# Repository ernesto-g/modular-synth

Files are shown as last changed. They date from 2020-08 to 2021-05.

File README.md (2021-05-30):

# Modular synthesizer

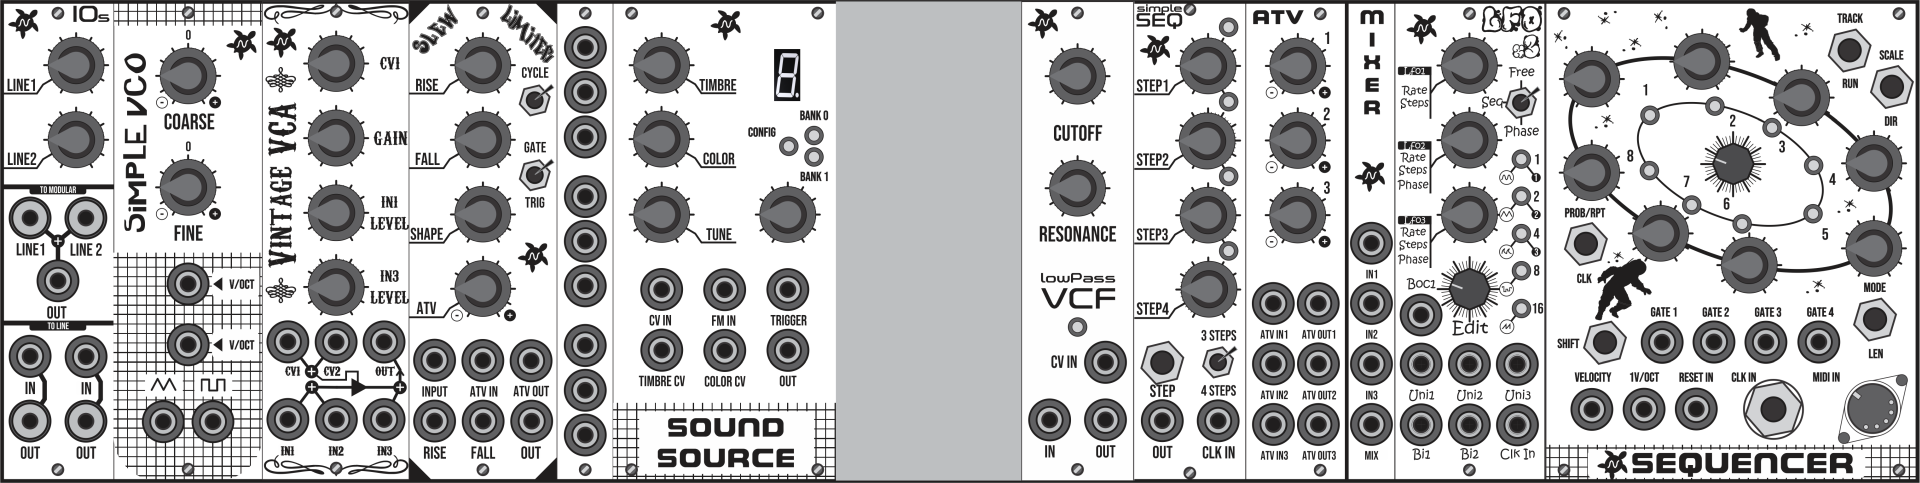
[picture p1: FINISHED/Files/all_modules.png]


Characteristics:

  - Eurorack form factor modules
  - Banana jack connectors
  - 10Vpp audio signals
  - 5V control signals
  - Non standard power connector

# Finished modules

  - [Sequencer](https://github.com/ernesto-g/modular-synth/tree/master/FINISHED/SEQUENCER): 8-step sequencer.
  - [Vintage VCA](https://github.com/ernesto-g/modular-synth/tree/master/FINISHED/VCA): 2-transistor discrete VCA.
  - [Simple VCO](https://github.com/ernesto-g/modular-synth/tree/master/FINISHED/VCO): Triangle and square VCO. 1V/Ocv control voltage.
  - [Slew limiter](https://github.com/ernesto-g/modular-synth/tree/master/FINISHED/SLEW_LIMITER): Slew limiter and LFO
  - [IOs](https://github.com/ernesto-g/modular-synth/tree/master/FINISHED/IOS): Audio line and Eurorack level adapter.
  - [Power Supply](https://github.com/ernesto-g/modular-synth/tree/master/FINISHED/POWER_SUPPLY): Power Supply Board for modules.
  - [Tree](https://github.com/ernesto-g/modular-synth/tree/master/FINISHED/TREE): Banana jack splitter.
  - [Sound Source](https://github.com/ernesto-g/modular-synth/tree/master/FINISHED/SOUND_SOURCE): Macro-oscillator based on Mutable Instruments Braids.
  - [LFOx3](https://github.com/ernesto-g/modular-synth/tree/master/FINISHED/LFOx3): Low frequency oscillator and sequencer.
  - [ATV & Mixer](https://github.com/ernesto-g/modular-synth/tree/master/FINISHED/ATVMixer): Atenuverter X3 and 3-channel mixer.
  - [Simple Sequencer](https://github.com/ernesto-g/modular-synth/tree/master/FINISHED/SIMPLE_SEQUENCER): 4-step sequencer.
  - [Low Pass VCF](https://github.com/ernesto-g/modular-synth/tree/master/FINISHED/VCF): Vactrol VCF.

# Unfinished work

  - Industrial kick
  - Case blueprints
  
# Project structure

Each module has the following structure:

  * Firmware: Microcontroller code (Arduino, Bluepill,etc.)
  * Manual: PDF and DOC file
  * XXXXXXX_modular_PCB: Folder
    * XXXXXXX_modular: Kicad project
    * DIY: PDF files for schematic, PCB and front panel
  * Front Panel Blueprint: Corel Draw files

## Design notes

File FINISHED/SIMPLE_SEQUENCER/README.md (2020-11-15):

# Simple Sequencer: 4-step sequencer

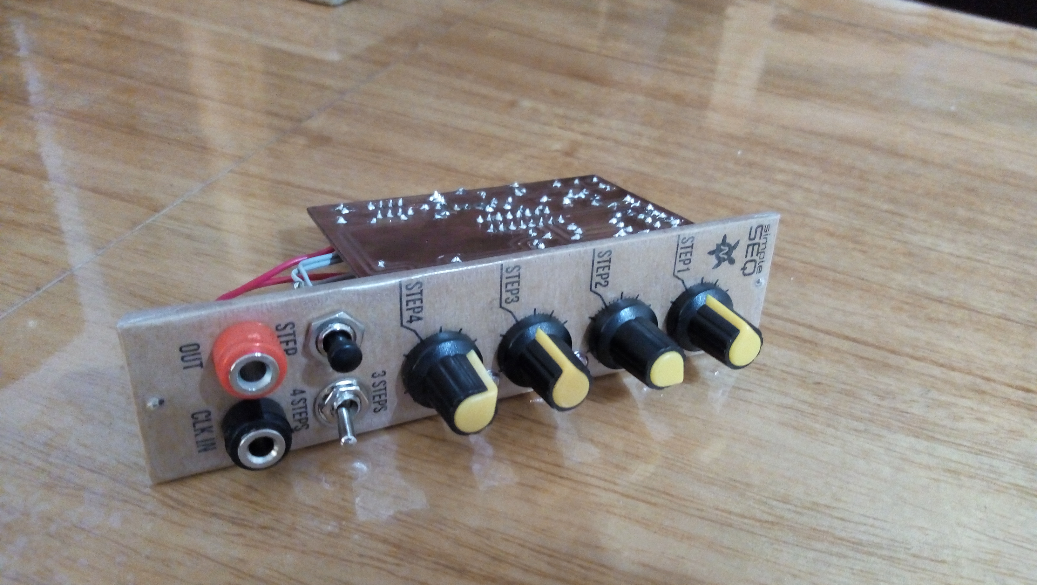
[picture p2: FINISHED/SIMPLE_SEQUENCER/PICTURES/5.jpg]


Characteristics:

  - Format: Eurorack
  - Dimensions: 6HP, 60mm deep
  - 4-step or 3-step selector
  - 0V to 6V output range
  - Manual step advance
  - Clock input 0-12V / 0-5V

# Project structure

  * SIMPLE_SEQUENCER_modular_PCB: Folder
    * SIMPLE_SEQUENCER_modular: Kicad project
    * DIY: PDF files for schematic, PCB and front panel
  * Front Panel Blueprint: Corel Draw files

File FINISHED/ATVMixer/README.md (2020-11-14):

# Atenuverters & 3-channel mixer

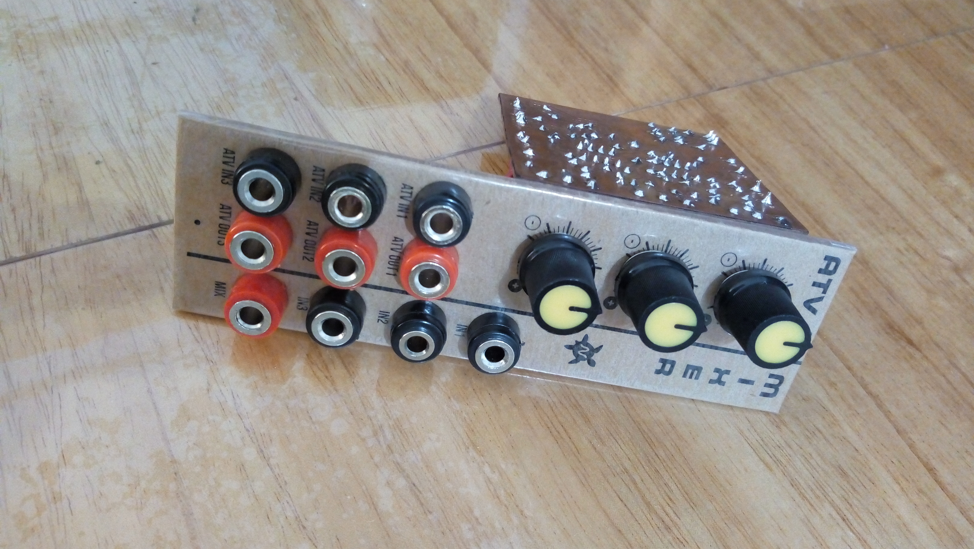
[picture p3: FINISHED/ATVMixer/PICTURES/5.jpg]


Characteristics:

  - Format: Eurorack
  - Dimensions: 8HP, 60mm deep
  - 10Vpp audio signals

# Project structure

  * ATV_AND_MIXER_modular_PCB: Folder
    * ATV_AND_MIXER_modular: Kicad project
    * DIY: PDF files for schematic, PCB and front panel
  * Front Panel Blueprint: Corel Draw files

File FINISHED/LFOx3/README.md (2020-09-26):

# LFOx3: Low frequency oscillator
LFOx3 is a 3 channel digital low frequency oscillator module.

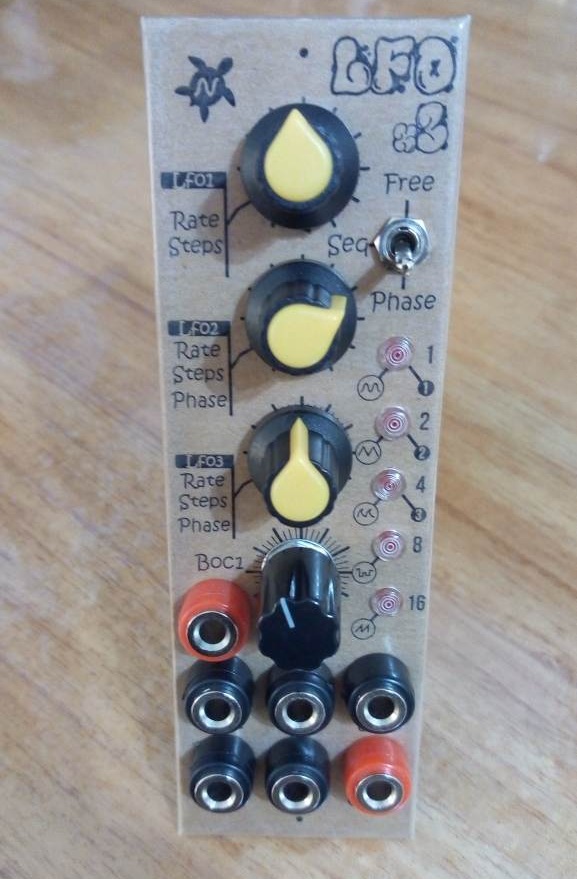
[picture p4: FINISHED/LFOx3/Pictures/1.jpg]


Characteristics:

  - Format: Eurorack
  - Dimensions: 8HP, 60mm deep
  - 10Vpp audio signals
  - 5V control signals
  - 5 Waveforms
  - 105sec to 150Hz range.
  - 10kHz, 8-bit audio processing
  - Beginning of cycle Output.

Download [manual](https://github.com/ernesto-g/modular-synth/raw/master/FINISHED/LFOx3/Manual/LFOx3%20Manual.pdf)   
 
# Project structure

  * Firmware: Code for Arduino nano
  * Manual: PDF and DOC file
  * LFO_modular_PCB: Folder
    * LFO_modular: Kicad project
    * DIY: PDF files for schematic, PCB and front panel
  * Front Panel Blueprint: Corel Draw files

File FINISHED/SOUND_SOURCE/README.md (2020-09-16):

# Sound Source: Macro-oscillator
Sound Source is a voltage-controlled monophonic digital oscillator. Each algorithm is controlled by two continuously variable parameters, TIMBRE and COLOR, both of them voltage controllable.

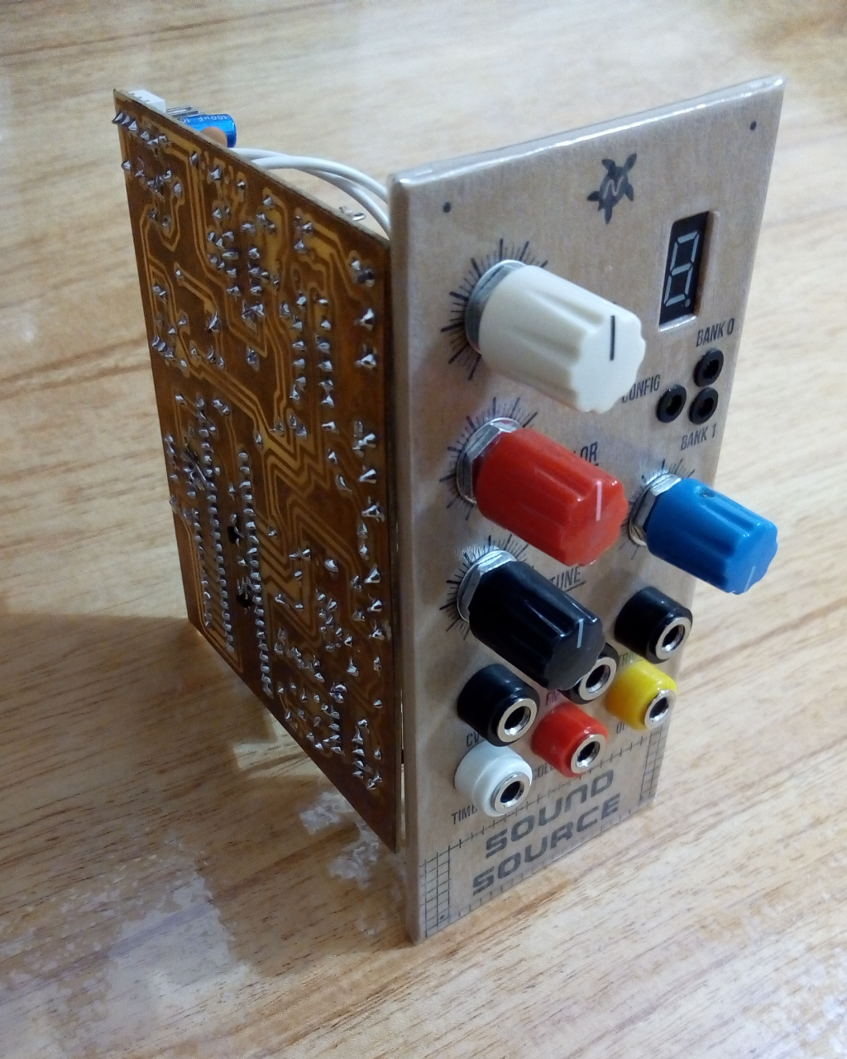
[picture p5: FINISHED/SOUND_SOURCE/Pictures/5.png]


This project is based on Mutable Intruments [Braids](https://mutable-instruments.net/modules/braids). 
The code was adapted for [Blue Pill](https://stm32-base.org/boards/STM32F103C8T6-Blue-Pill.html) microcontroller.

Characteristics:

  - Format: Eurorack
  - Dimensions: 12HP, 80mm deep
  - 10Vpp audio signals
  - 5V control signals
  - 43 Waveforms
  - 96kHz, 8-bit audio processing
  - 12-bit CV capture.

Download [manual](https://github.com/ernesto-g/modular-synth/raw/master/FINISHED/SOUND_SOURCE/Manual/Sound%20Source%20Manual.pdf)   
 
# Project structure

  * Firmware: Code for Blue Pill using ST Cube IDE
  * Manual: PDF and DOC file
  * SOUND_SOURCE_modular_PCB: Folder
    * SOUND_SOURCE_modular: Kicad project
    * DIY: PDF files for schematic, PCB and front panel
  * Front Panel Blueprint: Corel Draw files

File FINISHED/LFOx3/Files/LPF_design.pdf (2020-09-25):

Design Name: Lowpass, Sallen Key, ButterworthPart: Ideal Opamp Order: 2 Stages: 1
Gain: 1 V/V ( 0 dB) | Allowable PassBand Ripple: 1 dB | Passband Frequency: 1 kHz
Corner Frequency Attenuation: -3 dB

## FilterPro Design Report

## Schematic

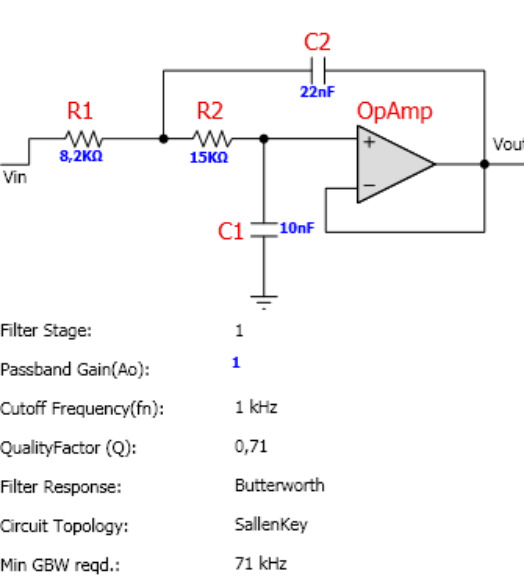
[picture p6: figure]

jueves, 17 de septiembre de 2020 12:45:56 a.m. | -1-

### FilterPro

## Frequency and Phase Responses

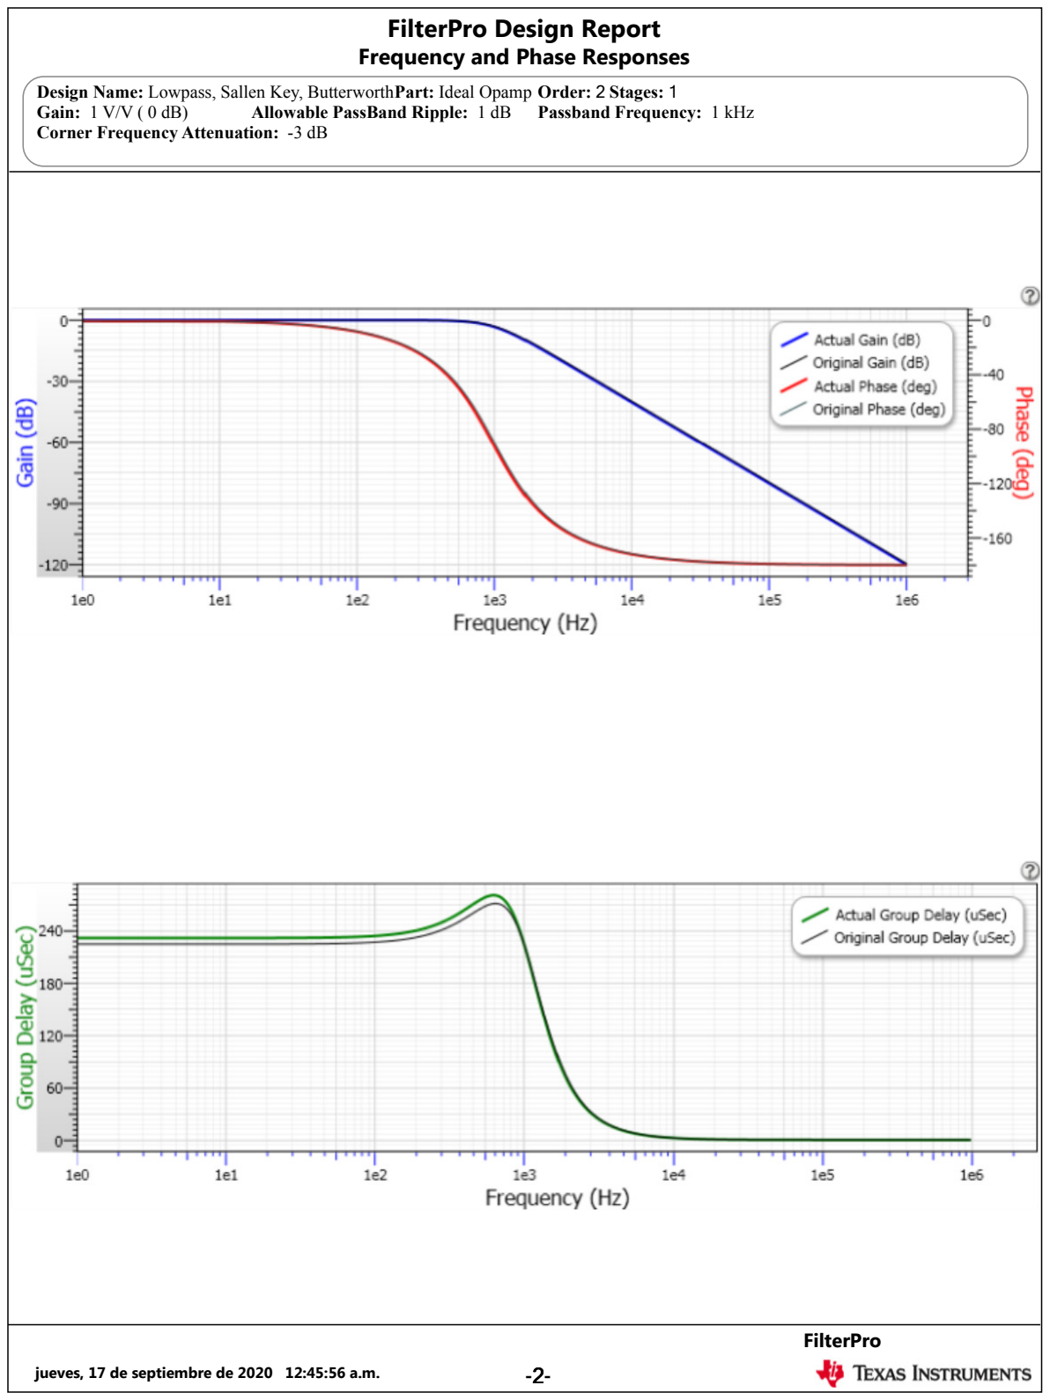
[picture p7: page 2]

Gain: 1 V/V ( 0 dB) | Allowable PassBand Ripple: 1 dB | Passband Frequency: 1 kHz
Corner Frequency Attenuation: -3 dB
jueves, 17 de septiembre de 2020 12:45:56 a.m. | -2-

Gain: 1 V/V ( 0 dB) | Allowable PassBand Ripple: 1 dB | Passband Frequency: 1 kHz
Corner Frequency Attenuation: -3 dB

## Bill of Materials

jueves, 17 de septiembre de 2020 12:45:56 a.m. | -3-
Element ID | Quantity | Part Number | Value | Tolerance | Description | Manufacturer
R1 (Stage 1) | 1 | Standard | 8,2KΩ | E12: 10% | Resistor
R2 (Stage 1) | 1 | Standard | 15KΩ | E12: 10% | Resistor
C1 (Stage 1) | 1 | Standard | 10nF | E6: 20% | Capacitor
C2 (Stage 1) | 1 | Standard | 22nF | E6: 20% | Capacitor
OpAmp (Stage 1) | 1 | Standard | | | Ideal OpAmp

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

## Design Notes

jueves, 17 de septiembre de 2020 12:45:56 a.m. | -4-

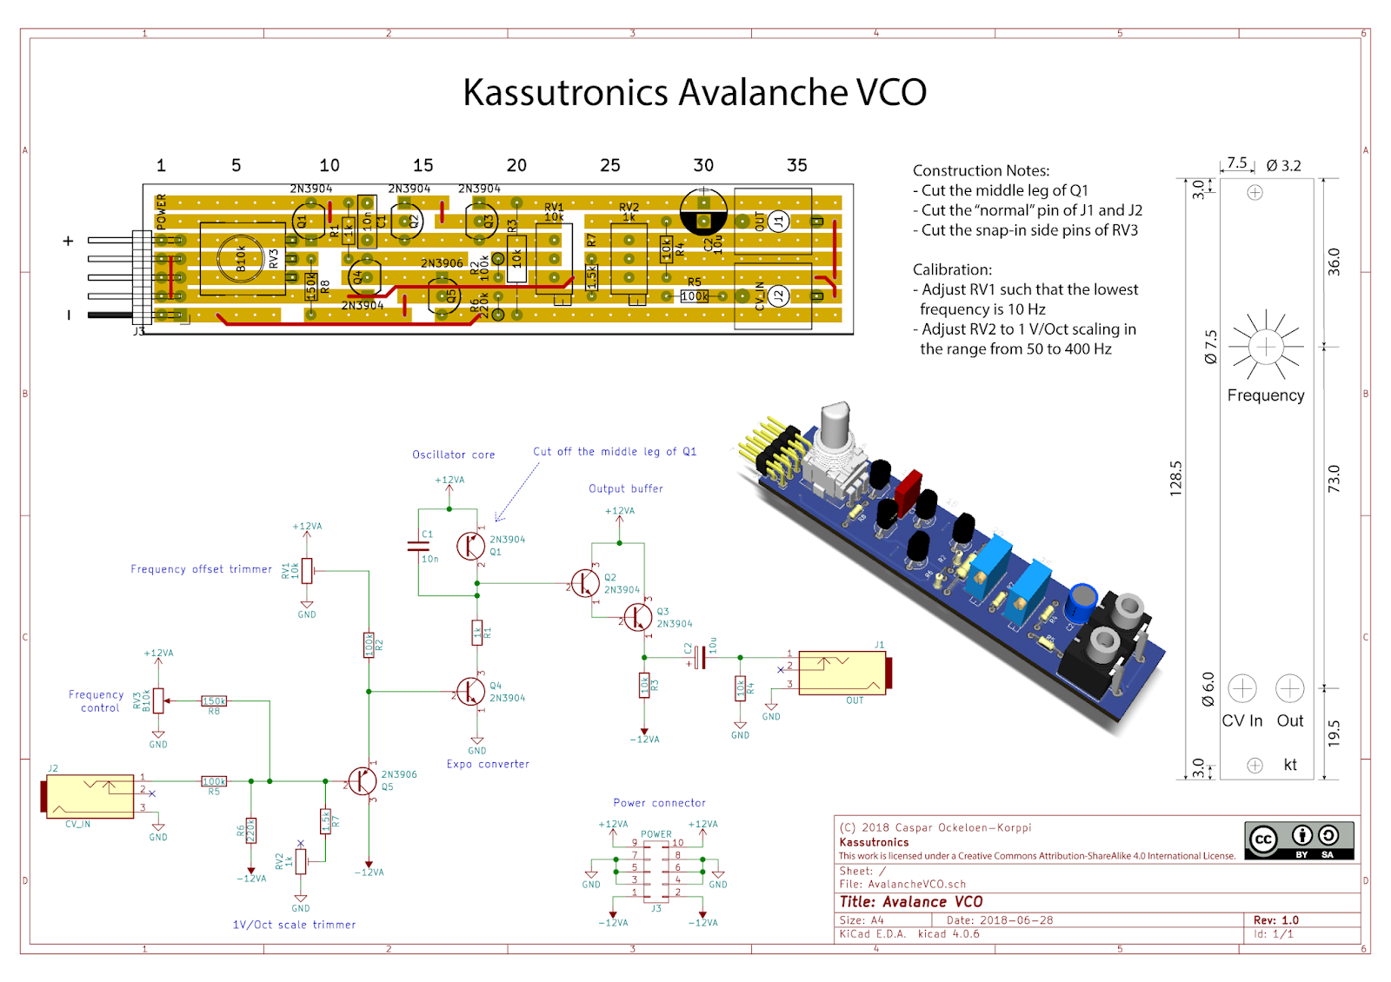
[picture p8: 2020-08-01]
UNFINISHED/INDUSTRIAL_KICK/AvalanceVCOSchematics.png

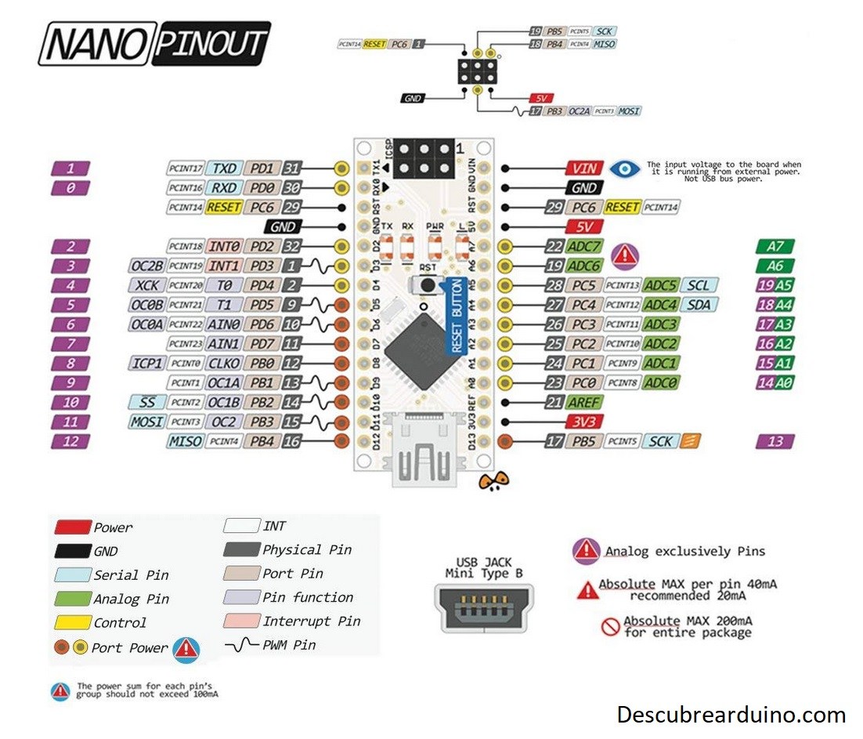
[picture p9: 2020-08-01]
FINISHED/SEQUENCER/SEQUENCER_modular_PCB/SEQUENCER_modular/Datasheets/arduino-nano-pinout.jpg

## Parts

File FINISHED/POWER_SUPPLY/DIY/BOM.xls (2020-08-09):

Reference | Value | Footprint | Qty
> C1, C2 | 2200uFx25V | Capacitors_ThroughHole:CP_Radial_D13.0mm_P5.00mm | 2
> C3, C4 | 220nF | Capacitors_ThroughHole:C_Disc_D11.0mm_W5.0mm_P7.50mm | 2
> C5, C6 | 100nF | Capacitors_ThroughHole:C_Disc_D5.0mm_W2.5mm_P5.00mm | 2
> C7, C8 | 1000uFx16V | Capacitors_ThroughHole:CP_Radial_D8.0mm_P3.50mm | 2
D1 | KBP210 2Amp | Diode_THT:Diode_Bridge_Vishay_KBU | 1
> D2, D3 | 1N4007 | Diode_THT:D_DO-41_SOD81_P10.16mm_Horizontal | 2
J1 | AC INPUT 12+12 1.5A | Terminal_Blocks:TerminalBlock_Altech_AK300-3_P5.00mm | 1
J2 | OUT1 | Connectors_Molex:Molex_KK-6410-03_03x2.54mm_Straight | 1
J3 | OUT2 | Connectors_Molex:Molex_KK-6410-03_03x2.54mm_Straight | 1
J4 | OUT3 | Connectors_Molex:Molex_KK-6410-03_03x2.54mm_Straight | 1
J5 | OUT4 | Connectors_Molex:Molex_KK-6410-03_03x2.54mm_Straight | 1
J6 | OUT5 | Connectors_Molex:Molex_KK-6410-03_03x2.54mm_Straight | 1
J7 | OUT6 | Connectors_Molex:Molex_KK-6410-03_03x2.54mm_Straight | 1
J8 | OUT7 | Connectors_Molex:Molex_KK-6410-03_03x2.54mm_Straight | 1
J9 | OUT8 | Connectors_Molex:Molex_KK-6410-03_03x2.54mm_Straight | 1
U1 | LM7812_TO220 | Package_TO_SOT_THT:TO-220-3_Vertical | 1
U2 | LM7912_TO220 | Package_TO_SOT_THT:TO-220-3_Vertical | 1
 | Heatsink |  | 2

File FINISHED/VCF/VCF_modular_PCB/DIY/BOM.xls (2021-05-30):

 |  |  | Qty
> C1, C3 | 100uFx16V | Capacitors_ThroughHole:CP_Radial_D6.3mm_P2.50mm | 2
> C2, C4 | 100nF | Capacitors_ThroughHole:C_Disc_D4.7mm_W2.5mm_P5.00mm | 2
> C5, C6 | 10nF | Capacitors_ThroughHole:C_Disc_D4.7mm_W2.5mm_P5.00mm | 2
D1 | 1N4148 | Diode_THT:D_DO-35_SOD27_P7.62mm_Horizontal | 1
> D2, D3 | LED | LEDs:LED_D5.0mm_Horizontal_O3.81mm_Z3.0mm | 2
> D4, D5 | Green LED 3mm | LEDs:LED_D3.0mm_FlatTop | 2
D6 | Yellow LED 5mm | LEDs:LED_D5.0mm | 1
J1 | CV IN | Connectors_Molex:Molex_KK-6410-02_02x2.54mm_Straight | 1
J2 | POWER IN | Connectors_Molex:Molex_KK-6410-03_03x2.54mm_Straight | 1
J3 | AUDIO IN | Connectors_Molex:Molex_KK-6410-02_02x2.54mm_Straight | 1
J4 | AUDIO OUT | Connectors_Molex:Molex_KK-6410-02_02x2.54mm_Straight | 1
Q1 | BC547 | Package_TO_SOT_THT:TO-92_Inline_Wide | 1
> R3, R4 | 10k | Resistors_ThroughHole:R_Axial_DIN0204_L3.6mm_D1.6mm_P7.62mm_Horizontal | 2
> R1, R2, R7, R13-R15 | 100k | Resistors_ThroughHole:R_Axial_DIN0204_L3.6mm_D1.6mm_P7.62mm_Horizontal | 6
R8 | 3.3k | Resistors_ThroughHole:R_Axial_DIN0204_L3.6mm_D1.6mm_P7.62mm_Horizontal | 1
> R9, R10 | LDR03 | Opto-Devices:Resistor_LDR_Vertical_5.2x5.2_RM3.5 | 2
> R5, R11 | 22k | Resistors_ThroughHole:R_Axial_DIN0204_L3.6mm_D1.6mm_P7.62mm_Horizontal | 2
> R6, R12 | 1k | Resistors_ThroughHole:R_Axial_DIN0204_L3.6mm_D1.6mm_P7.62mm_Horizontal | 2
R16 | 47k | Resistors_ThroughHole:R_Axial_DIN0204_L3.6mm_D1.6mm_P7.62mm_Horizontal | 1
RV1 | 10k A | Potentiometers:Potentiometer_Piher_PC-16_Single_Vertical | 1
RV2 | 10K | Potentiometers:Potentiometer_Trimmer_ACP_CA6v_Horizontal | 1
RV3 | 100k A | Potentiometers:Potentiometer_Piher_PC-16_Single_Vertical | 1
> U1, U2 | TL072 | Package_DIP:DIP-8_W7.62mm_LongPads | 2
 | Knobs |  | 2
 | Banana jack |  | 3

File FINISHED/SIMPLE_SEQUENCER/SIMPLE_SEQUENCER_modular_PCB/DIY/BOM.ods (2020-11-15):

 |  |  | Qty
> C1, C3 | 100uFx25V | Capacitors_ThroughHole:CP_Radial_D6.3mm_P2.50mm | 2
> C2, C4, C5 | 100nF | Capacitors_ThroughHole:C_Disc_D5.0mm_W2.5mm_P5.00mm | 3
> D1-D5 | 1N4148 | Diode_THT:D_DO-35_SOD27_P7.62mm_Horizontal | 5
J1 | CV_OUT | Connectors_Molex:Molex_KK-6410-02_02x2.54mm_Straight | 1
J2 | LEDS_OUT | Connectors_Molex:Molex_KK-6410-05_05x2.54mm_Straight | 1
J3 | POWER | Connectors_Molex:Molex_KK-6410-03_03x2.54mm_Straight | 1
J4 | CLK_IN | Connectors_Molex:Molex_KK-6410-02_02x2.54mm_Straight | 1
J5 | SW_STEPS | Connectors_Molex:Molex_KK-6410-03_03x2.54mm_Straight | 1
J6 | BTN_STEP | Connectors_Molex:Molex_KK-6410-02_02x2.54mm_Straight | 1
> Q1, Q2 | BC547 | Package_TO_SOT_THT:TO-92_Wide | 2
> R1-R4 | 10k | Resistors_ThroughHole:R_Axial_DIN0204_L3.6mm_D1.6mm_P7.62mm_Horizontal | 4
> R5, R7, R9, R10 | 2.2k | Resistors_ThroughHole:R_Axial_DIN0204_L3.6mm_D1.6mm_P7.62mm_Horizontal | 4
R6 | 100 | Resistors_ThroughHole:R_Axial_DIN0204_L3.6mm_D1.6mm_P7.62mm_Horizontal | 1
> R8, R11-R14 | 100k | Resistors_ThroughHole:R_Axial_DIN0204_L3.6mm_D1.6mm_P7.62mm_Horizontal | 5
> RV1-RV4 | 10K B | Potentiometers:Potentiometer_Piher_PC-16_Single_Vertical | 4
U1 | 4017 | Package_DIP:DIP-16_W7.62mm_LongPads | 1
U3 | LM741 | Package_DIP:DIP-8_W7.62mm_LongPads | 1

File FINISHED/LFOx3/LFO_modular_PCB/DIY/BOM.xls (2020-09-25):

Reference | Value | Footprint | Qty
A1 | Arduino_Nano_v3.x | Module:Arduino_Nano | 1
> C1, C8, C10 | 22nF | Capacitors_ThroughHole:C_Disc_D4.7mm_W2.5mm_P5.00mm | 3
> C3, C6 | 100uFx25V | Capacitors_ThroughHole:CP_Radial_D6.3mm_P2.50mm | 2
> C2, C4, C7 | 100nF | Capacitors_ThroughHole:C_Disc_D4.7mm_W2.5mm_P5.00mm | 3
> C5, C9, C11 | 10nF | Capacitors_ThroughHole:C_Disc_D4.7mm_W2.5mm_P5.00mm | 3
D1 | 1N4148 | Diode_THT:D_DO-35_SOD27_P7.62mm_Horizontal | 1
J1 | POWER | Connectors_Molex:Molex_KK-6410-03_03x2.54mm_Straight | 1
J2 | LFO_0_OUT | Connectors_Molex:Molex_KK-6410-03_03x2.54mm_Straight | 1
J3 | ENCODER | Connectors_Molex:Molex_KK-6410-03_03x2.54mm_Straight | 1
J4 | LFO_1_OUT | Connectors_Molex:Molex_KK-6410-03_03x2.54mm_Straight | 1
J5 | TRIGGER_IN | Connectors_Molex:Molex_KK-6410-02_02x2.54mm_Straight | 1
J6 | LFO_2_OUT | Connectors_Molex:Molex_KK-6410-02_02x2.54mm_Straight | 1
J7 | MODE_SWITCH | Connectors_Molex:Molex_KK-6410-03_03x2.54mm_Straight | 1
J8 | LEDS | Connectors_Molex:Molex_KK-6410-06_06x2.54mm_Straight | 1
J9 | BoC | Connectors_Molex:Molex_KK-6410-03_03x2.54mm_Straight | 1
Q1 | BC547 | Package_TO_SOT_THT:TO-92_HandSolder | 1
> R1, R4, R8, R11, R18 | 100 | Resistors_ThroughHole:R_Axial_DIN0204_L3.6mm_D1.6mm_P7.62mm_Horizontal | 5
> R2, R9, R16 | 8.2k | Resistors_ThroughHole:R_Axial_DIN0204_L3.6mm_D1.6mm_P7.62mm_Horizontal | 3
> R3, R10, R17 | 15k | Resistors_ThroughHole:R_Axial_DIN0204_L3.6mm_D1.6mm_P7.62mm_Horizontal | 3
> R5, R6, R12, R13, R15, R21, R23 | 100k | Resistors_ThroughHole:R_Axial_DIN0204_L3.6mm_D1.6mm_P7.62mm_Horizontal | 7
> R7, R14 | 1k | Resistors_ThroughHole:R_Axial_DIN0204_L3.6mm_D1.6mm_P7.62mm_Horizontal | 2
> R19, R20, R22, R24, R25 | 680 | Resistors_ThroughHole:R_Axial_DIN0204_L3.6mm_D1.6mm_P7.62mm_Horizontal | 5
> RV1, RV5 | 10k | Potentiometers:Potentiometer_Trimmer_ACP_CA6v_Horizontal | 2
> RV2-RV4 | 10K B | Potentiometers:Potentiometer_Piher_PC-16_Single_Vertical | 3
> U1-U3 | TL072 | Package_DIP:DIP-8_W7.62mm_LongPads | 3
 | LED 3mm RED |  | 5
 | Banana Jack |  | 7
 | Encoder w/sw |  | 1
 | Switch SPDT On-Off-On |  | 1

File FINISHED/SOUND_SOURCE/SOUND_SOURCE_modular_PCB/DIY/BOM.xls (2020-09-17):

Reference | Value | Footprint | Qty
BP?1 | BluePill_2 | Bluepill:YAAJ_BluePill | 1
C1 | 3.3nF | Capacitors_ThroughHole:C_Disc_D4.3mm_W1.9mm_P5.00mm | 1
C2 | 22nF | Capacitors_ThroughHole:C_Disc_D4.3mm_W1.9mm_P5.00mm | 1
> C3, C4 | 1nF | Capacitors_ThroughHole:C_Disc_D4.3mm_W1.9mm_P5.00mm | 2
> C6, C10 | 100uFx25V | Capacitors_ThroughHole:CP_Radial_D6.3mm_P2.50mm | 2
> C7, C9, C11, C16 | 100nF | Capacitors_ThroughHole:C_Disc_D4.3mm_W1.9mm_P5.00mm | 4
> C5, C8 | 10uFx25V | Capacitors_ThroughHole:CP_Radial_D5.0mm_P2.50mm | 2
> C12, C13 | 10nF | Capacitors_ThroughHole:C_Disc_D4.3mm_W1.9mm_P5.00mm | 2
> C14, C15 | 220pF | Capacitors_ThroughHole:C_Disc_D4.3mm_W1.9mm_P5.00mm | 2
> D1, D2, D8 | 1N4148 | Diode_THT:D_DO-35_SOD27_P7.62mm_Horizontal | 3
> D3-D5 | LED | LEDs:LED_D3.0mm | 3
> D6, D7 | BAT54A | Package_TO_SOT_SMD:SOT-23 | 2
J1 | AUDIO_OUT | Connectors_Molex:Molex_KK-6410-02_02x2.54mm_Straight | 1
J2 | POWER | Connectors_Molex:Molex_KK-6410-03_03x2.54mm_Straight | 1
J3 | Front Panel conn | Connectors_Molex:Molex_KK-6410-11_11x2.54mm_Straight | 1
J4 | Front panel conn | Connectors_Molex:Molex_KK-6410-11_11x2.54mm_Straight | 1
J5 | CV_INPUT | Connectors_Molex:Molex_KK-6410-02_02x2.54mm_Straight | 1
J6 | FM_INPUT | Connectors_Molex:Molex_KK-6410-02_02x2.54mm_Straight | 1
J7 | TIMBRE CV | Connectors_Molex:Molex_KK-6410-02_02x2.54mm_Straight | 1
J8 | COLOR CV | Connectors_Molex:Molex_KK-6410-02_02x2.54mm_Straight | 1
J10 | GATE_INPUT | Connectors_Molex:Molex_KK-6410-02_02x2.54mm_Straight | 1
Q1 | BC547 | Package_TO_SOT_THT:TO-92_Inline | 1
R1 | 6.8k | Resistors_ThroughHole:R_Axial_DIN0204_L3.6mm_D1.6mm_P7.62mm_Horizontal | 1
> R2, R34, R35 | 2.2k | Resistors_ThroughHole:R_Axial_DIN0204_L3.6mm_D1.6mm_P7.62mm_Horizontal | 3
> R3, R4 | 3.9k | Resistors_ThroughHole:R_Axial_DIN0204_L3.6mm_D1.6mm_P7.62mm_Horizontal | 2
R5 | 1.2k | Resistors_ThroughHole:R_Axial_DIN0204_L3.6mm_D1.6mm_P7.62mm_Horizontal | 1
R6 | 1.8k | Resistors_ThroughHole:R_Axial_DIN0204_L3.6mm_D1.6mm_P7.62mm_Horizontal | 1
R7 | 100 | Resistors_ThroughHole:R_Axial_DIN0204_L3.6mm_D1.6mm_P7.62mm_Horizontal | 1
> R8, R17, R18, R26, R27, R36 | 100k | Resistors_ThroughHole:R_Axial_DIN0204_L3.6mm_D1.6mm_P7.62mm_Horizontal | 6
> R9-R16, R19, R20, R23 | 680 | Resistors_ThroughHole:R_Axial_DIN0204_L3.6mm_D1.6mm_P7.62mm_Horizontal | 11
> R21, R22 | 33k | Resistors_ThroughHole:R_Axial_DIN0204_L3.6mm_D1.6mm_P7.62mm_Horizontal | 2
> R24, R25, R28-R31 | 47k | Resistors_ThroughHole:R_Axial_DIN0204_L3.6mm_D1.6mm_P7.62mm_Horizontal | 6
> R32, R33 | 220k | Resistors_ThroughHole:R_Axial_DIN0204_L3.6mm_D1.6mm_P7.62mm_Horizontal | 2
> RV1-RV3 | 10kB | Potentiometers:Potentiometer_Piher_PC-16_Single_Vertical | 3
SW1 | Rotary_Encoder_Switch | Rotary_Encoder:RotaryEncoder_Alps_EC11E-Switch_Vertical_H20mm | 1
> U1, U6 | TL072 | Package_DIP:DIP-8_W7.62mm_Socket_LongPads | 2
U2 | L7805 | Package_TO_SOT_THT:TO-220-3_Vertical | 1
U3 | HDSP-7401 | Display_7Segment:HDSP-7401 | 1
U4 | 74HC595 | Housings_SOIC:SOIC-16_3.9x9.9mm_Pitch1.27mm | 1
U5 | MCP6022* | Package_DIP:DIP-8_W7.62mm_Socket_LongPads | 1
U7 | AT24CS04-MAHM | Package_DIP:DIP-8_W7.62mm_Socket_LongPads | 1
 | *alternatives: MCP33202 or any rail to rail dual oamp

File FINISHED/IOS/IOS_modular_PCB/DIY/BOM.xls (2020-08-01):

Reference | Value | Footprint | Qty
> C1, C6 | 1uF | Capacitors_ThroughHole:CP_Radial_D4.0mm_P2.00mm | 2
> C2, C4 | 100uF x25V | Capacitors_ThroughHole:CP_Radial_D6.3mm_P2.50mm | 2
> C3, C5 | 100nF | Capacitors_ThroughHole:C_Disc_D4.3mm_W1.9mm_P5.00mm | 2
J1 | MODULAR OUT | Connectors_Molex:Molex_KK-6410-02_02x2.54mm_Straight | 1
J2 | LINE IN 1 | Connectors_Molex:Molex_KK-6410-02_02x2.54mm_Straight | 1
J3 | POWER IN | Connectors_Molex:Molex_KK-6410-03_03x2.54mm_Straight | 1
J4 | LINE IN 2 | Connectors_Molex:Molex_KK-6410-02_02x2.54mm_Straight | 1
J5 | MODULAR IN 1 | Connectors_Molex:Molex_KK-6410-02_02x2.54mm_Straight | 1
J6 | LINE OUT 1 | Connectors_Molex:Molex_KK-6410-02_02x2.54mm_Straight | 1
J7 | MODULAR IN 2 | Connectors_Molex:Molex_KK-6410-02_02x2.54mm_Straight | 1
J8 | LINE OUT 2 | Connectors_Molex:Molex_KK-6410-02_02x2.54mm_Straight | 1
> R1, R8, R11 | 100 | Resistors_ThroughHole:R_Axial_DIN0204_L3.6mm_D1.6mm_P7.62mm_Horizontal | 3
R2 | 10k | Resistors_ThroughHole:R_Axial_DIN0204_L3.6mm_D1.6mm_P7.62mm_Horizontal | 1
> R3, R6, R7, R10 | 100k | Resistors_ThroughHole:R_Axial_DIN0204_L3.6mm_D1.6mm_P7.62mm_Horizontal | 4
> R4, R9, R12 | 47k | Resistors_ThroughHole:R_Axial_DIN0204_L3.6mm_D1.6mm_P7.62mm_Horizontal | 3
R5 | 220k | Resistors_ThroughHole:R_Axial_DIN0204_L3.6mm_D1.6mm_P7.62mm_Horizontal | 1
> RV1, RV2 | 10K A | Potentiometers:Potentiometer_Piher_PC-16_Single_Vertical | 2
> U1, U2 | TL072 | Package_DIP:DIP-8_W7.62mm_Socket_LongPads | 2

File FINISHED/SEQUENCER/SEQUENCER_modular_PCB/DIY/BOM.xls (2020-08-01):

Reference | Value | Footprint | Qty
A1 | Arduino_Nano_v3.x | Module:Arduino_Nano | 1
> C1, C3, C4 | 100uFx25v | Capacitors_ThroughHole:CP_Radial_D5.0mm_P2.50mm | 3
> C2, C5-C8 | 100nF | Capacitors_ThroughHole:C_Disc_D5.1mm_W3.2mm_P5.00mm | 5
C9 | 10uFx16v | Capacitors_ThroughHole:CP_Radial_D5.0mm_P2.50mm | 1
> D1-D3 | 1N4148 | Diode_THT:D_DO-35_SOD27_P7.62mm_Horizontal | 3
IC1 | LM336 | Package_TO_SOT_THT:TO-92_HandSolder | 1
J1 | POWER | Connectors_Molex:Molex_KK-41791-03_03x3.96mm_Straight | 1
J2 | EXT_RST_IN | Connectors_Molex:Molex_KK-41791-02_02x3.96mm_Straight | 1
J3 | LEDS | Connectors_Molex:Molex_KK-6410-09_09x2.54mm_Straight | 1
J4 | EXT_CLK_IN | Connectors_Molex:Molex_KK-41791-02_02x3.96mm_Straight | 1
J5 | MIDI_IN | Connectors_Molex:Molex_KK-41791-02_02x3.96mm_Straight | 1
J6 | ENCODER | Connectors_Molex:Molex_KK-41791-03_03x3.96mm_Straight | 1
J7 | GATE_OUTS | Connectors_Molex:Molex_KK-6410-05_05x2.54mm_Straight | 1
J8 | SWITCHES | Connectors_Molex:Molex_KK-6410-05_05x2.54mm_Straight | 1
J9 | POTS | Connectors_Molex:Molex_KK-6410-06_06x2.54mm_Straight | 1
J10 | AFTER_TOUCH_OUT | Connectors_Molex:Molex_KK-41791-02_02x3.96mm_Straight | 1
J11 | POTS_POWER | Connectors_Molex:Molex_KK-41791-02_02x3.96mm_Straight | 1
J12 | CV_OUT | Connectors_Molex:Molex_KK-41791-02_02x3.96mm_Straight | 1
> Q1, Q2 | BC547 | Package_TO_SOT_THT:TO-92_HandSolder | 2
> R3-R10 | 470 | Resistors_ThroughHole:R_Axial_DIN0204_L3.6mm_D1.6mm_P7.62mm_Horizontal | 8
> R1, R11 | 100k | Resistors_ThroughHole:R_Axial_DIN0204_L3.6mm_D1.6mm_P7.62mm_Horizontal | 2
R12 | 220 | Resistors_ThroughHole:R_Axial_DIN0204_L3.6mm_D1.6mm_P7.62mm_Horizontal | 1
> R15-R18 | 1k | Resistors_ThroughHole:R_Axial_DIN0204_L3.6mm_D1.6mm_P7.62mm_Horizontal | 4
R20 | 5.6k | Resistors_ThroughHole:R_Axial_DIN0204_L3.6mm_D1.6mm_P7.62mm_Horizontal | 1
> R21, R22 | 2.2k | Resistors_ThroughHole:R_Axial_DIN0204_L3.6mm_D1.6mm_P7.62mm_Horizontal | 2
> R14, R19, R23 | 22k | Resistors_ThroughHole:R_Axial_DIN0204_L3.6mm_D1.6mm_P7.62mm_Horizontal | 3
> R24, R25 | 100 | Resistors_ThroughHole:R_Axial_DIN0204_L3.6mm_D1.6mm_P7.62mm_Horizontal | 2
> RV1, RV2 | 10k B | Potentiometers:Potentiometer_Piher_PC-16_Single_Vertical | 2
U1 | 74HC595 | Package_DIP:DIP-16_W7.62mm_LongPads | 1
U2 | 4N28 | Package_DIP:DIP-6_W7.62mm | 1
U3 | MCP4725xxx-xCH | Package_TO_SOT_SMD:SOT-23-6 | 1
U4 | CD4051B | Package_DIP:DIP-16_W7.62mm_LongPads | 1
U5 | LM358 | Package_DIP:DIP-8_W7.62mm_LongPads | 1
U6 | OP07 | Package_DIP:DIP-8_W7.62mm_LongPads | 1
RV3 | 10K | PRESET | 1

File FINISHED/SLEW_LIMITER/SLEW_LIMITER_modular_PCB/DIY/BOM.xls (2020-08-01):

Reference | Value | Footprint | Qty
> C3, C4 | 100uFx25V | Capacitors_ThroughHole:CP_Radial_D6.3mm_P2.50mm | 2
C5 | 470pF | Capacitors_ThroughHole:C_Disc_D5.0mm_W2.5mm_P5.00mm | 1
> C1, C2, C6 | 100nF | Capacitors_ThroughHole:C_Disc_D5.0mm_W2.5mm_P5.00mm | 3
> D1-D4 | 1N4148 | Diode_THT:D_DO-35_SOD27_P7.62mm_Horizontal | 4
J1 | POWER | Connectors_Molex:Molex_KK-6410-03_03x2.54mm_Straight | 1
J2 | CV_FALL | Connectors_Molex:Molex_KK-6410-02_02x2.54mm_Straight | 1
J3 | ATV_IN | Connectors_Molex:Molex_KK-6410-02_02x2.54mm_Straight | 1
J4 | GATE/TRIGGER IN | Connectors_Molex:Molex_KK-6410-02_02x2.54mm_Straight | 1
J5 | Gate/Trigger Switch | Connectors_Molex:Molex_KK-6410-03_03x2.54mm_Straight | 1
J6 | CV_RISE | Connectors_Molex:Molex_KK-6410-02_02x2.54mm_Straight | 1
J7 | ATV_OUT | Connectors_Molex:Molex_KK-6410-02_02x2.54mm_Straight | 1
J8 | Cycle Switch | Connectors_Molex:Molex_KK-6410-02_02x2.54mm_Straight | 1
J9 | OUT | Connectors_Molex:Molex_KK-6410-02_02x2.54mm_Straight | 1
> Q3, Q5 | BC557 | Package_TO_SOT_THT:TO-92L_HandSolder | 2
> Q1, Q2, Q4, Q6 | BC547 | Package_TO_SOT_THT:TO-92L_HandSolder | 4
> R3, R5-R7, R14, R17, R24-R26 | 100k | Resistors_ThroughHole:R_Axial_DIN0204_L3.6mm_D1.6mm_P7.62mm_Horizontal | 9
R8 | 100 | Resistors_ThroughHole:R_Axial_DIN0204_L3.6mm_D1.6mm_P7.62mm_Horizontal | 1
> R1, R2, R9, R10, R12, R13, R15, R16, R18, R20, R28-R30 | 47k | Resistors_ThroughHole:R_Axial_DIN0204_L3.6mm_D1.6mm_P7.62mm_Horizontal | 13
> R19, R22 | 3.3k | Resistors_ThroughHole:R_Axial_DIN0204_L3.6mm_D1.6mm_P7.62mm_Horizontal | 2
> R4, R11, R21 | 1k | Resistors_ThroughHole:R_Axial_DIN0204_L3.6mm_D1.6mm_P7.62mm_Horizontal | 3
R23 | 470k | Resistors_ThroughHole:R_Axial_DIN0204_L3.6mm_D1.6mm_P7.62mm_Horizontal | 1
R27 | 1M | Resistors_ThroughHole:R_Axial_DIN0204_L3.6mm_D1.6mm_P7.62mm_Horizontal | 1
> RV1, RV3 | 10k A | Potentiometers:Potentiometer_Piher_PC-16_Single_Vertical | 2
> RV2, RV4 | 100k B | Potentiometers:Potentiometer_Piher_PC-16_Single_Vertical | 2
> U1-U3 | TL072 | Package_DIP:DIP-8_W7.62mm_Socket_LongPads | 3
 |  | Banana Jack | 6
 |  | Switch | 2
 |  | Knob | 4

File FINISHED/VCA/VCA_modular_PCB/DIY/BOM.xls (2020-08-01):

Reference | Value | Footprint | Qty
C1-C3 | 100nF | Capacitors_ThroughHole:C_Disc_D4.3mm_W1.9mm_P5.00mm | 3
C1 | 100nF | Capacitors_ThroughHole:C_Disc_D4.3mm_W1.9mm_P5.00mm | 1
C2 | 100nF | Capacitors_ThroughHole:C_Disc_D4.3mm_W1.9mm_P5.00mm | 1
C3 | 100nF | Capacitors_ThroughHole:C_Disc_D4.3mm_W1.9mm_P5.00mm | 1
> C4, C5 | 100uFx25V | Capacitors_ThroughHole:CP_Radial_D6.3mm_P2.50mm | 2
C6 | 10pF | Capacitors_ThroughHole:C_Disc_D4.3mm_W1.9mm_P5.00mm | 1
> C7, C8 | 22nF | Capacitors_ThroughHole:C_Disc_D4.3mm_W1.9mm_P5.00mm | 2
C9 | 1uFx25V | Capacitors_ThroughHole:CP_Radial_D6.3mm_P2.50mm | 1
J1 | Audio_IN2_VCA | Connectors_Molex:Molex_KK-6410-02_02x2.54mm_Straight | 1
J2 | Audio_IN1_VCA | Connectors_Molex:Molex_KK-6410-02_02x2.54mm_Straight | 1
J3 | CV1_IN | Connectors_Molex:Molex_KK-6410-02_02x2.54mm_Straight | 1
J4 | CV2_IN | Connectors_Molex:Molex_KK-6410-02_02x2.54mm_Straight | 1
J5 | Audio_IN3 | Connectors_Molex:Molex_KK-6410-02_02x2.54mm_Straight | 1
J6 | POWER | Connectors_Molex:Molex_KK-6410-03_03x2.54mm_Straight | 1
J7 | Audio_OUT | Connectors_Molex:Molex_KK-6410-02_02x2.54mm_Straight | 1
> Q1-Q3 | BC547 | Package_TO_SOT_THT:TO-92_Inline | 3
R1 | 47k | Resistors_ThroughHole:R_Axial_DIN0204_L3.6mm_D1.6mm_P7.62mm_Horizontal | 1
R2 | 4.7k | Resistors_ThroughHole:R_Axial_DIN0204_L3.6mm_D1.6mm_P7.62mm_Horizontal | 1
> R4, R5 | 68k | Resistors_ThroughHole:R_Axial_DIN0204_L3.6mm_D1.6mm_P7.62mm_Horizontal | 2
> R6-R8, R20, R21, R23, R24 | 220k | Resistors_ThroughHole:R_Axial_DIN0204_L3.6mm_D1.6mm_P7.62mm_Horizontal | 7
> R3, R9, R10, R28 | 100k | Resistors_ThroughHole:R_Axial_DIN0204_L3.6mm_D1.6mm_P7.62mm_Horizontal | 4
R12 | 470 | Resistors_ThroughHole:R_Axial_DIN0204_L3.6mm_D1.6mm_P7.62mm_Horizontal | 1
> R11, R13, R25 | 10k | Resistors_ThroughHole:R_Axial_DIN0204_L3.6mm_D1.6mm_P7.62mm_Horizontal | 3
R15 | 33k | Resistors_ThroughHole:R_Axial_DIN0204_L3.6mm_D1.6mm_P7.62mm_Horizontal | 1
R16 | 15k | Resistors_ThroughHole:R_Axial_DIN0204_L3.6mm_D1.6mm_P7.62mm_Horizontal | 1
> R14, R17 | 15k 1% | Resistors_ThroughHole:R_Axial_DIN0204_L3.6mm_D1.6mm_P7.62mm_Horizontal | 2
> R18, R19 | 10k 1% | Resistors_ThroughHole:R_Axial_DIN0204_L3.6mm_D1.6mm_P7.62mm_Horizontal | 2
R22 | 330k | Resistors_ThroughHole:R_Axial_DIN0204_L3.6mm_D1.6mm_P7.62mm_Horizontal | 1
R26 | 22k | Resistors_ThroughHole:R_Axial_DIN0204_L3.6mm_D1.6mm_P7.62mm_Horizontal | 1
R27 | 100 | Resistors_ThroughHole:R_Axial_DIN0204_L3.6mm_D1.6mm_P7.62mm_Horizontal | 1
> RV1, RV4 | 50K B | Potentiometers:Potentiometer_Piher_PC-16_Single_Vertical | 2
RV2 | 100K B | Potentiometers:Potentiometer_Piher_PC-16_Single_Vertical | 1
RV3 | 10K B | Potentiometers:Potentiometer_Piher_PC-16_Single_Vertical | 1
RV5 | 50k | Potentiometers:Potentiometer_Trimmer_ACP_CA6v_Horizontal | 1
RV6 | 10k | Potentiometers:Potentiometer_Trimmer_ACP_CA6v_Horizontal | 1
RV7 | 100k | Potentiometers:Potentiometer_Trimmer_ACP_CA6v_Horizontal | 1
> U1, U2 | TL072 | Package_DIP:DIP-8_W7.62mm_LongPads | 2

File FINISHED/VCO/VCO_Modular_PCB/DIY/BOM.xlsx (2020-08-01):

C1 | 100pF | Capacitors_ThroughHole:C_Disc_D5.0mm_W2.5mm_P5.00mm | 1
C2 | 6.8nF Polyester | Capacitors_ThroughHole:C_Disc_D5.0mm_W2.5mm_P5.00mm | 1
C3 | 1nF | Capacitors_ThroughHole:C_Disc_D5.0mm_W2.5mm_P5.00mm | 1
> C4, C5 | 100uFx25V | Capacitors_ThroughHole:CP_Radial_D8.0mm_P3.50mm | 2
> C6-C9 | 100nF | Capacitors_ThroughHole:C_Disc_D7.5mm_W2.5mm_P5.00mm | 4
> D1, D2 | 1N4148 | Diodes_ThroughHole:D_DO-41_SOD81_P7.62mm_Horizontal | 2
J1 | CV1 | Connectors_Molex:Molex_KK-6410-02_02x2.54mm_Straight | 1
J2 | CV2 | Connectors_Molex:Molex_KK-6410-02_02x2.54mm_Straight | 1
J3 | Triangle Output | Connectors_Molex:Molex_KK-6410-02_02x2.54mm_Straight | 1
J4 | Square Output | Connectors_Molex:Molex_KK-6410-02_02x2.54mm_Straight | 1
J5 | POWER | Connectors_Molex:Molex_KK-6410-03_03x2.54mm_Straight | 1
> Q1, Q3 | 2N3904 | Package_TO_SOT_THT:TO-92L_HandSolder | 2
Q2 | BC547 | Package_TO_SOT_THT:TO-92L_HandSolder | 1
> R1, R2 | 220k | Resistors_ThroughHole:R_Axial_DIN0207_L6.3mm_D2.5mm_P7.62mm_Horizontal | 2
> R6, R11 | 1M | Resistors_ThroughHole:R_Axial_DIN0207_L6.3mm_D2.5mm_P7.62mm_Horizontal | 2
> R7, R8 | 100k 1% | Resistors_ThroughHole:R_Axial_DIN0207_L6.3mm_D2.5mm_P7.62mm_Horizontal | 2
R9 | 2k2 | Resistors_ThroughHole:R_Axial_DIN0207_L6.3mm_D2.5mm_P7.62mm_Horizontal | 1
R10 | 470 | Resistors_ThroughHole:R_Axial_DIN0207_L6.3mm_D2.5mm_P7.62mm_Horizontal | 1
> R13, R17, R19, R24, R25, R28, R30 | 10k | Resistors_ThroughHole:R_Axial_DIN0207_L6.3mm_D2.5mm_P7.62mm_Horizontal | 7
> R12, R14, R15 | 10k 1% | Resistors_ThroughHole:R_Axial_DIN0207_L6.3mm_D2.5mm_P7.62mm_Horizontal | 3
R20 | 82k | Resistors_ThroughHole:R_Axial_DIN0207_L6.3mm_D2.5mm_P7.62mm_Horizontal | 1
> R5, R21 | 100k | Resistors_ThroughHole:R_Axial_DIN0207_L6.3mm_D2.5mm_P7.62mm_Horizontal | 2
> R23, R27 | 22k | Resistors_ThroughHole:R_Axial_DIN0207_L6.3mm_D2.5mm_P7.62mm_Horizontal | 2
> R3, R4, R22, R26 | 47k | Resistors_ThroughHole:R_Axial_DIN0207_L6.3mm_D2.5mm_P7.62mm_Horizontal | 4
> R16, R29 | 4.7k | Resistors_ThroughHole:R_Axial_DIN0207_L6.3mm_D2.5mm_P7.62mm_Horizontal | 2
> R18, R31, R32 | 1k | Resistors_ThroughHole:R_Axial_DIN0207_L6.3mm_D2.5mm_P7.62mm_Horizontal | 3
> RV1, RV2 | 100kB | Potentiometers:Potentiometer_Alps_RK163_Single_Vertical | 2
RV3 | TRIM 500 | Potentiometers:Potentiometer_Trimmer_Bourns_3266Y | 1
RV4 | TRIM 100k 25T | Potentiometers:Potentiometer_Trimmer_Bourns_3296W | 1
RV5 | TRIM 10k | Potentiometers:Potentiometer_Trimmer_ACP_CA6v_Horizontal | 1
RV6 | TRIM 10k | Potentiometers:Potentiometer_Trimmer_Bourns_3296Y | 1
RV7 | TRIM 20k 25T | Potentiometers:Potentiometer_Trimmer_Bourns_3296W | 1
> U1-U4 | TL072 | Housings_DIP:DIP-8_W7.62mm_LongPads | 4
 | Banana jack |  | 4

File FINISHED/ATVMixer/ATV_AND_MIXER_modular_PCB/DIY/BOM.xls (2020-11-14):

Reference | Value | Qty
> C1, C3 | 100uFx25V | 2
> C2, C4 | 100nF | 2
J1 | ATV1_IN | 1
J2 | POWER | 1
J3 | ATV1_OUT | 1
J4 | ATV2_IN | 1
J5 | ATV2_OUT | 1
J6 | MIXER_IN | 1
J7 | MIXER_OUT | 1
J8 | ATV3_IN | 1
J9 | ATV3_OUT | 1
> R1, R5, R6, R8, R12-R14, R16-R18, R22 | 100k | 11
> R3, R9, R10, R20 | 100 | 4
> R2, R4, R7, R11, R15, R19, R21 | 47k | 7
> RV1-RV3 | 100K B | 3
> U1, U2 | TL072 | 2
Banana jack |  | 10
Knobs |  | 3

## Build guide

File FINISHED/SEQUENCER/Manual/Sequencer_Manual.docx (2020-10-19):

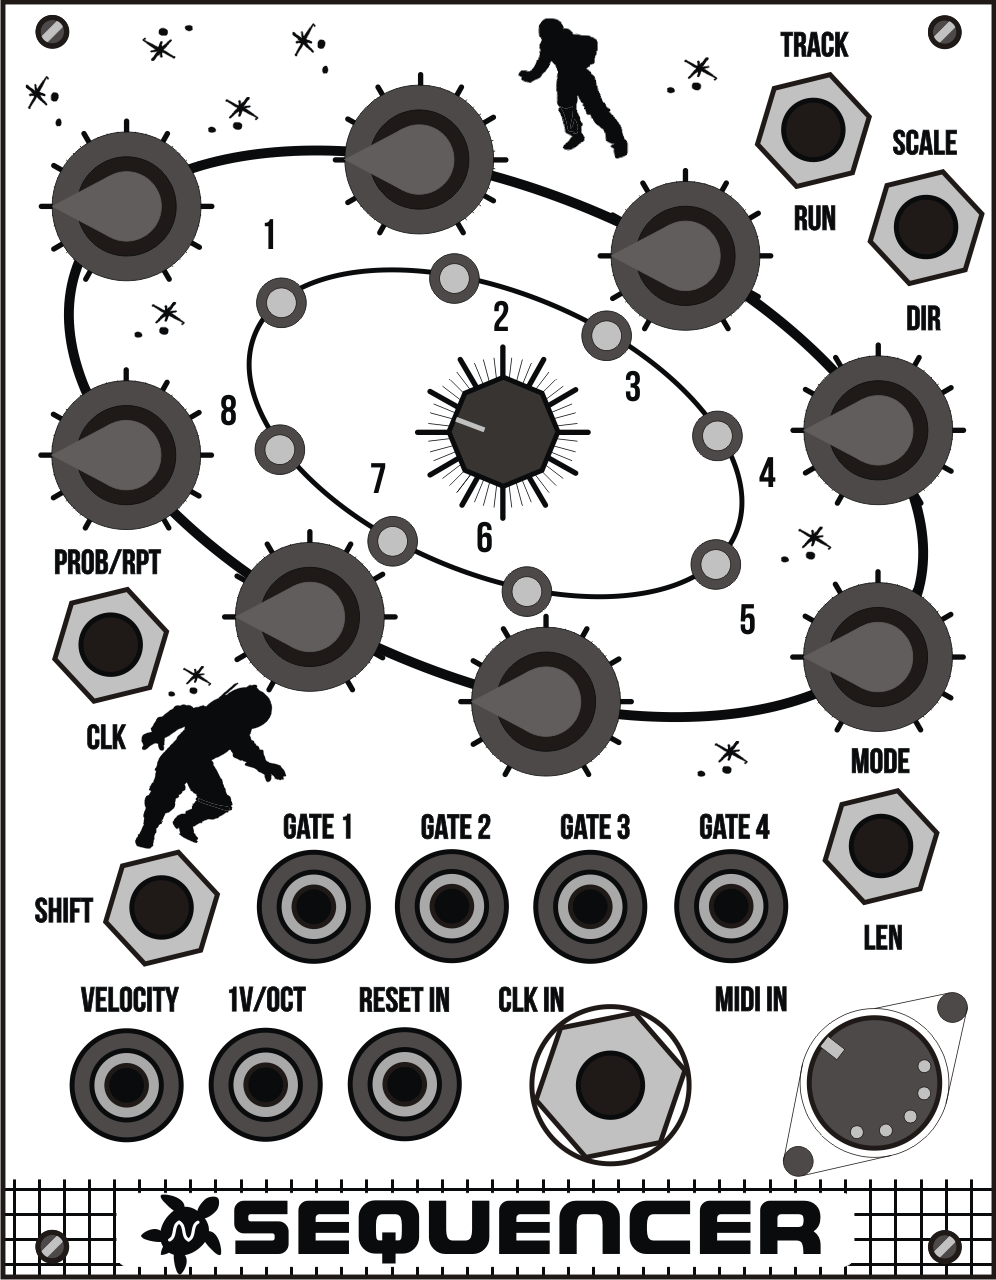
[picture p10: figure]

User’s

MANUAL

SEQUENCER

July 2020

Revision Sheet

Release No. | Date | Revision Description
Rev. 0 | 04/07/2020 | User’s Manual First revision
Rev. 1 | 19/10/2020 | New Feature: Root note for scale. Voltage table information.

USER'S MANUAL

TABLE OF CONTENTS

Page #

1.0 GENERAL INFORMATION

# A. GENERAL INFORMATION

## 1.1 Specifications

- Format: Eurorack
- Dimensions: 20HP, 70mm deep
- Internal and external signals: 0-5V Logic I/O
- Max Current:
  1. +12V: 100mA
  2. -12V: 1mA
  3. +5V: n/a

## 1.2 Description

The Sequencer is a 4-track 8-step sequencer. Each track correlates with it's own sequencer (4 independent sequencers that share the same base clock). Each track has a gate output and track 1 has an extra 1V/OCT output and Velocity output.

Each step of a sequencer can be programmed with Probability and Repeats. An extra feature of Notes exists for track 1 (using 1V/OCT output).

There is also a randomization feature for Probability and Notes. Track parameters for Scales, Sequence Direction (Forward, Reverse, Pendulum and Random), Sequence Length and Clock Division are all accessible and independent for each track.

Features

- 4 Modes:
  - Mode 1: Sequencer with 3 tracks using gate output + 1 track using gate and 1V/OCT output
  - Mode 2: Sequencer with 3 tracks using gate output + 1 track controlled by MIDI input using gate, 1V/OCT and Velocity outputs
  - Mode 3: Sequencer with 3 tracks using gate output + 1 track Arpeggiator controlled by MIDI.
  - Mode 4: Sequencer with 3 tracks using gate output + 1 track in Euclidean mode using gate and 1V/OCT output.
- 8 steps per track.
- Play/Stop Function
- Divide clock per track.
- Adjust sequence length per track.
- Program Notes for Track 1.
- 8 Quantized Scale Options (Micro Tuning, Chromatic, Major, Minor, Blues, Phrygian, Lydian, Dorian Scales)
- Program clock tempo between 30 and 600 bpm.
- 7 Sequencer Direction Modes (Forward, Reverse, Pendulum, Stagger, Skip, Random, Random With Rest)
- CLK IN: Clock input.
- RESET IN: Configure this input to reset sequence to step 1 or hold the current step.
- Probability: Control the probability of a step outputting a gate.
- Repeat: Control the amount of repeats per step.
- 8 leds to indicate current step and options selected.
- 0 to 5 volt Analog CV Output
- 5 volt Gate Output

2.0 GETTING STARTED

# B. GETTING STARTED

## 2.1 Overview

Buttons:Use

these combined with

Shift button

to select an option

Note/Prob knobs:Use

this knobs to set the

step note in track 1

or prob/rpt for

tracks 2 to 4

Leds:Indicate current

Step and options.

Encoder:Use

this encoder to set the

base time

Reset and CLK IN:

0V – 12V tolerant

Gate outputs:Connect

your patch cables

from these outputs

to other module gate,

trigger or CV inputs.

MIDI INPUT:

Connect a keyboard

using MIDI and use

the sequencer as a

MIDI to CV converter

Analog outputs:

Connect

your patch cables

from these outputs

to other module

CV inputs.

Leds: Leds show the active step in the sequence in modes 1 to 3. In Euclidean mode leds mark the steps where a gate event will occur.

Gate outputs: These outputs go HI 50% of the step’s time. Each output is managed by a “Track”. There are 4 tracks. Track 1 has 3 outputs: 1V/oct, Velocity and GATE1, Track 2 to 4 have one output each, GATE2, GATE3 and GATE4.

Clock In: A clock signal can be connected to this input to control the sequencer BPM. External clock mode must be configured.

Reset In: A pulse signal can be connected to this input and allows to reset the sequencer step. There are several modes with different behaviours (back to step 1, hold current step, etc.)

MIDI IN: In mode 2 and 3, MIDI input can be used to connect a MIDI keyboard. MIDI channel is configurable from 0 to 8. In mode 2, the analog outputs 1v/oct and Velocity will respond to MIDI key events. In mode 3 (arpeggiator) pressed keys will be arpeggiated using the current BPM (one key per step).

Velocity output: In mode 1, 3 and 4 velocity is always 5V. In mode 2, velocity value is controlled by MIDI key pressed event.

1V/OCT output: In mode 1 and 4, this output (0V to 5V) is controlled by the step’s knobs and can be different for each step. In mode 2 and 3, the output value will correspond to the MIDI key pressed.

Encoder: Encoder allows to change BMP from 30 to 600. In mode 4 can be combined with “Shift” button to change the amount of enabled steps in euclidean mode, and combined with “Dir” to rotate the enabled steps also in euclidean mode.

Buttons: These buttons can be used while the sequence is playing to change parameters and select the current track. They can be used also to configure settings in the device.

Knobs: Knobs are used to set a parameter for each step. There is one knob for each step.

## 2.2 Usage

Button Shift: Pressing this button in combination with another, allows the user to select the option notated over to button.

Button Run: Press run to start the sequence in all four tracks. Press again to stop it. Sequence will always start at step 1.

Button Track (Shift+Run): Press track to see and change the current active track. The parameters affected by the knobs will affect just the current track parameters.

Usage: Press Track once. The current track will be displayed on the leds. If led 1 is blinking, then the current track is one. If led 2 is blinking then the current track is two. Press Track again to change the value (1 to 4). For finishing the setting, wait 3 seconds and the leds will display the current step again.

Button Dir: Press Dir to see and change the current track direction for the steps.

Usage: Press Dir once. The current direction will be displayed on the leds. Press Dir again to change the value (1 to 7). For finishing the setting, wait 3 seconds and the leds will display the current step again.

- #1 Forward - The sequence steps between steps 1 to 8 in order.
- #2 Reverse - The sequence steps between steps 8 to 1 in reverse order.
- #3 Pendulum - The sequence steps between steps 1 to 8 then reverses direction. Steps 1 and 8 are triggered twice to create a 16 step sequence length.
- #4 Stagger - The sequence steps between steps 1 to 8 in order with a 25% chance that the sequence will stagger back 1 step or ahead 2 steps. This creates a sequence that staggers back and forth as it steps between steps. Step 1 may be staggered past on any given cycle.
- #5 Skip - The sequence steps between steps 1 to 8 in order, skipping a subsequent step each cycle. This creates a complex sequence of 56 steps. The first time through step 1 is skipped, the second time through step 2 is skipped, and so on.
- #6 Random 1 - The active step is selected randomly.
- #7 Random 2 - The active step is selected randomly. Includes silence step.

Button Scale (Shift+Dir): Press Scale to see and change the scale used to select notes with the knobs (only available for track 1).

Usage: Press Scale once. The current scale will be displayed on the leds. Press Scale again to change the value (1 to 8). For finishing the setting, wait 3 seconds and the leds will display the current step again.

- #1 Micro - Fine grained access to note intervals.
- #2 Chromatic - 12 step scale with note intervals at 0, 1, 2, 3, 4, 5, 6, 7, 8, 9, 10, 11.
- #3 Major - 7 step scale with note intervals at 0, 2, 4, 5, 7, 9, 11.
- #4 Minor - 7 steps per octave scale with note intervals at 0, 2, 3, 5, 7, 8, 10.
- #5 Blues - 6 steps per octave scale with note intervals at 0, 3, 5, 6, 7, 10.
- #6 Phrygian - 7 steps per octave scale with note intervals at 0, 1, 3, 5, 7, 8, 10.
- #7 Lydian - 7 steps per octave scale with note intervals at 0, 2, 4, 6, 7, 9, 11.
- #8 Dorian - 7 steps per octave scale with note intervals at 0, 2, 3, 5, 7, 9, 10.

Button Len: Press Len to see and change the sequence’s length for the current track.

Usage: Press Len once. The current length will be displayed on the leds. Press Len again to change the value (1 to 8). For finishing the setting, wait 3 seconds and the leds will display the current step again.

Button Clk: Press Clk to see and change the base clock division for the current track.

Usage: Press Clk once. The current clock division will be displayed on the leds. Press Clk again to change the value (one means %1, two means %2, eight means %8). For finishing the setting, wait 3 seconds and the leds will display the current step again.

Button Mode (Shift+Len): Press Mode to see and change the current mode for the device.

Usage: Press Mode once. The current mode will be displayed on the leds. Press Mode again to change the value (1 to 4). For finishing the setting, wait 3 seconds and the leds will display the current step again.

- #1 Mode 1:
  - Knobs will set Notes for track 1
  - Knobs will set Probability and Repetition for tracks 2 to 4
- #2 Mode 2:
  - Track 1 is disabled. MIDI key events will control Gate1, Velocity and 1V/OCT outputs
  - Knobs will set Probability and Repetition for tracks 2 to 4.
- #3 Mode 3:
  - Arpeggiator mode. Track 1 is disabled. MIDI key events will control Gate1, Velocity and 1V/OCT outputs generating arpeggios.
  - Knobs will set Probability and Repetition for tracks 2 to 4.
- #4 Mode 4:
  - Track 1 is in Euclidean mode. Knobs will set Notes. Use the encoder to change euclidean parameters.
  - Knobs will set Probability and Repetition for tracks 2 to 4.

Button Prob/Rpt (Shift+Clk): Press Prob/Rpt to see and select between Probability and Repetitions mode. In probability mode, knobs will set probability for the gate to get HI. In repetitions mode, knobs will set the amount of times a gate goes HI for each step slot time.

Usage: Press Prob/rpt once. The current mode will be displayed on the leds. Press the button again to change the value (#1 means Probability mode, #2 means Repetitions mode). For finishing the setting, wait 3 seconds and the leds will display the current step again.

    Knobs: Each knob selects a different parameter for each step in a track.
  - For track 1, knobs select the note played through 1V/OCT output in each step.
  - For tracks 2 to 4, knobs select the probability (0% to 100%) for the gate to go HI or the amount of times (repetitions) the gate will go HI (1 to 8)

## 2.3 Configuration

### Clock source selection

Press Clk button for 5 seconds. Leds will display the current clock source:

- # 1 Internal
- # 2 External (The sequence will advance when a pulse appears in the CLK input)

Press the button again to change the value (1 or 2). For finishing the setting, wait 3 seconds and the leds will display the current step again.

### MIDI channel selection

Press Run button for 5 seconds. Leds will display the current MIDI channel. (channel 0 is represented by all leds off). Press the button again to change the value (0 to 8). For finishing the setting, wait 3 seconds and the leds will display the current step again.

### Reset input behavior selection

Press Len button for 5 seconds. Leds will display the current Reset input mode:

- # 1: Step go back to step 1 when a reset signal goes high.
- # 2: Sequence will hold the current step while the reset input is high
- # 3: The sequence direction reverses when the incoming reset signal goes high. The sequence returns to normal when the gate goes high a second time. If the direction mode is set to random 1 or random 2, reverse mode enables the sequence to play forward.

Press the button again to change the value (1 to 3). For finishing the setting, wait 3 seconds and the leds will display the current step again.

### Root note selection

Press Dir button for 5 seconds. Leds will display the current root note:

LED Number | Note
1 | C
2 | D
3 | E
4 | F
5 | G
6 | A
7 | B
8 | Means sharp (#). This led will be ON for C, D, F, G and A

Press the button again to change the value (FROM C to B). For example, if led 4 and 8 are ON, that means F#. For finishing the setting, wait 4 seconds and the leds will display the current step again.

## 2.4 Voltage table for 1v/Oct output

Key | MIDI | 1v Octave [V]
C2 | 36 | 0,0833
C#2 | 37 | 0,1667
D2 | 38 | 0,25
D#2 | 39 | 0,3333
E2 | 40 | 0,4167
F2 | 41 | 0,5
F#2 | 42 | 0,5833
G2 | 43 | 0,6667
G#2 | 44 | 0,75
A2 | 45 | 0,8333
A#2 | 46 | 0,9167
B2 | 47 | 1
C3 | 48 | 1,0833
C#3 | 49 | 1,1667
D3 | 50 | 1,25
D#3 | 51 | 1,3333
E3 | 52 | 1,4167
F3 | 53 | 1,5
F#3 | 54 | 1,5833
G3 | 55 | 1,6667
G#3 | 56 | 1,75
A3 | 57 | 1,8333
A#3 | 58 | 1,9167
B3 | 59 | 2
C4 | 60 | 2,0833
C#4 | 61 | 2,1667
D4 | 62 | 2,25
D#4 | 63 | 2,3333
E4 | 64 | 2,4167
F4 | 65 | 2,5
F#4 | 66 | 2,5833
G4 | 67 | 2,6667
G#4 | 68 | 2,75
A4 | 69 | 2,8333
A#4 | 70 | 2,9167
B4 | 71 | 3
C5 | 72 | 3,0833
C#5 | 73 | 3,1667
D5 | 74 | 3,25
D#5 | 75 | 3,3333
E5 | 76 | 3,4167
F5 | 77 | 3,5
F#5 | 78 | 3,5833
G5 | 79 | 3,6667
G#5 | 80 | 3,75
A5 | 81 | 3,8333
A#5 | 82 | 3,9167
B5 | 83 | 4
C6 | 84 | 4,0833
C#6 | 85 | 4,1667
D6 | 86 | 4,25
D#6 | 87 | 4,3333
E6 | 88 | 4,4167
F6 | 89 | 4,5
F#6 | 90 | 4,5833
G6 | 91 | 4,6667
G#6 | 92 | 4,75
A6 | 93 | 4,8333
A#6 | 94 | 4,9167
B6 | 95 | 5

User’s Manual Page i

User’s Manual Page iii

User’s Manual Page 2

User’s Manual

User’s Manual Page 7

Revision Sheet

1.0 General Information

2.0 Getting started

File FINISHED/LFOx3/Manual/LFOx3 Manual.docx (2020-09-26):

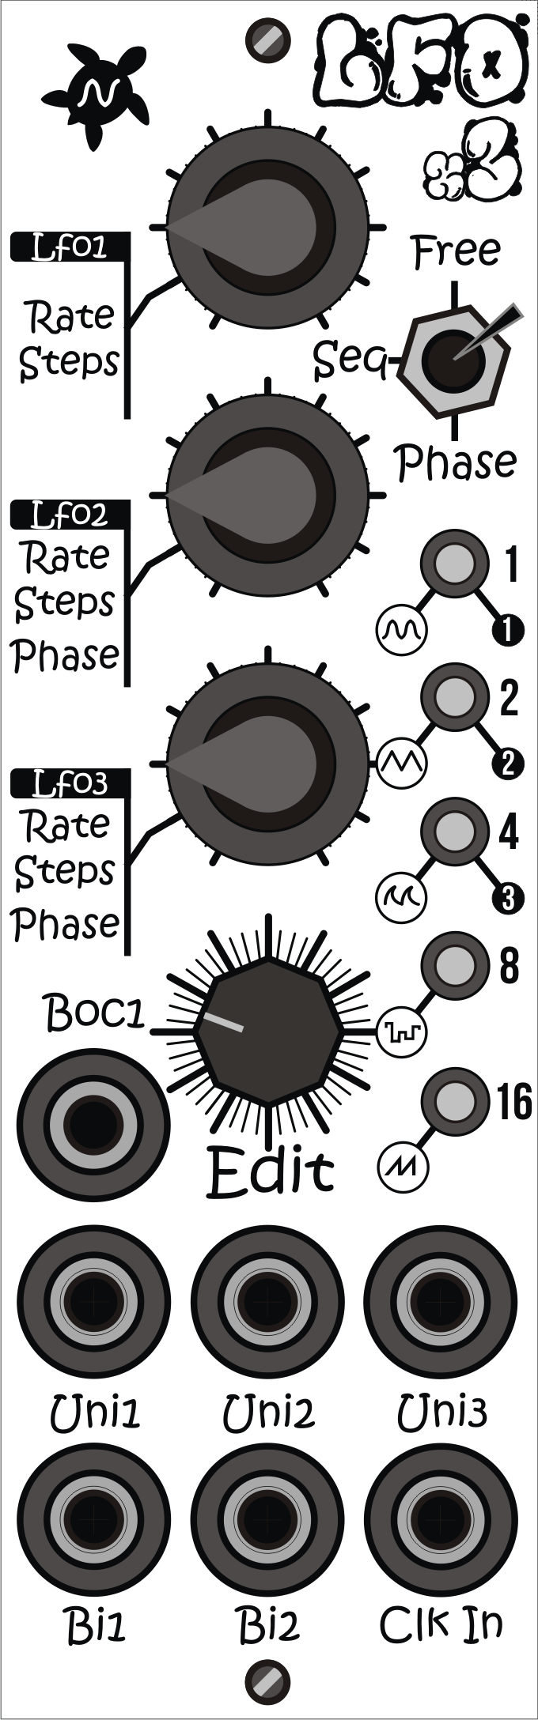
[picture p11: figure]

User’s

MANUAL

LFO x 3

September 2020

Revision Sheet

Release No. | Date | Revision Description
Rev. 0 | 26/09/2020 | User’s Manual First revision

USER'S MANUAL

TABLE OF CONTENTS

Page #

1.0 GENERAL INFORMATION

# A. GENERAL INFORMATION

## 1.1 Specifications

- Format: Eurorack
- Dimensions: 8HP, 60mm deep
- Internal and external signals: 0-5V Logic I/O
- Max Current:
  1. +12V: 50mA
  2. -12V: 1mA
  3. +5V: n/a

## 1.2 Description

LFOx3 is a 3 channel digital low frequency oscillator module. Each LFO channel can be used independently or in one of three synchronized modes. The total frequency range spans from 105 seconds up to 150Hz.

In Sequencer mode, each channel outputs a sequence of a controllable number of steps sampled from the selected waveform. If saw waveform is selected, the output will increase with each Clock Input signal. If noise waveform is selected, the output can be used as a sample&hold for generating random values.

Features

- 5 Waveforms
  - Sine
  - Triangular
  - Exponential
  - Noise
  - Saw
- 8 bit output signal @ 10Khz sampling rate.
- Digital Clock Input.
- Beginning of cycle Output.
- Unipolar and Bipolar Outputs.
- Three modes:
  - Free mode: Select a waveform and rate for each channel.
  - Phase mode: Select a rate for 3 channels and the phase shift for channel 2 and 3.
  - Sequencer mode: Select an amount of steps (1 to 31) for each channel. Rate is given by Clock input.

2.0 GETTING STARTED

# B. GETTING STARTED

## 2.1 Overview

Mode switch: Selects the current mode.

Knob LFO1:In free mode, sets the Channel 1 frequency. In Phase mode, sets the main frequency. In Sequencer mode, sets the number of steps for channel 1.

Leds:Indicate selected channel, waveform type and steps.

Knob LFO2:In free mode, sets the Channel 2 frequency. In Phase mode, sets phase shift. In Sequencer mode, sets the number of steps for channel 2.

Unipolar outputs:

Unipolar outputs (0V..5V) for channel 1,2 and 3.

Knob LFO3:In free mode, sets the Channel 3 frequency. In Phase mode, sets phase shift. In Sequencer mode, sets the number of steps for channel 3.

BoC1:Outputs a pulse each time the channel 1 signal starts its cycle.

Clk In:

In free and phase mode, syncs the output signals. In Sequencer mode advances the current step for all channels.

Bipolar outputs:

Bipolar outputs (-5V..5V) for channel 1 and 2.

Edit:

Encoder for selecting channel and waveform.

## 2.2 Usage

Encoder: Move the encoder to select a channel. Leds will indicate 1, 2 or 3. Then click the encoder to activate the selected channel. The current waveform will be shown. Move the encoder to change the waveform. Click the encoder to go back to channel selection.

### FREE mode

Move the switch to “Free” position. The frequency for each channel can be set by Knob1, 2 and 3. The waveform for each channel can be set by the encoder.

All channels can by synced using the Clk input.

BoC output will trigger at the beginning of channel 1 cycle.

### Phase mode

Move the switch to “Phase” position. The main frequency for all channels can be set by Knob1. The waveform for each channel can be set by the encoder.

Use knob2 to set the phase shift between channel 1 and 2 from 0 to 180º.

Use knob3 to set the phase shift between channel 1 and 3 from 0 to 180º.

Channel 1 can by synced using the Clk input.

BoC output will trigger at the beginning of channel 1 cycle.

### Sequencer mode

Move the switch to “Seq” position. The main frequency for all channels will depends on Clk input signal and the amount of steps selected for each channel.

Use knob1 to set the amount of steps for channel 1, knob2 for channel 2 and knob3 for channel 3.

The selected waveform will be sampled with that amount of steps each time a Clk in signal arrives.

BoC output will trigger at the beginning of channel 1 cycle.

User’s Manual Page i

User’s Manual Page iii

User’s Manual Page 2

User’s Manual

Revision Sheet

1.0 General Information

2.0 Getting started

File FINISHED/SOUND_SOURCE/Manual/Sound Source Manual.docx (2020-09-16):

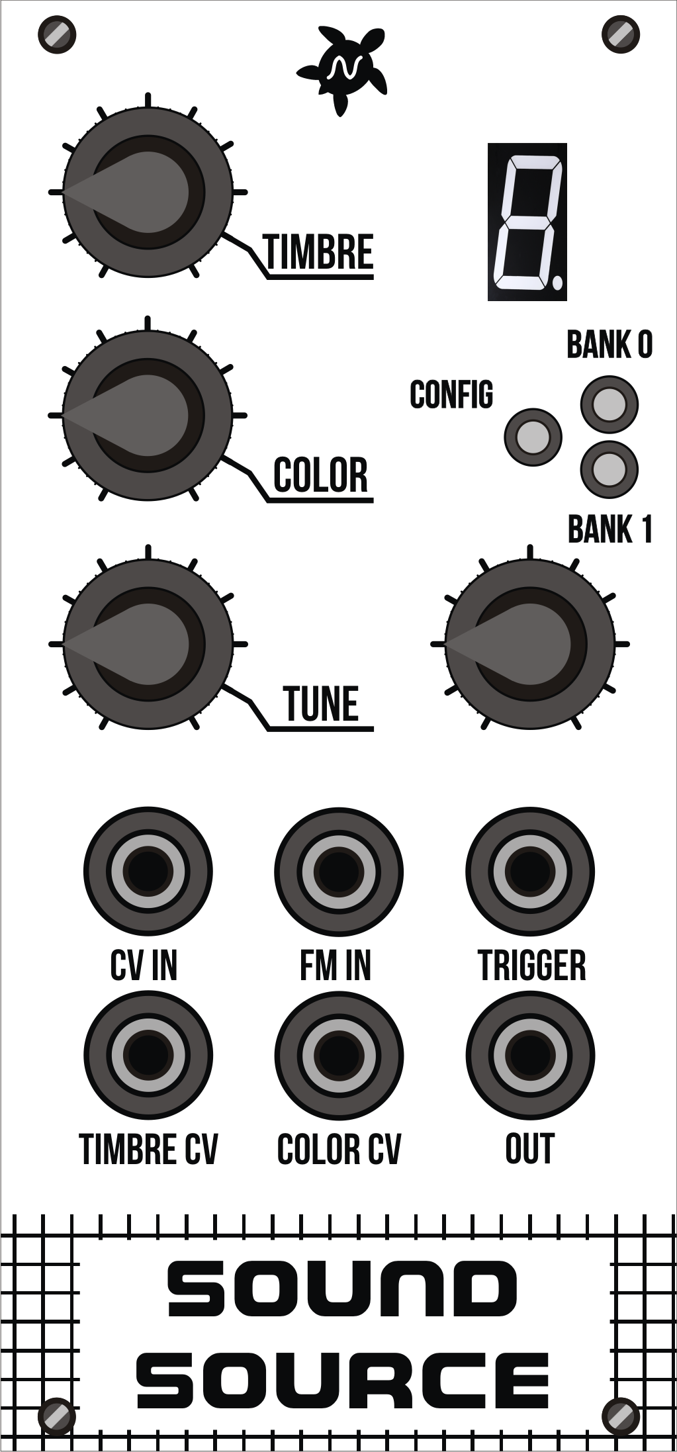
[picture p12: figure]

User’s

MANUAL

SOUND SOURCE

September 2020

Revision Sheet

Release No. | Date | Revision Description
Rev. 0 | 13/09/2020 | User’s Manual First revision

USER'S MANUAL

TABLE OF CONTENTS

Page #

1.0 GENERAL INFORMATION

# A. GENERAL INFORMATION

## 1.1 Specifications

- Format: Eurorack
- Dimensions: 12HP, 80mm deep
- Internal and external signals: 0-5V Logic I/O
- Max Current:
  1. +12V: 100mA
  2. -12V: 1mA
  3. +5V: n/a

## 1.2 Description

Sound Source is a voltage-controlled monophonic digital oscillator. Each algorithm is controlled by two continuously variable parameters, TIMBRE and COLOR, both of them voltage controllable. Instead of being directly assigned to the intricate details of the synthesis algorithm, they work as meta-parameters going through all the sweet spots. Very often, these parameters simultaneously affect several dimensions of timbre, creating very complex movements which would be hard to generate with a traditional setup.

This project is based on Mutable Intruments “Braids” https://mutable-instruments.net/modules/braids

Features

- 43 Waveforms
- Quantizer on the CV-input with a large selection of scales.
- Analog VCO-style linear detuning of higher frequencies.
- Built-in AD envelope, assignable to the oscillator frequency, the COLOR and TIMBRE parameters, and to the amplitude.
- META mode enabling CV-controlled model selection with the FM input.
- 12-bit CV capture.
- 96kHz, 8-bit audio processing (some algorithms are 2x or 4x oversampled).
- Waveforms
  - CS-80 style sawtooth with a notch.
  - Continuously variable morphing between triangle, sawtooth, square and pulse, with character control.
  - Square/sawtooth with pulse width control.
  - Triangle to sine morphing, with wavefolder.
  - Band-limited dual pulse train, with detuning.
  - Dual square or sawtooth oscillator with hard sync.
  - Triple saw, square, triangle or sine.
  - Stack of three ring-modulated sine waves.
  - Swarm of seven sawtooth waves.
  - Comb-filtered sawtooth wave
  - Circuit-bent sawtooth generator with sample rate reduction and bit toggling.
  - Direct synthesis of filtered waveforms, casio CZ style.
  - Low-fi or hi-fi vowel/formant synthesis.
  - Harmonic oscillator.
  - FM with various feedback paths.
  - Plucked string (Karplus Strong).
  - Bowed string.
  - Reed and flute.
  - Bell and metallic drum.
  - 808 bass drum, cymbal noise and snare drum.
  - Noise processed by a tuned multimode filter.
  - Noise processed by a dual BP filter.
  - Clocked digital noise.
  - Cloud of sinusoidal grains.
  - Particle synthesis.

2.0 GETTING STARTED

# B. GETTING STARTED

## 2.1 Overview

Display:Show the current waveform.

TIMBRE:This parameter controls the main evolution and motion of the timbre.

Leds:Indicate current

bank of waveforms. Config led is on in configuration mode.

COLOR:This knob controls a second dimension of sound.

Encoder:

Use this encoder to set the current waveform and enter into config mode.

CV IN:1V/Oct frequency CV input.

TUNE:Fine frequency control.

TRIGGER INPUT:

Triggers the internal AD module and oscillator.

FM IN:

Frequency modulation CV input. Positive only.

TIMBRE & COLOR CV INPUTS:

Control voltages for the Timbre and Color parameters.

Timbre & Color inputs: Control voltages for the Timbre and Color parameters. A value of 0V corresponds to the maximum position of the knob. A value of +5V corresponds to the minimum position of the knob. This CV is offset by the current position of the knob.

Trigger Input: This trigger input serves three purposes. 1) Physical models need to be “excited” by an impulse on this input to give birth to a sound. 2) The other models will treat the trigger as a reset signal, bringing the phase of the oscillator(s) to 0. 3) This input can also be used to trigger an internal AD envelope applied to the parameters of your choice, to create sound animation and attacks without an external envelope module.

OUT: Signal output. Loudness is model-dependent - for example a pure sine wave is always at maximum amplitude; while a ring-modulated sine-wave will have peaks and valleys due to amplitude modulation, and will thus sound quieter.

## 2.2 Usage

Encoder: Move the encoder to select a waveform. The config led will turn on. Then click the encoder to activate the selected waveform. The config led will turn off.

Waveforms for Bank 0

Code | Waveform
0 | CSAW
1 | MORPH
2 | SAW_SQUARE
3 | SINE_TRIANGLE
4 | BUZZ
5 | SQUARE_SUB
6 | SAW_SUB
7 | SQUARE_SYNC
8 | SAW_SYNC
9 | TRIPLE_SAW
A | TRIPLE_SQUARE
B | TRIPLE_TRIANGLE
C | TRIPLE_SINE
D | RING_MOD
E | SAW_SWARM
F | SAW_COMB
G | TOY
H | DIGITAL_FILTER_LP
I | DIGITAL_FILTER_PK
J | DIGITAL_FILTER_BP

Waveforms for Bank 1

Code | Waveform
0 | DIGITAL_FILTER_HP
1 | VOSIM
2 | VOWEL
3 | VOWEL_FOF
4 | HARMONICS
5 | FM
6 | FEEDBACK_FM
7 | CHAOTIC_FEEDBACK_FM
8 | PLUCKED
9 | BOWED
A | BLOWN
B | FLUTED
C | STRUCK_BELL
D | STRUCK_DRUM
E | KICK
F | CYMBAL
G | SNARE
H | FILTERED_NOISE
I | TWIN_PEAKS_NOISE
J | CLOCKED_NOISE
L | GRANULAR_CLOUD
O | PARTICLE_NOISE
P | DIGITAL_MODULATION

TUNE: Move Tune knob to right or left to detune the oscillator. The dot in the display will show the current state is “detuned”. Move it to the center to set to calibrated frequency again.

Dot On: Uncalibrated

Dot Off: Calibrated.

## 2.3 Configuration

### Enter configuration mode

Click the encoder for 5 seconds. Config led will turn on and both bank leds will turn off. The display will show a “A”. Move the encoder to select a setting.

Settings table

Code | Setting
A | ATTACK. Attack time of the internal AD envelope generator.
D | DECAY. Decay time of the internal AD envelope generator.
F | FM. Control the amount of modulation from the internal AD envelope generator to the FM.
T | TIMBRE. Control the amount of modulation from the internal AD envelope generator to the Timbre.
C | COLOR. Control the amount of modulation from the internal AD envelope generator to the Color.
H | VCA. Control the amount of modulation from the internal AD envelope generator to Output Amplitude Parameters
E | META MODULATION. Allows the synthesis model to be selected by the FM CV. When this mode is active, frequency modulation through the FM CV input is no longer possible. 0: Off 1: On
G | TRIGGER. Selects a trigger source. 0: INTERNAL. Trigger Input jack will be used. 1: AUTO additionally tracks changes in the V/OCT frequency input larger than a semitone and generates a trigger on each of these.
U | QUANTIFICATION. Applies a quantification to the incoming V/OCT control voltage. The frequency can be quantized to semitones, or to one of the many available scales, or disabled. 0: Off 1: SEMI 2: IONI 3: DORI 4: PHRY 5: LYDI 6: MIXO 7:AEOL 8:LOCR 9:BLUES+ A:BLUES- B: PEN+ C:PEN- D: FOLK E:JAPA F:GAME G:GYPS H:ARAB I: FLAM J:WHOL
R | ROOT. Selects the root note upon which is built the quantizer’s scale. 0: C 1: Db 2: D 3: Eb 4: E 5: F 6: Gb 7: G 8: Ab 9: A 10: Bb 11: B
L | FLAT. Applies a detuning in the lower and higher frequencies, to recreate some of the tuning imperfections of VCOs.

After select a setting, click the encoder once. The current setting’s value will be shown. Use the encoder to change the value. Click the encoder once to return to the settings menu.

To go back to waveform selection, click the encoder for 5 seconds.

### CALIBRATION

To calibrate the unit, in settings mode, click the encoder 8 times. All leds will turn on and the display will show “2”.

Disconnect any signal from the FM input, and connect the note CV output of a well-calibrated keyboard interface or MIDI-CV converter to the V/OCT input. Turn TUNE knob to 12 o’clock position and TIMBRE and COLOR knobs to the right.

Send a voltage tha corresponds to C2 to the CV input. Click on the encoder.

The screen displays “4”. Send a voltage that corresponds to C4 to the CV input. Turn TIMBRE and COLOR knobs to the left.

Click on the encoder to finish calibration.

User’s Manual Page i

User’s Manual Page iii

User’s Manual Page 2

User’s Manual

User’s Manual Page 5

Revision Sheet

1.0 General Information

2.0 Getting started

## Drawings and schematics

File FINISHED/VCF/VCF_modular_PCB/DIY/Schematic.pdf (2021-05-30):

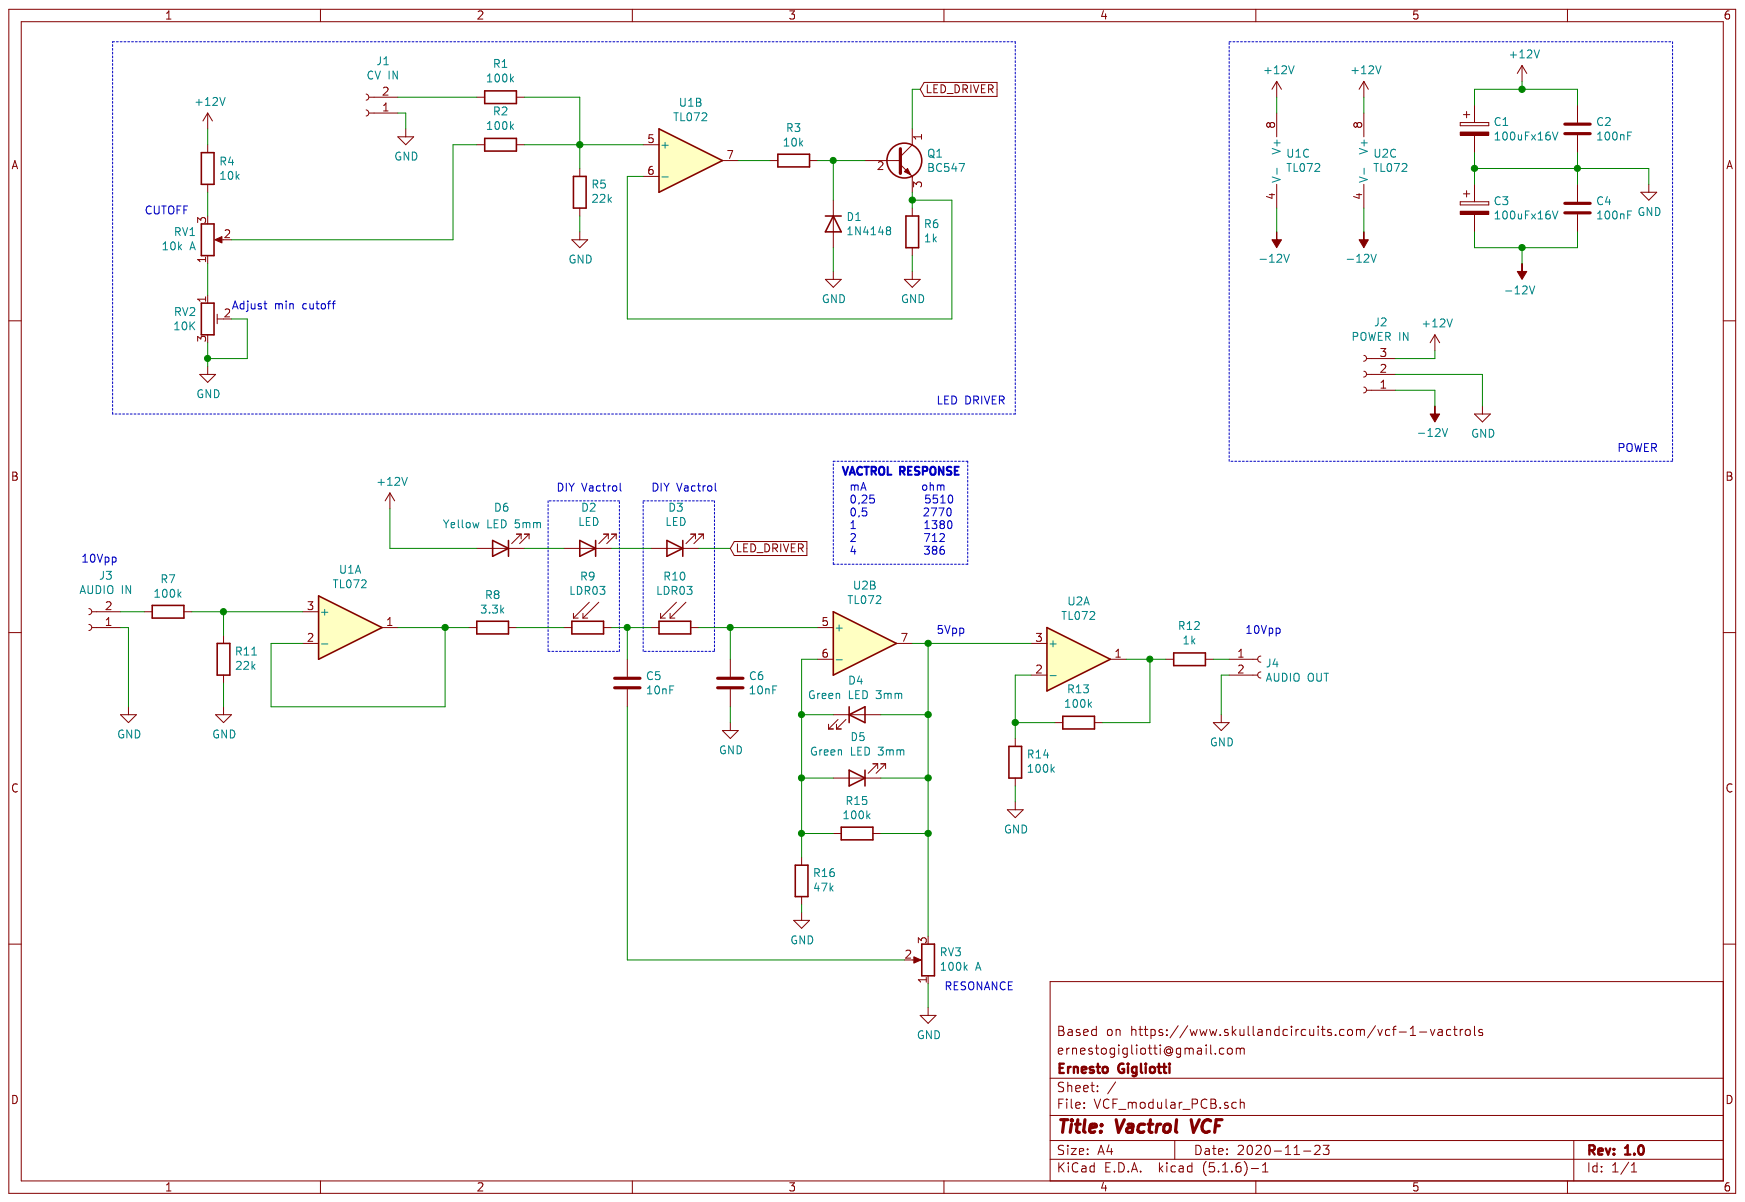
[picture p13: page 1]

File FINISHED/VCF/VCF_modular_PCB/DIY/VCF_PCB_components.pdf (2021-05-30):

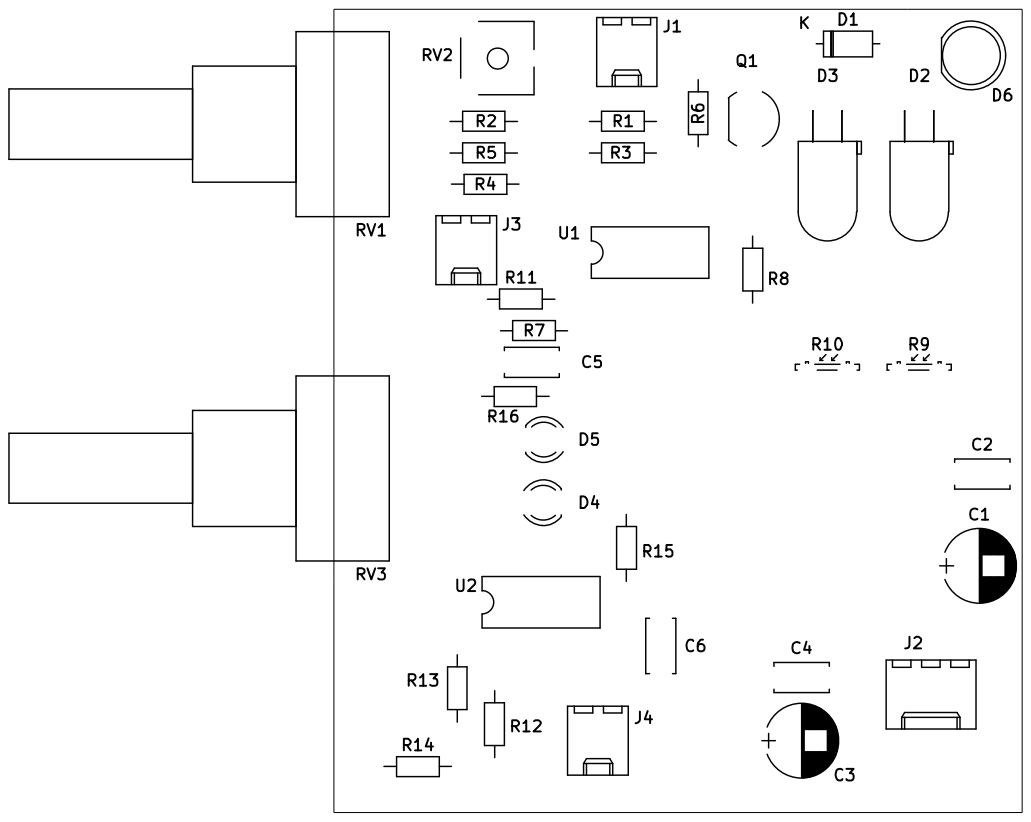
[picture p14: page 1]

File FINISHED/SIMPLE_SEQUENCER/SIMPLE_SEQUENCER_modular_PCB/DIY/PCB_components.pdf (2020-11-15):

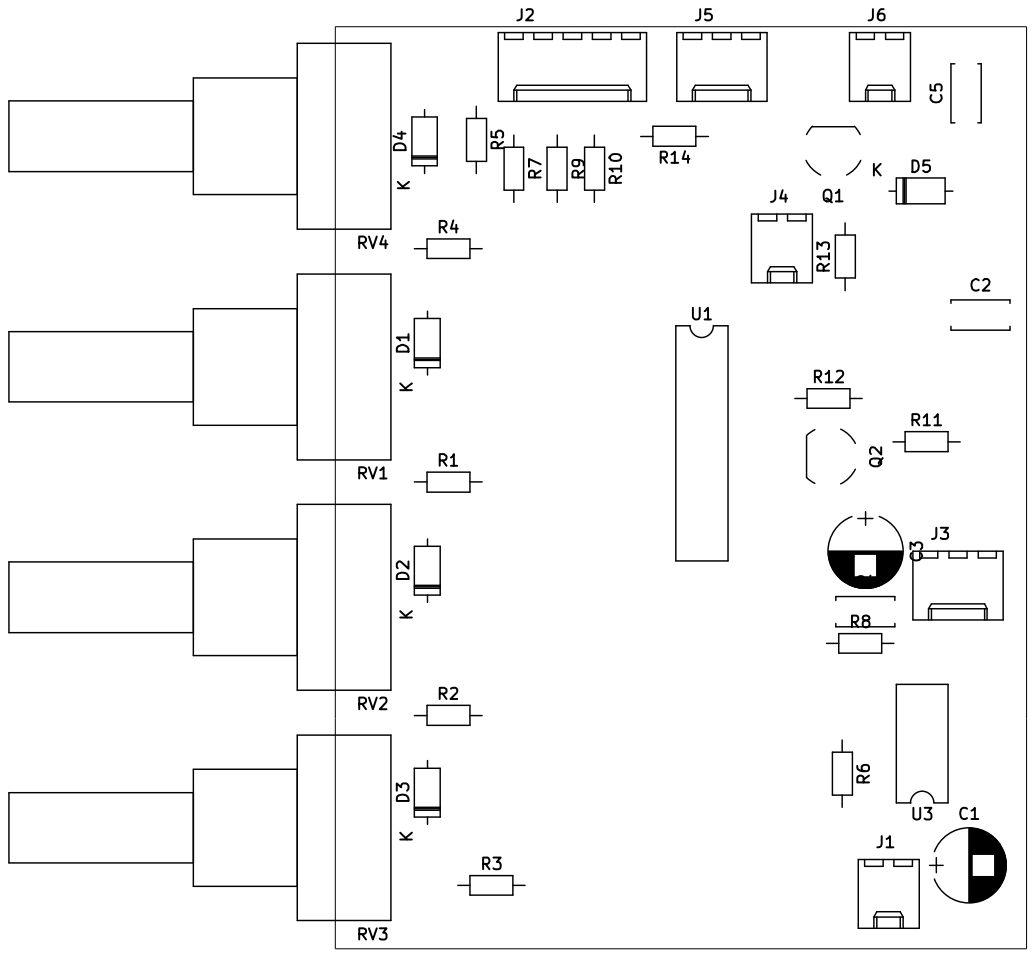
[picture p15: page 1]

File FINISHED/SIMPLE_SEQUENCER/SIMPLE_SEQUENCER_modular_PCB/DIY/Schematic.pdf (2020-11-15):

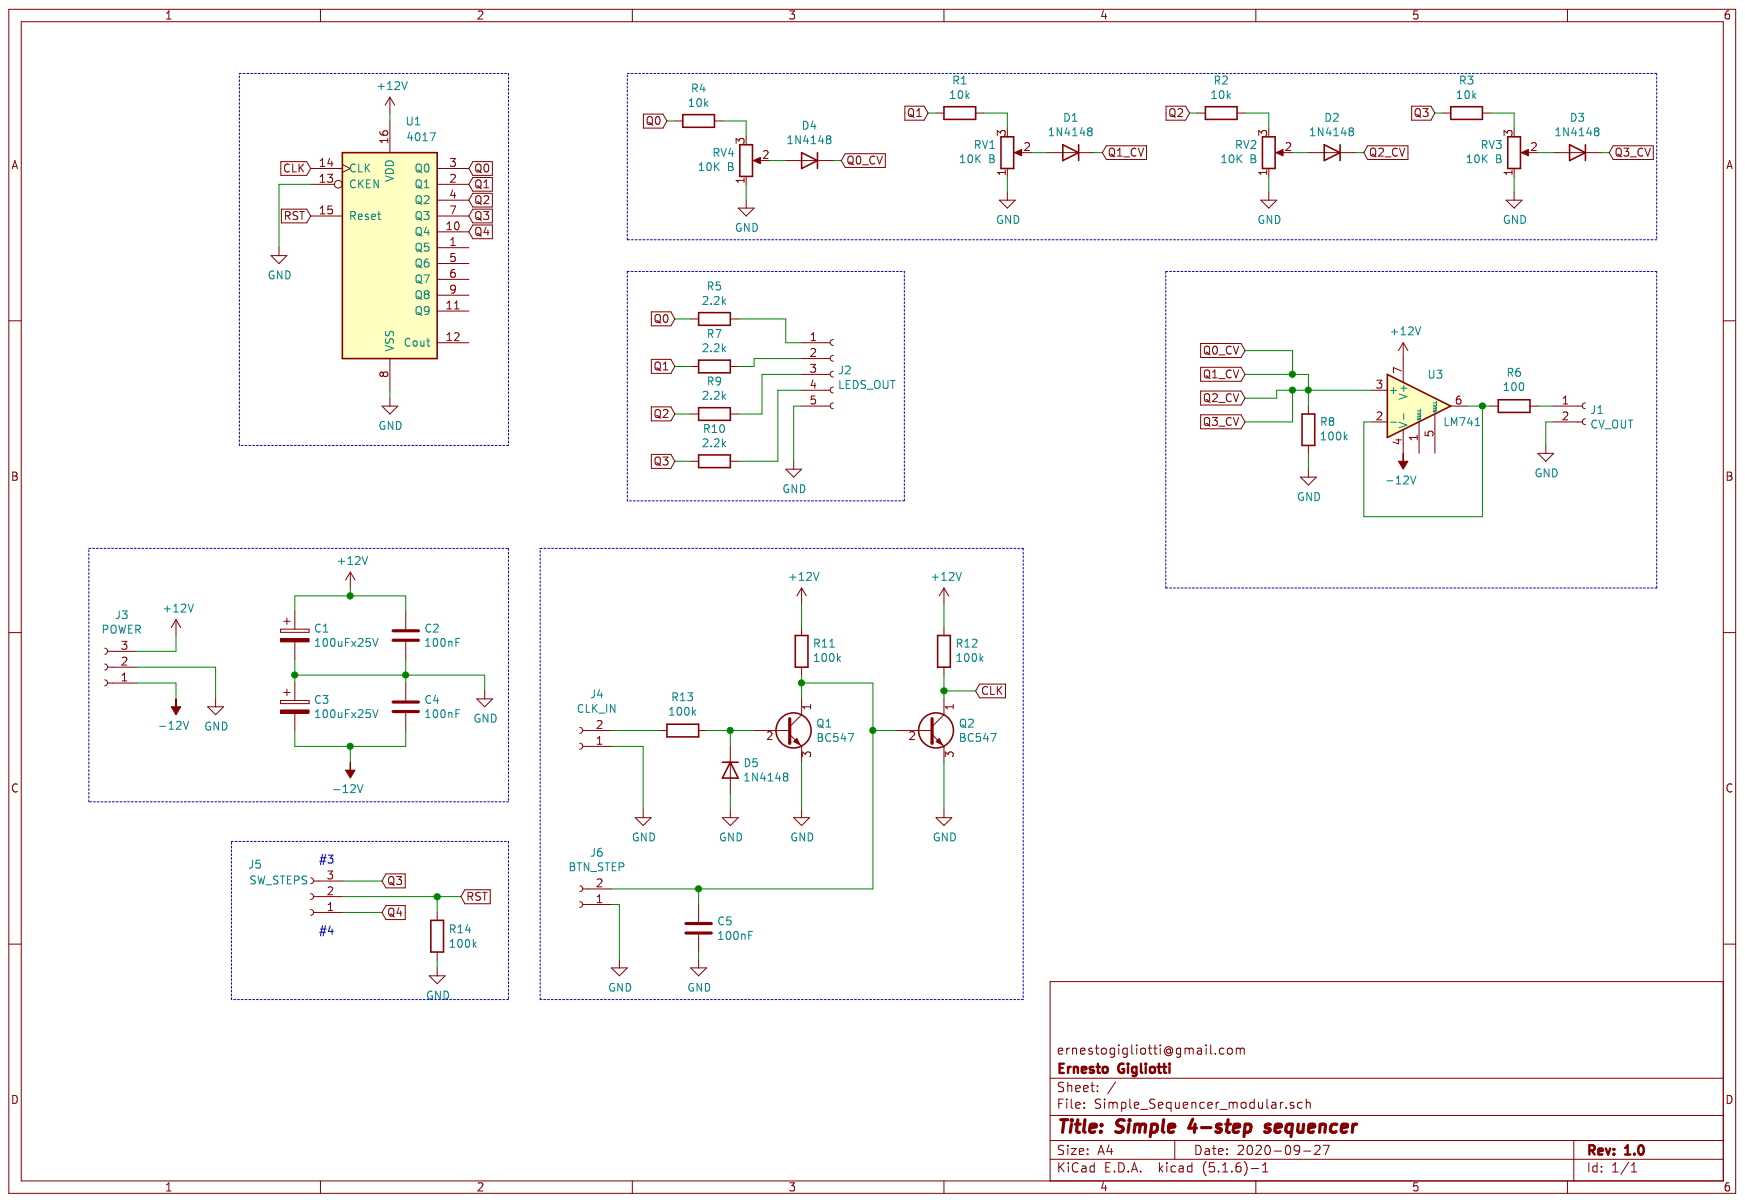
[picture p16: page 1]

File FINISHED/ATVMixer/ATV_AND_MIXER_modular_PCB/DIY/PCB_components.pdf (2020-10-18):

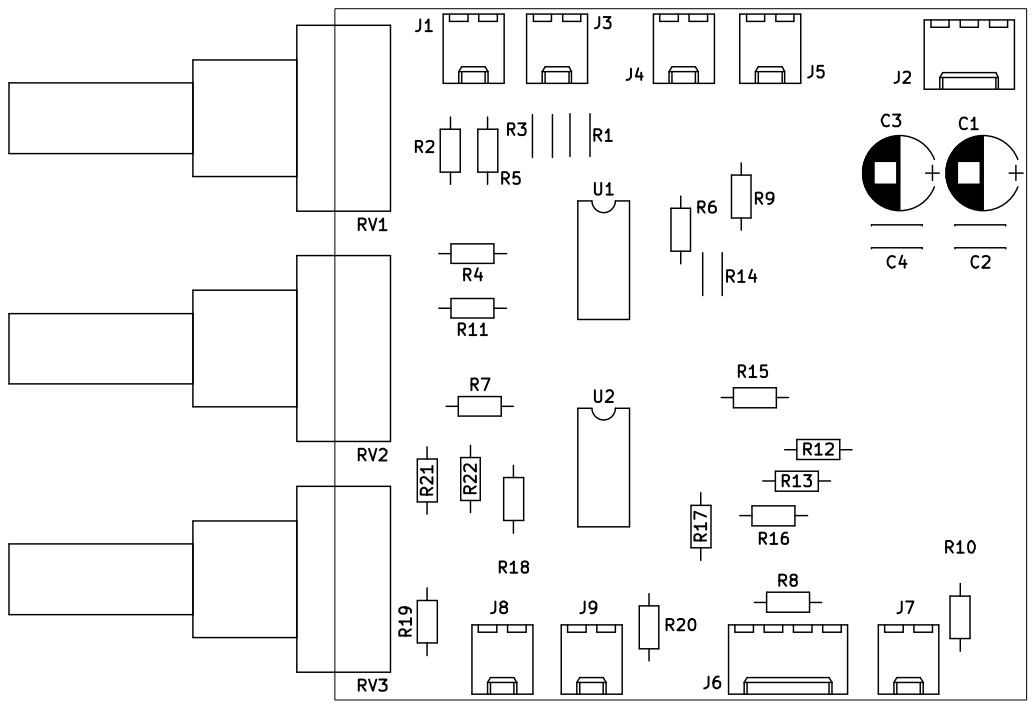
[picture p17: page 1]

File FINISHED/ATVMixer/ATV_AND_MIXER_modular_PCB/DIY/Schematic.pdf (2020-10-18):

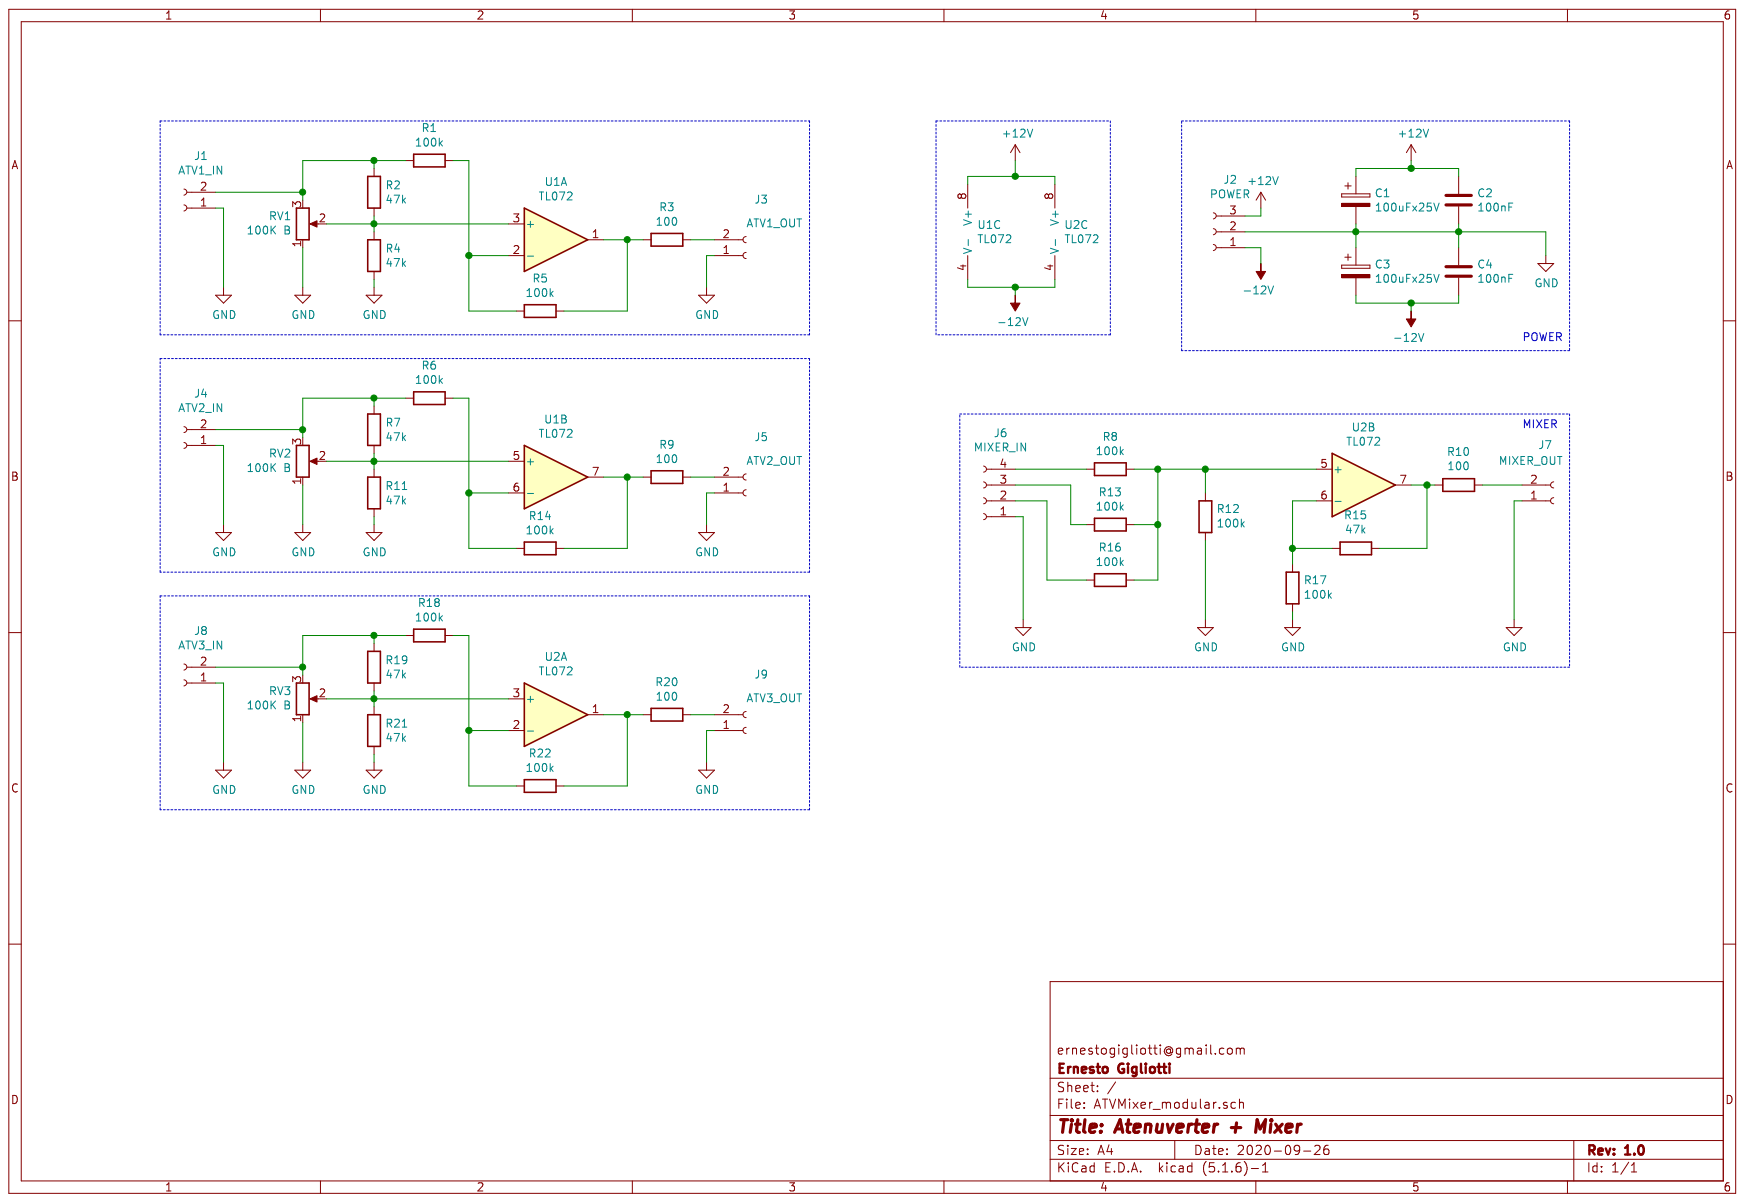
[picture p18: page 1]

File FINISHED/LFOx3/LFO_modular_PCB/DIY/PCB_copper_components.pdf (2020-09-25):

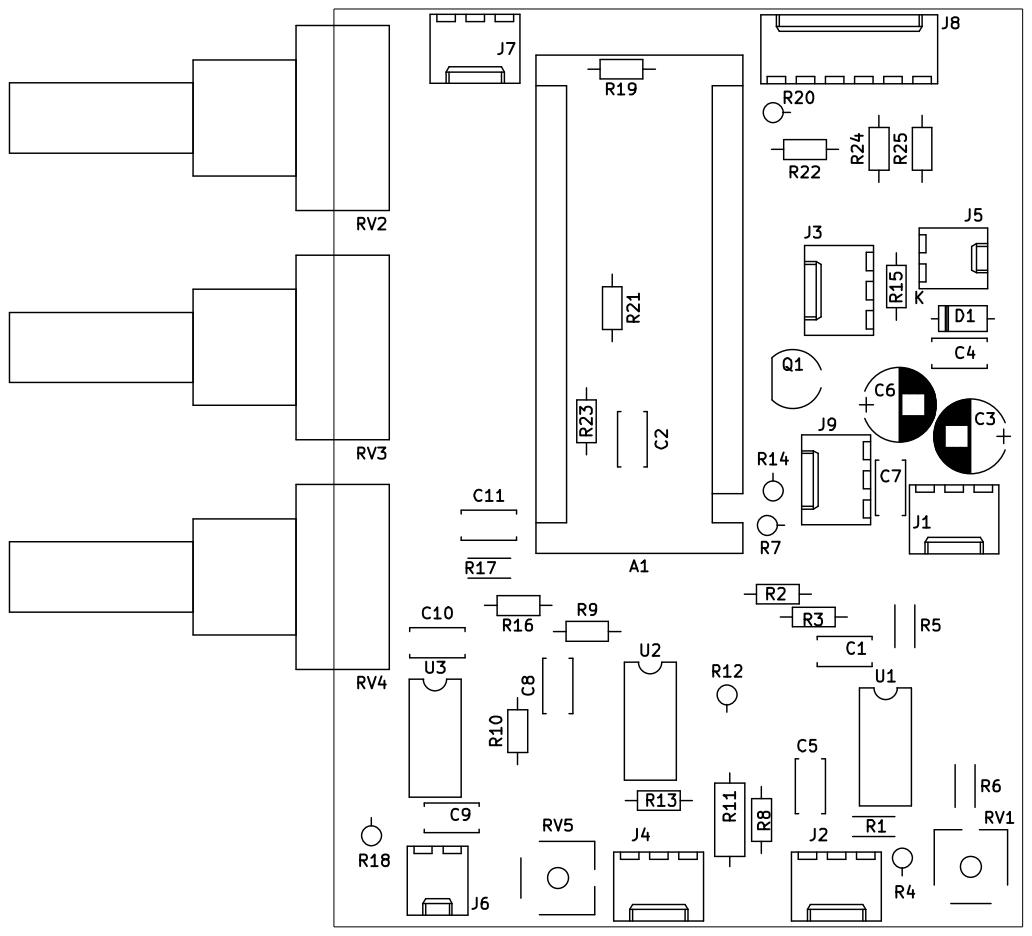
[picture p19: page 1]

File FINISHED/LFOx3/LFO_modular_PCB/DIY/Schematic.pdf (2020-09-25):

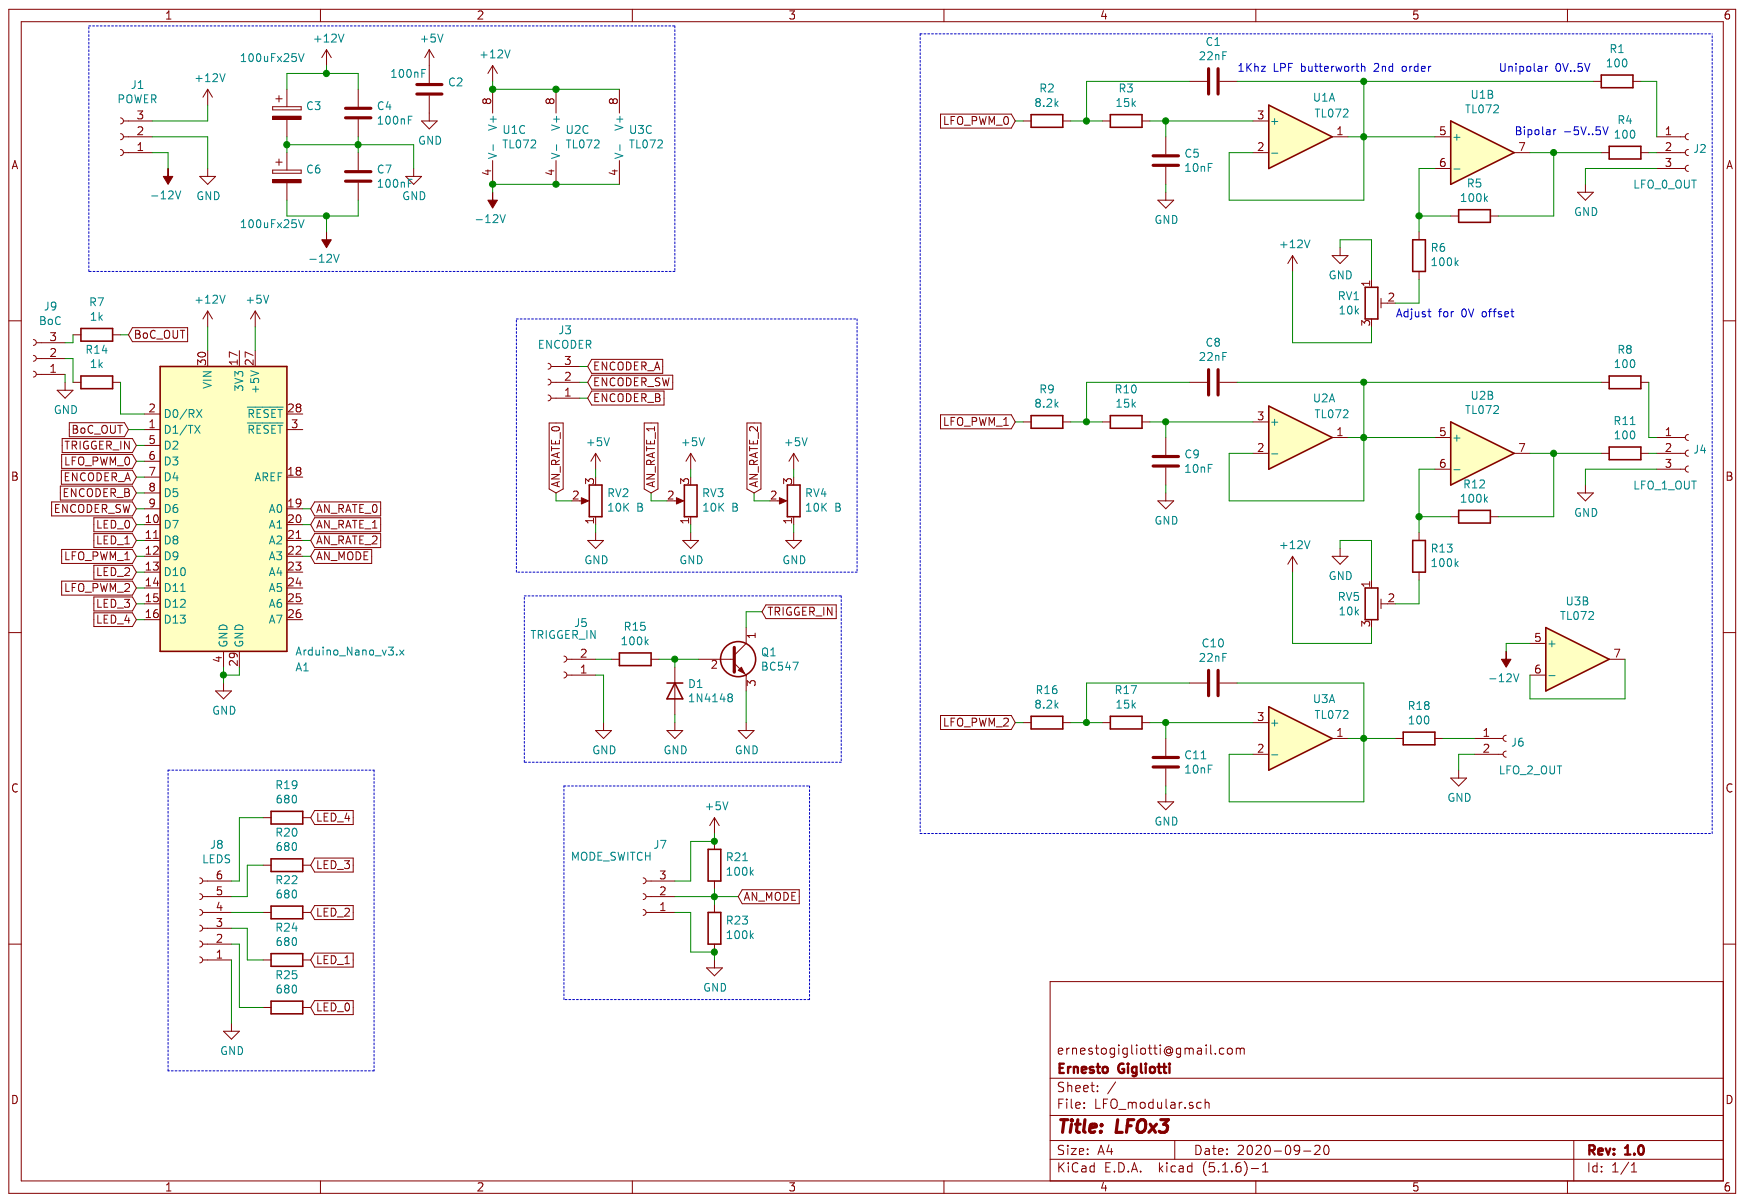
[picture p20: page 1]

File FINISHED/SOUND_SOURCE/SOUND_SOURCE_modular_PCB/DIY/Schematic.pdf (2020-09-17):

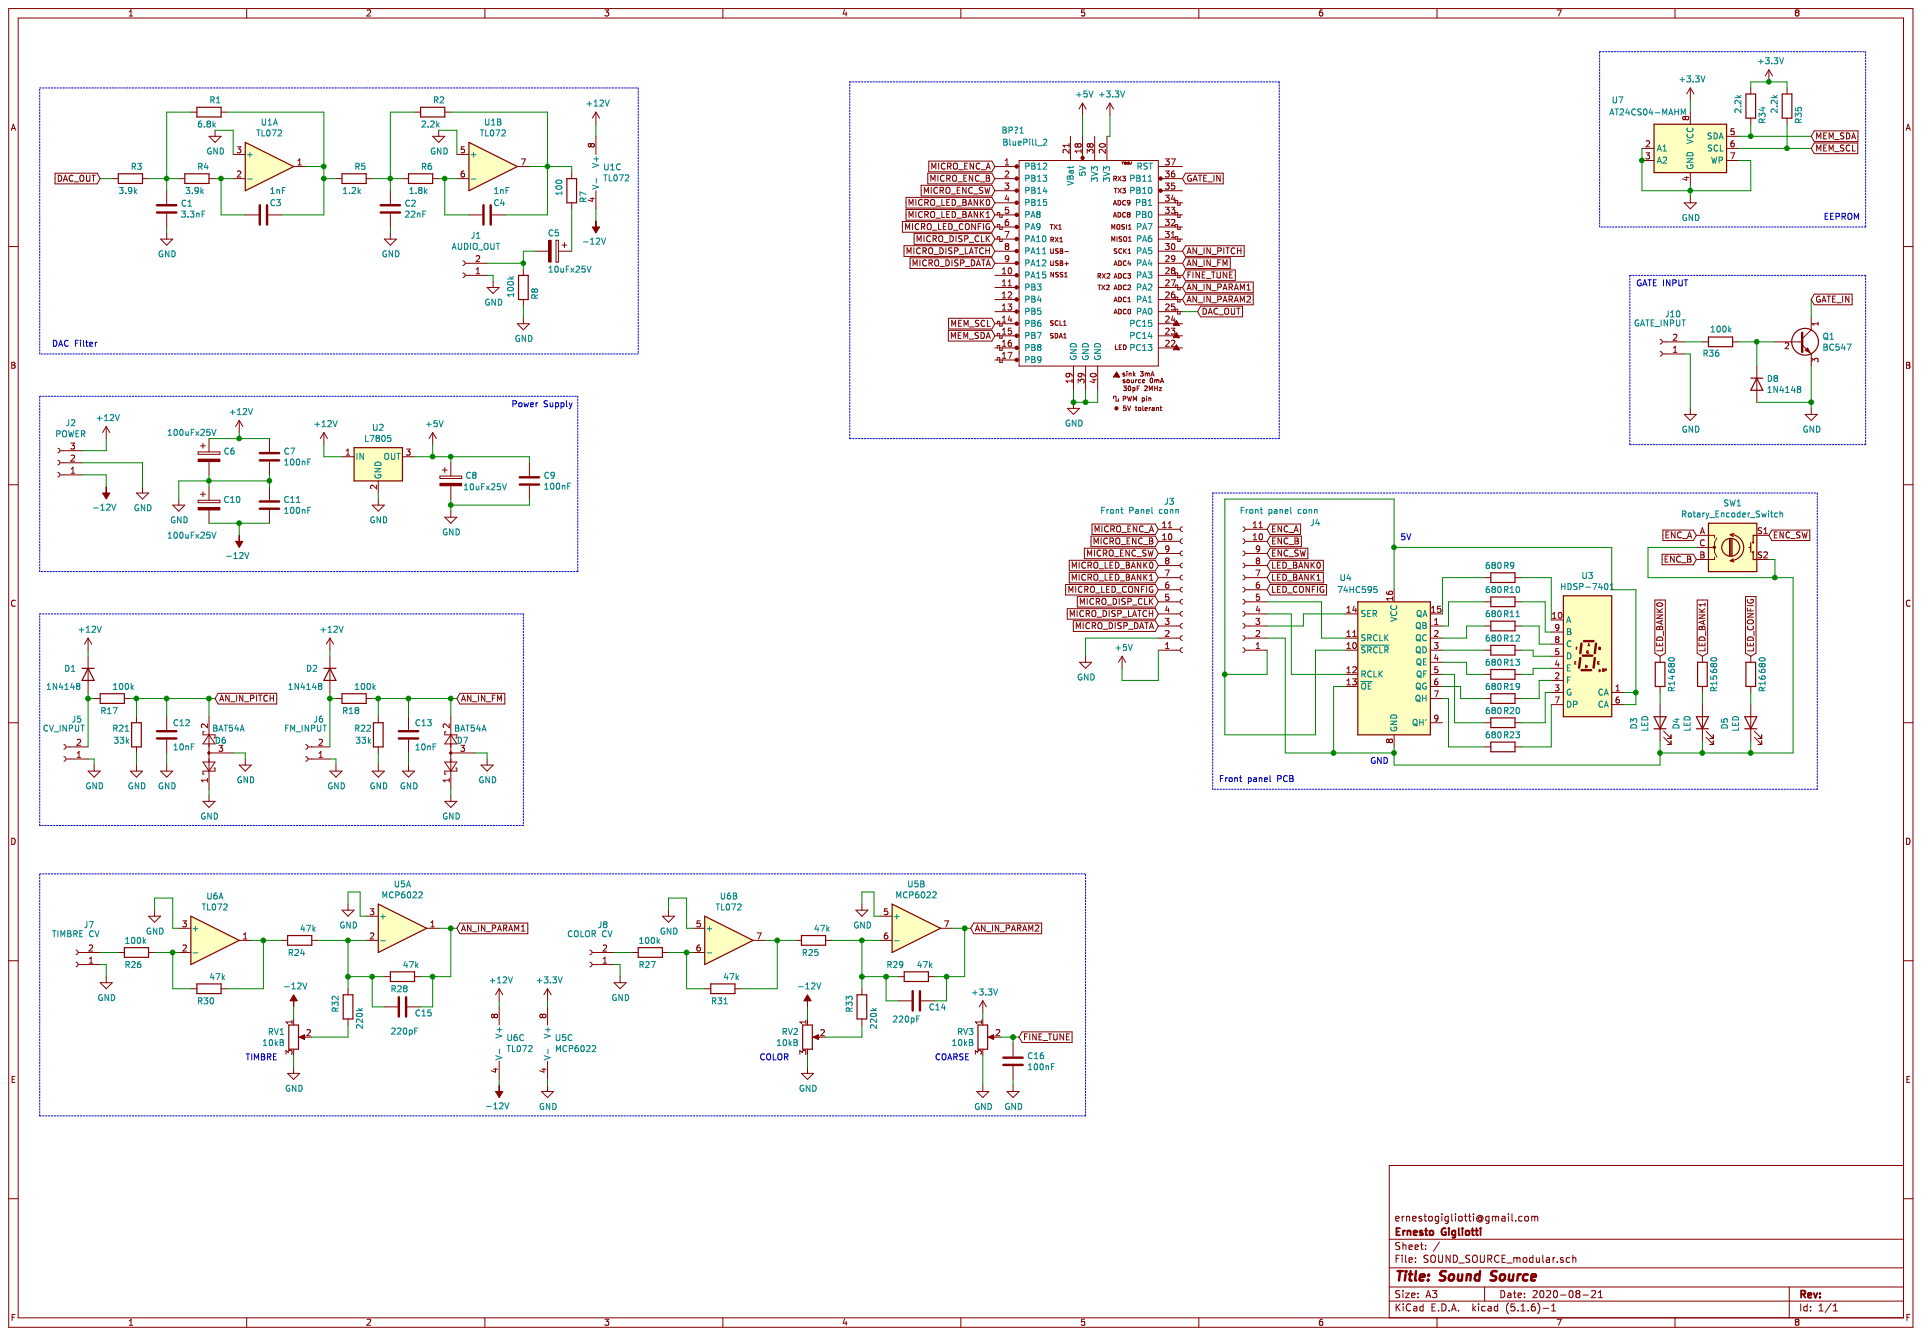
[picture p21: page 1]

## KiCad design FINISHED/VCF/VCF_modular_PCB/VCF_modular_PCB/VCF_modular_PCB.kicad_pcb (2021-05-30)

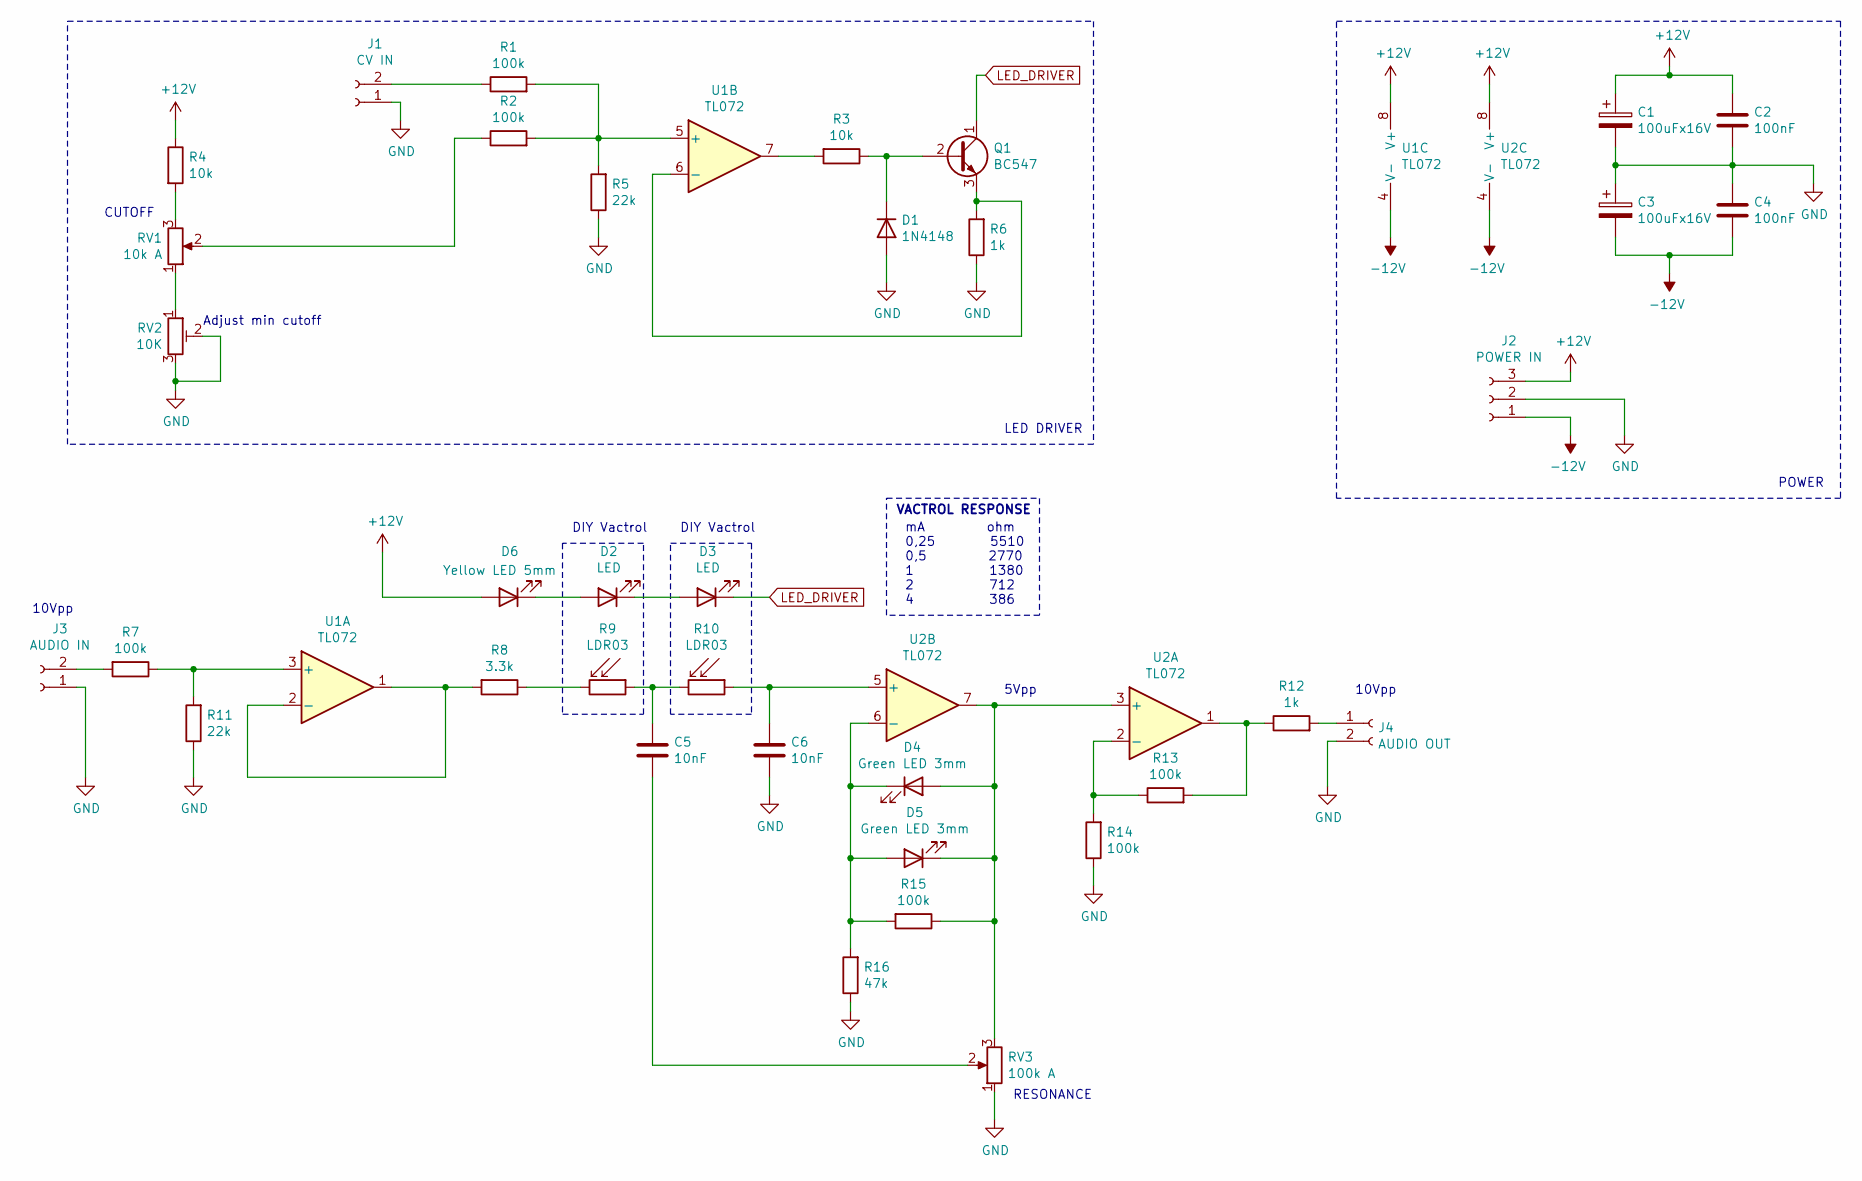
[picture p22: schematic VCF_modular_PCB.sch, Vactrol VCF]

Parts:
C1, C3: 100uFx16V; CP_Radial_D6.3mm_P2.50mm
C2, C4: 100nF; C_Disc_D4.7mm_W2.5mm_P5.00mm
C5, C6: 10nF; C_Disc_D4.7mm_W2.5mm_P5.00mm
D1: 1N4148; D_DO-35_SOD27_P7.62mm_Horizontal
D2, D3: LED; LED_D5.0mm_Horizontal_O3.81mm_Z3.0mm
D4, D5: Green LED 3mm; LED_D3.0mm_FlatTop
D6: Yellow LED 5mm; LED_D5.0mm
J1: CV IN; Molex_KK-6410-02_02x2.54mm_Straight
J2: POWER IN; Molex_KK-6410-03_03x2.54mm_Straight
J3: AUDIO IN; Molex_KK-6410-02_02x2.54mm_Straight
J4: AUDIO OUT; Molex_KK-6410-02_02x2.54mm_Straight
Q1: BC547; TO-92_Inline_Wide
R1, R2, R7, R13, R14, R15: 100k; R_Axial_DIN0204_L3.6mm_D1.6mm_P7.62mm_Horizontal
R3, R4: 10k; R_Axial_DIN0204_L3.6mm_D1.6mm_P7.62mm_Horizontal
R5, R11: 22k; R_Axial_DIN0204_L3.6mm_D1.6mm_P7.62mm_Horizontal
R6, R12: 1k; R_Axial_DIN0204_L3.6mm_D1.6mm_P7.62mm_Horizontal
R8: 3.3k; R_Axial_DIN0204_L3.6mm_D1.6mm_P7.62mm_Horizontal
R9, R10: LDR03; Resistor_LDR_Vertical_5.2x5.2_RM3.5
R16: 47k; R_Axial_DIN0204_L3.6mm_D1.6mm_P7.62mm_Horizontal
RV1: 10k A; Potentiometer_Piher_PC-16_Single_Vertical
RV2: 10K; Potentiometer_Trimmer_ACP_CA6v_Horizontal
RV3: 100k A; Potentiometer_Piher_PC-16_Single_Vertical
U1, U2: TL072; DIP-8_W7.62mm_LongPads

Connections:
+12V: C1.1, C2.1, D6.2 (A), J2.3, R4.1, U1.8 (V+), U2.8 (V+)
-12V: C3.2, C4.2, J2.1, U1.4 (V-), U2.4 (V-)
GND: C1.2, C2.2, C3.1, C4.1, C6.2, D1.2 (A), J1.1, J2.2, J3.1, J4.2, R5.1, R6.1, R11.1, R14.1, R16.1, RV2.2, RV2.3, RV3.1
LED_DRIVER: D3.1 (K), Q1.1 (C)
unnamed: C5.1, R9.1, R10.2
unnamed: C5.2, RV3.2
unnamed: C6.1, R10.1, U2.5 (+)
unnamed: D1.1 (K), Q1.2 (B), R3.1
unnamed: D2.1 (K), D3.2 (A)
unnamed: D2.2 (A), D6.1 (K)
unnamed: D4.1 (K), D5.2 (A), R15.2, R16.2, U2.6 (-)
unnamed: D4.2 (A), D5.1 (K), R15.1, RV3.3, U2.3 (+), U2.7
unnamed: J1.2, R1.1
unnamed: J3.2, R7.2
unnamed: J4.1, R12.2
unnamed: Q1.3 (E), R6.2, U1.6 (-)
unnamed: R1.2, R2.2, R5.2, U1.5 (+)
unnamed: R2.1, RV1.2
unnamed: R3.2, U1.7
unnamed: R4.2, RV1.3
unnamed: R8.1, R9.2
unnamed: R8.2, U1.1, U1.2 (-)
unnamed: R7.1, R11.2, U1.3 (+)
unnamed: R12.1, R13.2, U2.1
unnamed: R13.1, R14.2, U2.2 (-)
unnamed: RV1.1, RV2.1

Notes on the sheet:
RESONANCE
DIY Vactrol
CUTOFF
LED DRIVER
POWER
Adjust min cutoff
mA ohm 0,25 5510 0,5 2770 1 1380 2 712 4 386
VACTROL RESPONSE
5Vpp
10Vpp

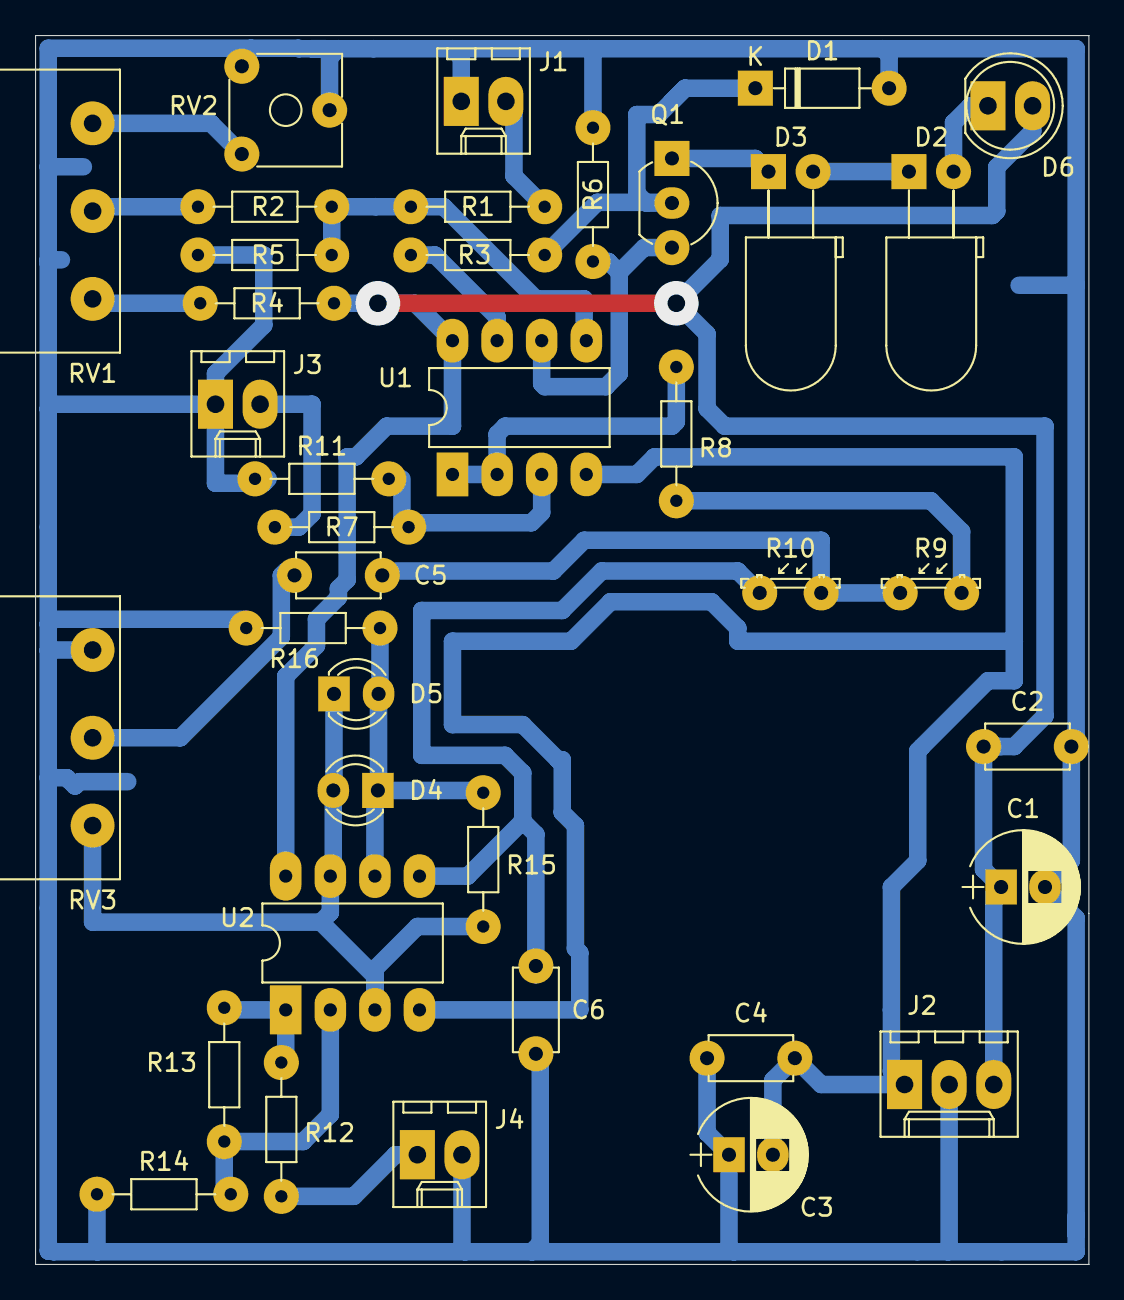
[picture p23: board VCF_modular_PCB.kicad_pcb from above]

Board: 2 copper layers, 60.0 x 70.0 mm, 38 parts (0 on the bottom side), 26 nets.

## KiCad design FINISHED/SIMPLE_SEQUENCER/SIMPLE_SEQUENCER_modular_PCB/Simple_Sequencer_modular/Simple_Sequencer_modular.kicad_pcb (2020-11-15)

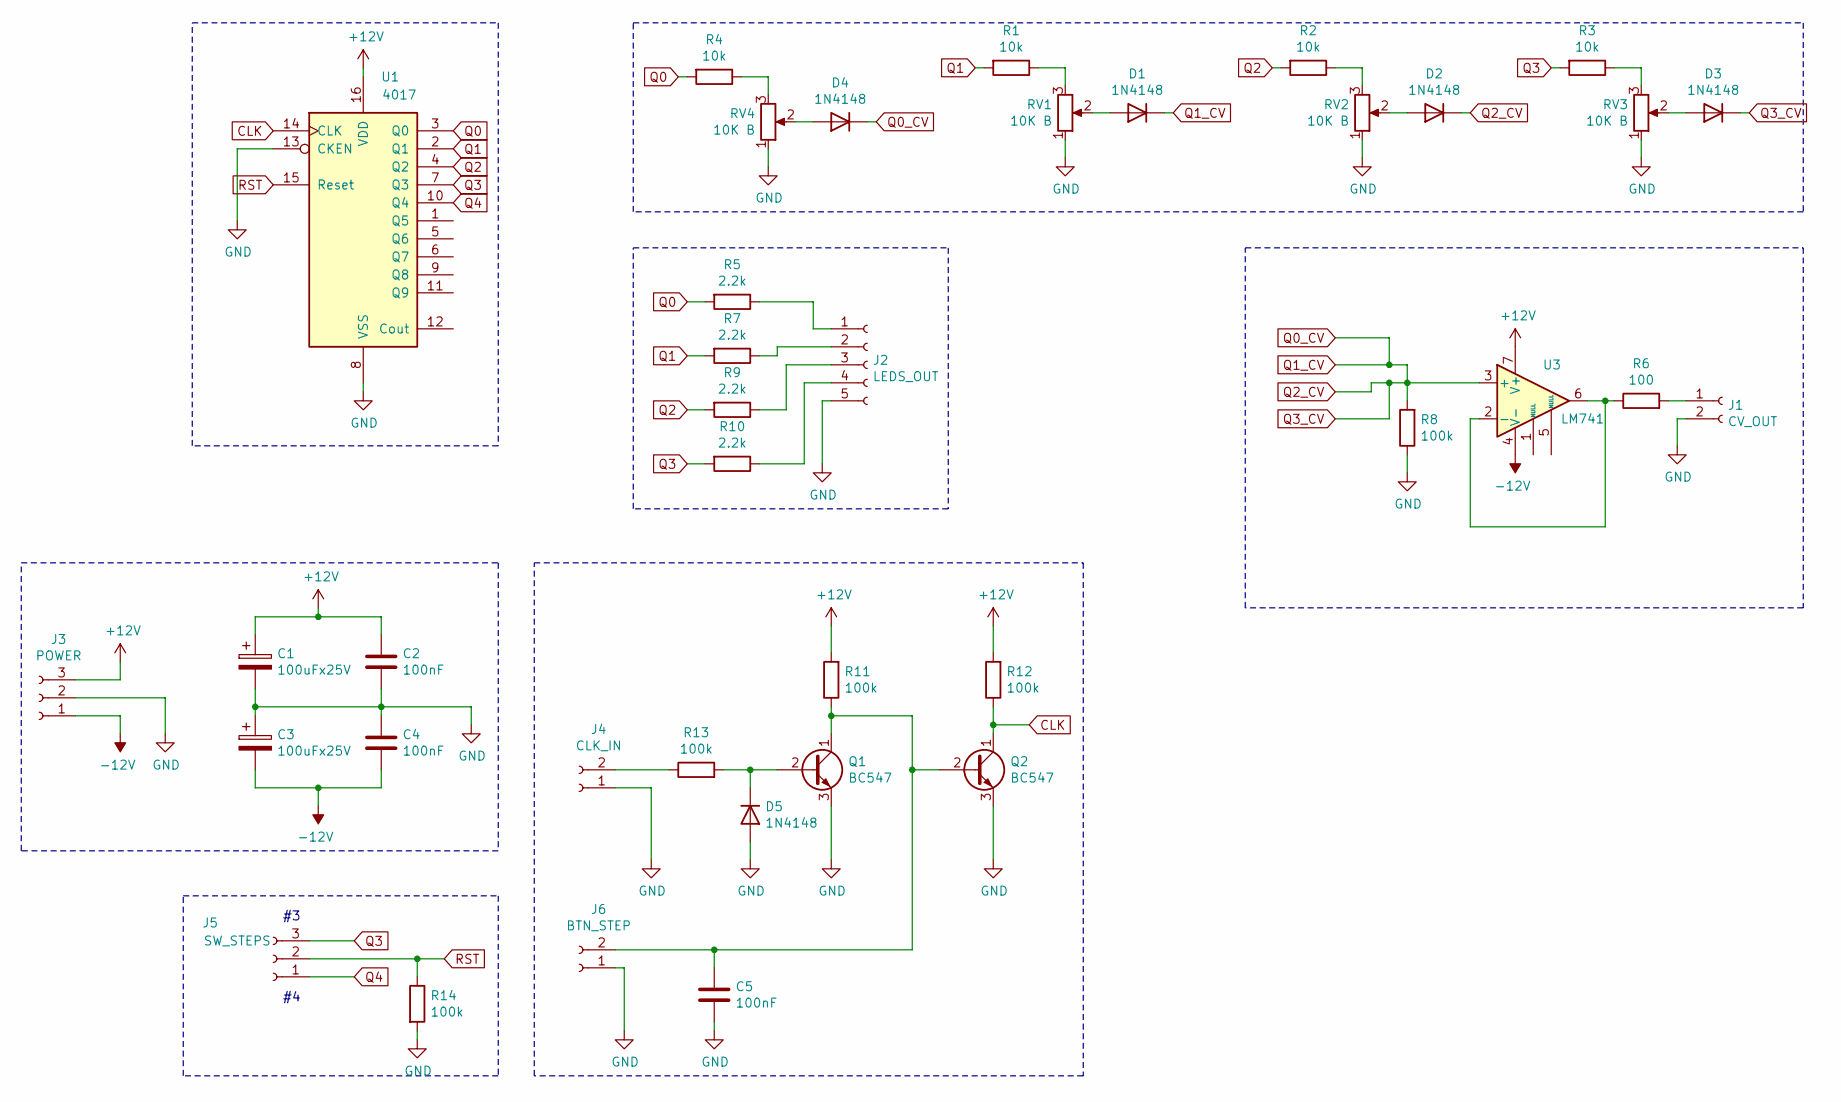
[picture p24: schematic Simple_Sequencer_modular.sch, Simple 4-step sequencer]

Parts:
C1, C3: 100uFx25V; CP_Radial_D6.3mm_P2.50mm
C2, C4, C5: 100nF; C_Disc_D5.0mm_W2.5mm_P5.00mm
D1, D2, D3, D4, D5: 1N4148; D_DO-35_SOD27_P7.62mm_Horizontal
J1: CV_OUT; Molex_KK-6410-02_02x2.54mm_Straight
J2: LEDS_OUT; Molex_KK-6410-05_05x2.54mm_Straight
J3: POWER; Molex_KK-6410-03_03x2.54mm_Straight
J4: CLK_IN; Molex_KK-6410-02_02x2.54mm_Straight
J5: SW_STEPS; Molex_KK-6410-03_03x2.54mm_Straight
J6: BTN_STEP; Molex_KK-6410-02_02x2.54mm_Straight
Q1, Q2: BC547; TO-92_Wide
R1, R2, R3, R4: 10k; R_Axial_DIN0204_L3.6mm_D1.6mm_P7.62mm_Horizontal
R5, R7, R9, R10: 2.2k; R_Axial_DIN0204_L3.6mm_D1.6mm_P7.62mm_Horizontal
R6: 100; R_Axial_DIN0204_L3.6mm_D1.6mm_P7.62mm_Horizontal
R8, R11, R12, R13, R14: 100k; R_Axial_DIN0204_L3.6mm_D1.6mm_P7.62mm_Horizontal
RV1, RV2, RV3, RV4: 10K B; Potentiometer_Piher_PC-16_Single_Vertical
U1: 4017; DIP-16_W7.62mm_LongPads
U3: LM741; DIP-8_W7.62mm_LongPads

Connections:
+12V: C1.1, C2.1, J3.3, R11.2, R12.2, U1.16 (VDD), U3.7 (V+)
-12V: C3.2, C4.2, J3.1, U3.4 (V-)
CLK: Q2.1 (C), R12.1, U1.14 (CLK)
GND: C1.2, C2.2, C3.1, C4.1, C5.2, D5.2 (A), J1.2, J2.5, J3.2, J4.1, J6.1, Q1.3 (E), Q2.3 (E), R8.1, R14.2, RV1.1, RV2.1, RV3.1, RV4.1, U1.8 (VSS), U1.13 (CKEN)
unnamed: C5.1, J6.2, Q1.1 (C), Q2.2 (B), R11.1
unnamed: D1.2 (A), RV1.2
unnamed: D2.2 (A), RV2.2
unnamed: D3.2 (A), RV3.2
unnamed: D4.2 (A), RV4.2
unnamed: D5.1 (K), Q1.2 (B), R13.2
unnamed: J1.1, R6.2
unnamed: J2.1, R5.1
unnamed: J2.2, R7.1
unnamed: J2.3, R9.1
unnamed: J2.4, R10.1
unnamed: J4.2, R13.1
unnamed: R1.1, RV1.3
unnamed: R2.1, RV2.3
unnamed: R3.1, RV3.3
unnamed: R4.1, RV4.3
unnamed: R6.1, U3.2 (-), U3.6
Q0: R4.2, R5.2, U1.3 (Q0)
Q0_CV: D1.1 (K), D2.1 (K), D3.1 (K), D4.1 (K), R8.2, U3.3 (+)
Q1: R1.2, R7.2, U1.2 (Q1)
Q2: R2.2, R9.2, U1.4 (Q2)
Q3: J5.3, R3.2, R10.2, U1.7 (Q3)
Q4: J5.1, U1.10 (Q4)
RST: J5.2, R14.1, U1.15 (Reset)

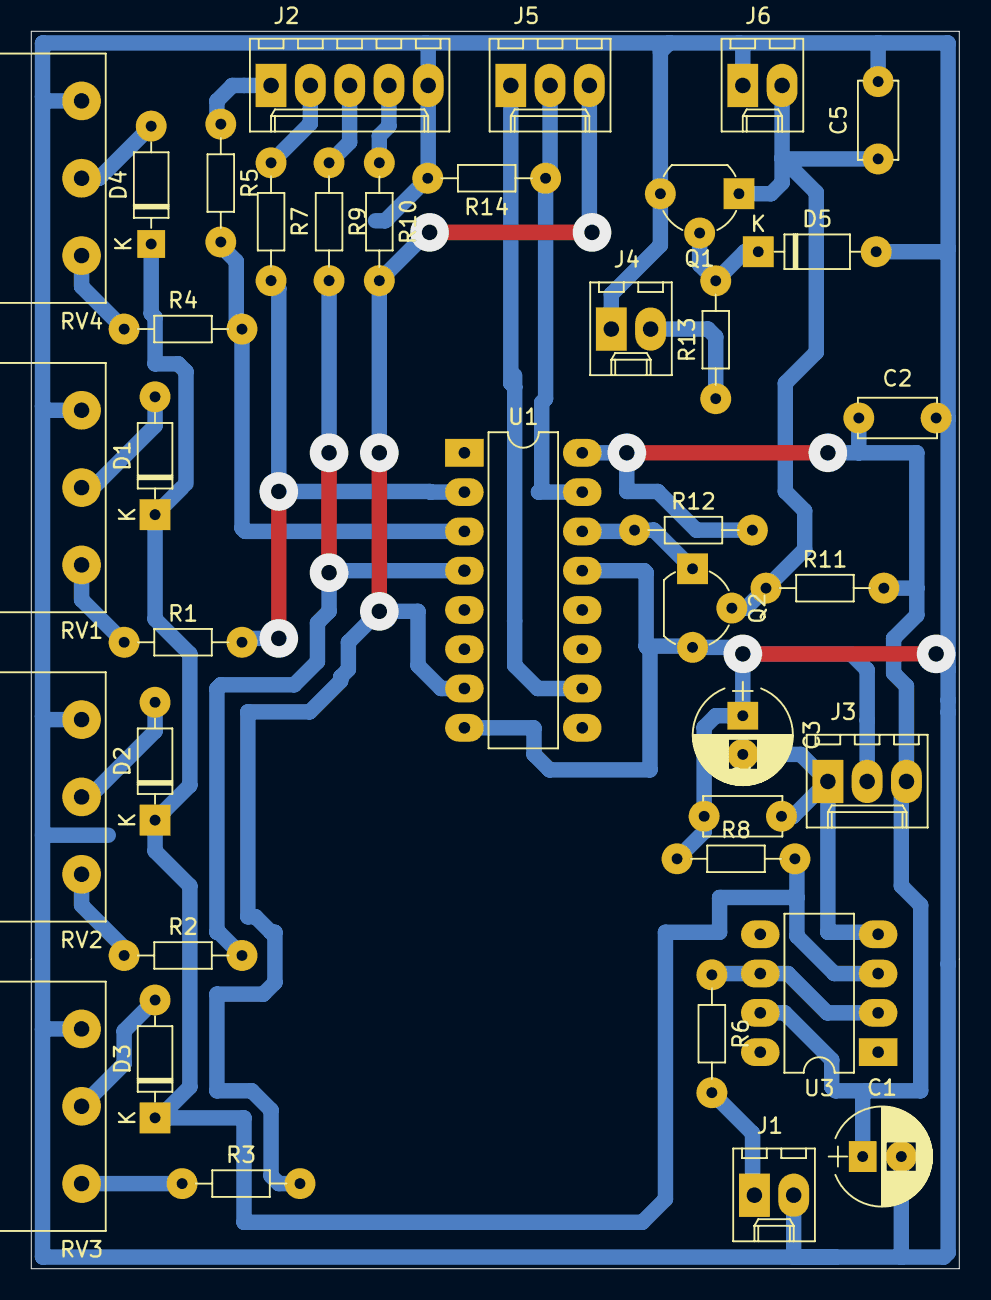
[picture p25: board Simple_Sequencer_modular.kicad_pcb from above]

Board: 2 copper layers, 60.0 x 80.0 mm, 38 parts (0 on the bottom side), 28 nets.

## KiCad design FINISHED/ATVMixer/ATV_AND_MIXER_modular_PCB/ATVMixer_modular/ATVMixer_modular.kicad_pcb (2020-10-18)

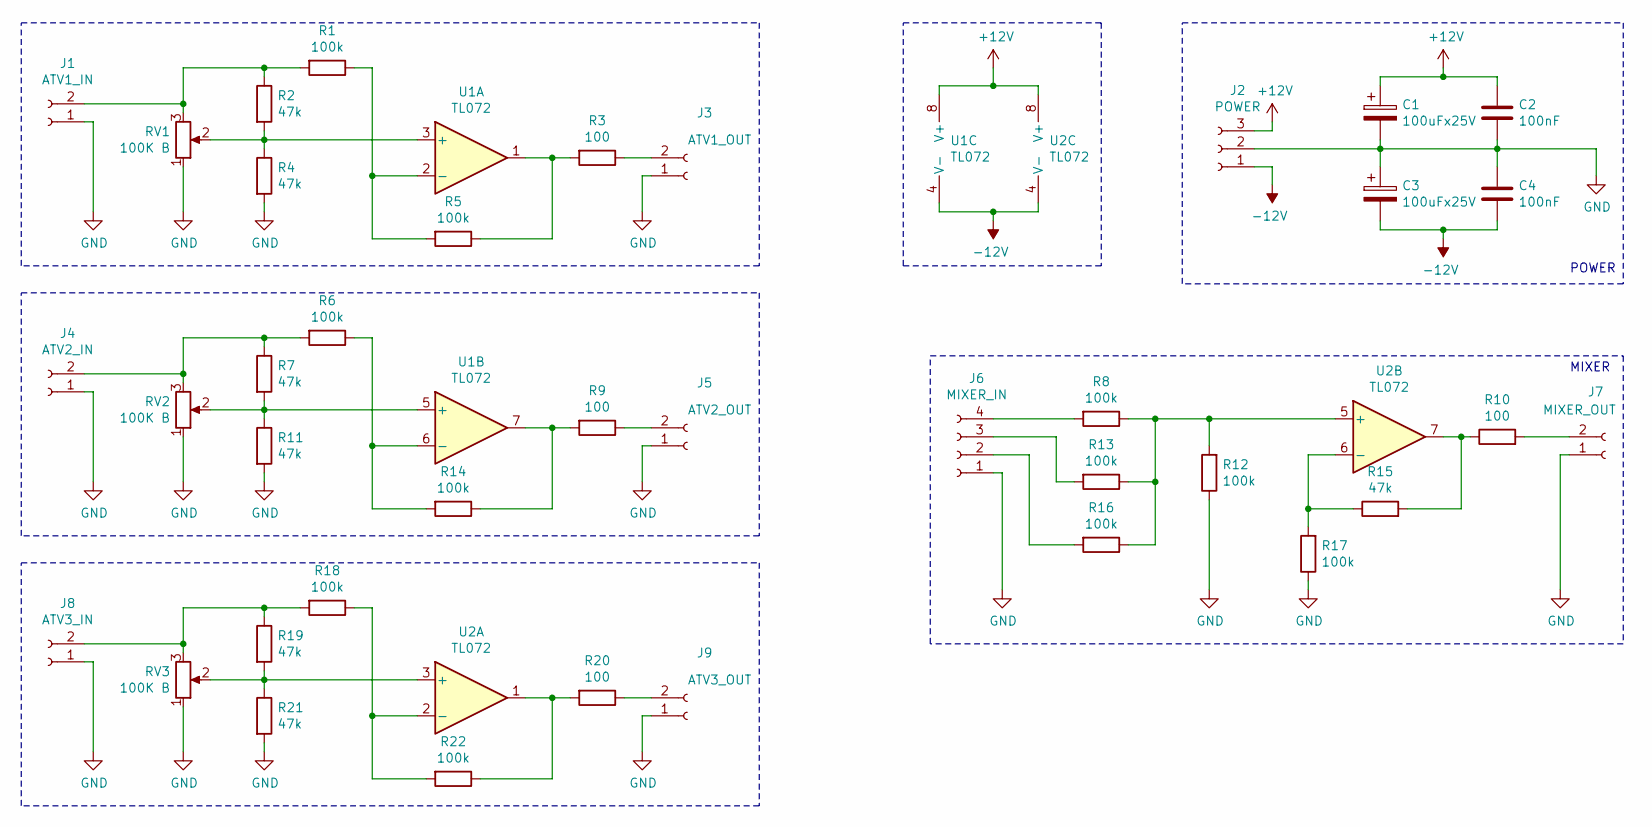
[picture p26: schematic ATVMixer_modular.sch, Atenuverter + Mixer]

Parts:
C1, C3: 100uFx25V; CP_Radial_D6.3mm_P2.50mm
C2, C4: 100nF; C_Disc_D4.3mm_W1.9mm_P5.00mm
J1: ATV1_IN; Molex_KK-6410-02_02x2.54mm_Straight
J2: POWER; Molex_KK-6410-03_03x2.54mm_Straight
J3: ATV1_OUT; Molex_KK-6410-02_02x2.54mm_Straight
J4: ATV2_IN; Molex_KK-6410-02_02x2.54mm_Straight
J5: ATV2_OUT; Molex_KK-6410-02_02x2.54mm_Straight
J6: MIXER_IN; Molex_KK-6410-04_04x2.54mm_Straight
J7: MIXER_OUT; Molex_KK-6410-02_02x2.54mm_Straight
J8: ATV3_IN; Molex_KK-6410-02_02x2.54mm_Straight
J9: ATV3_OUT; Molex_KK-6410-02_02x2.54mm_Straight
R1, R5, R6, R8, R12, R13, R14, R16, R17, R18, R22: 100k; R_Axial_DIN0204_L3.6mm_D1.6mm_P7.62mm_Horizontal
R2, R4, R7, R11, R15, R19, R21: 47k; R_Axial_DIN0204_L3.6mm_D1.6mm_P7.62mm_Horizontal
R3, R9, R10, R20: 100; R_Axial_DIN0204_L3.6mm_D1.6mm_P7.62mm_Horizontal
RV1, RV2, RV3: 100K B; Potentiometer_Piher_PC-16_Single_Vertical
U1, U2: TL072; DIP-8_W7.62mm_LongPads

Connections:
+12V: C1.1, C2.1, J2.3, U1.8 (V+), U2.8 (V+)
-12V: C3.2, C4.2, J2.1, U1.4 (V-), U2.4 (V-)
GND: C1.2, C2.2, C3.1, C4.1, J1.1, J2.2, J3.1, J4.1, J5.1, J6.1, J7.1, J8.1, J9.1, R4.2, R11.2, R12.1, R17.1, R21.2, RV1.1, RV2.1, RV3.1
unnamed: J1.2, R1.2, R2.1, RV1.3
unnamed: J3.2, R3.1
unnamed: J4.2, R6.2, R7.1, RV2.3
unnamed: J5.2, R9.1
unnamed: J6.2, R16.2
unnamed: J6.3, R13.2
unnamed: J6.4, R8.2
unnamed: J7.2, R10.2
unnamed: J8.2, R18.2, R19.1, RV3.3
unnamed: J9.2, R20.1
unnamed: R1.1, R5.2, U1.2 (-)
unnamed: R2.2, R4.1, RV1.2, U1.3 (+)
unnamed: R3.2, R5.1, U1.1
unnamed: R10.1, R15.2, U2.7
unnamed: R7.2, R11.1, RV2.2, U1.5 (+)
unnamed: R8.1, R12.2, R13.1, R16.1, U2.5 (+)
unnamed: R9.2, R14.1, U1.7
unnamed: R6.1, R14.2, U1.6 (-)
unnamed: R15.1, R17.2, U2.6 (-)
unnamed: R18.1, R22.2, U2.2 (-), U2.752
unnamed: R19.2, R21.1, RV3.2, U2.3 (+)
unnamed: R20.2, R22.1, U2.1

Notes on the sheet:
MIXER
POWER

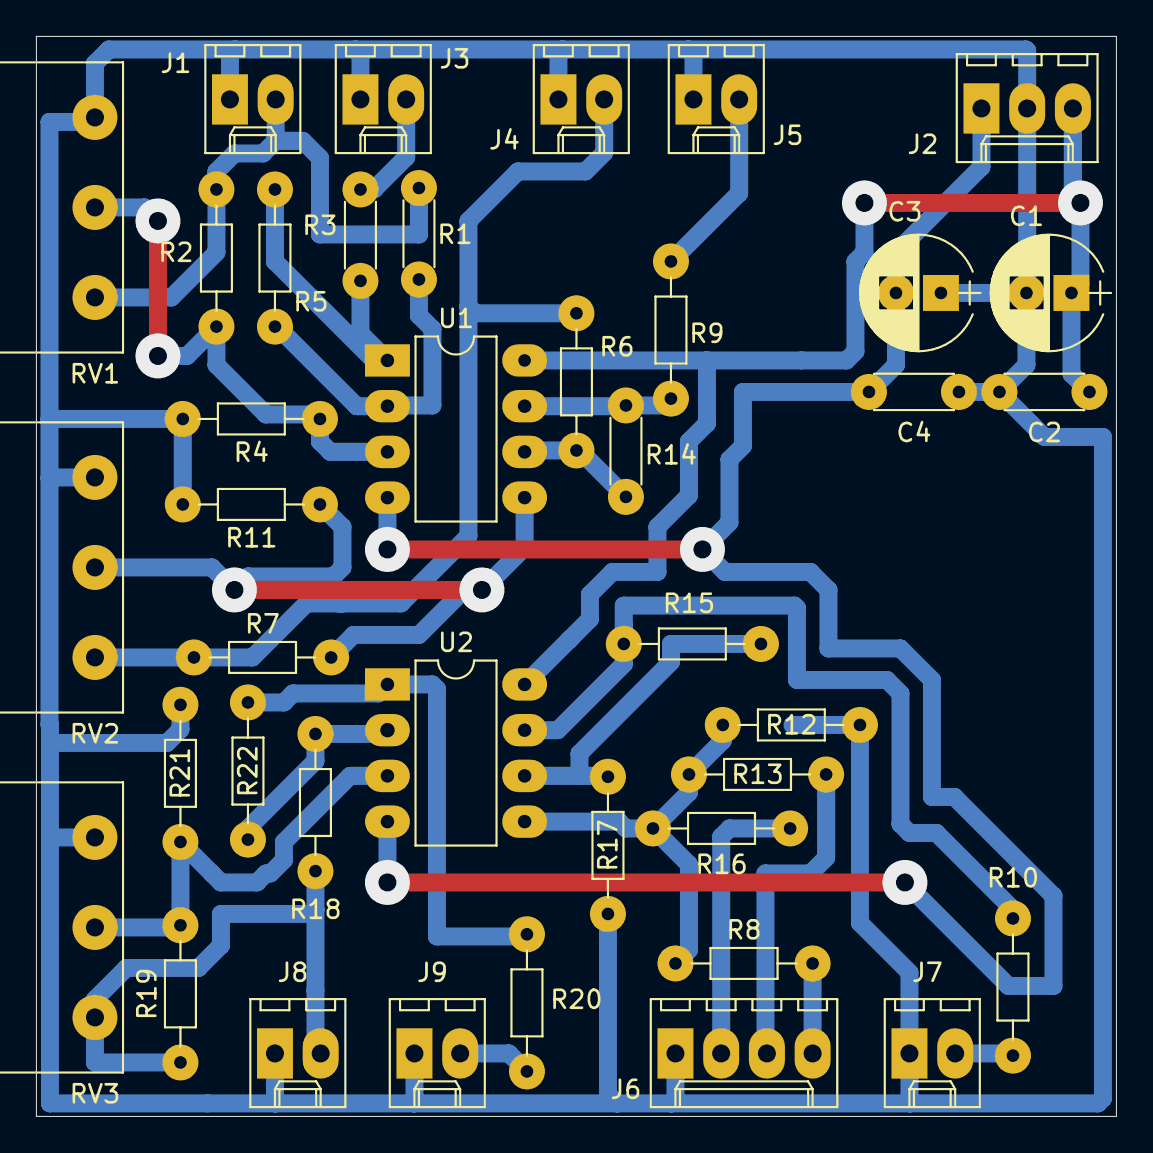
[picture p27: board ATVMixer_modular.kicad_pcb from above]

Board: 2 copper layers, 60.0 x 60.0 mm, 40 parts (0 on the bottom side), 25 nets.

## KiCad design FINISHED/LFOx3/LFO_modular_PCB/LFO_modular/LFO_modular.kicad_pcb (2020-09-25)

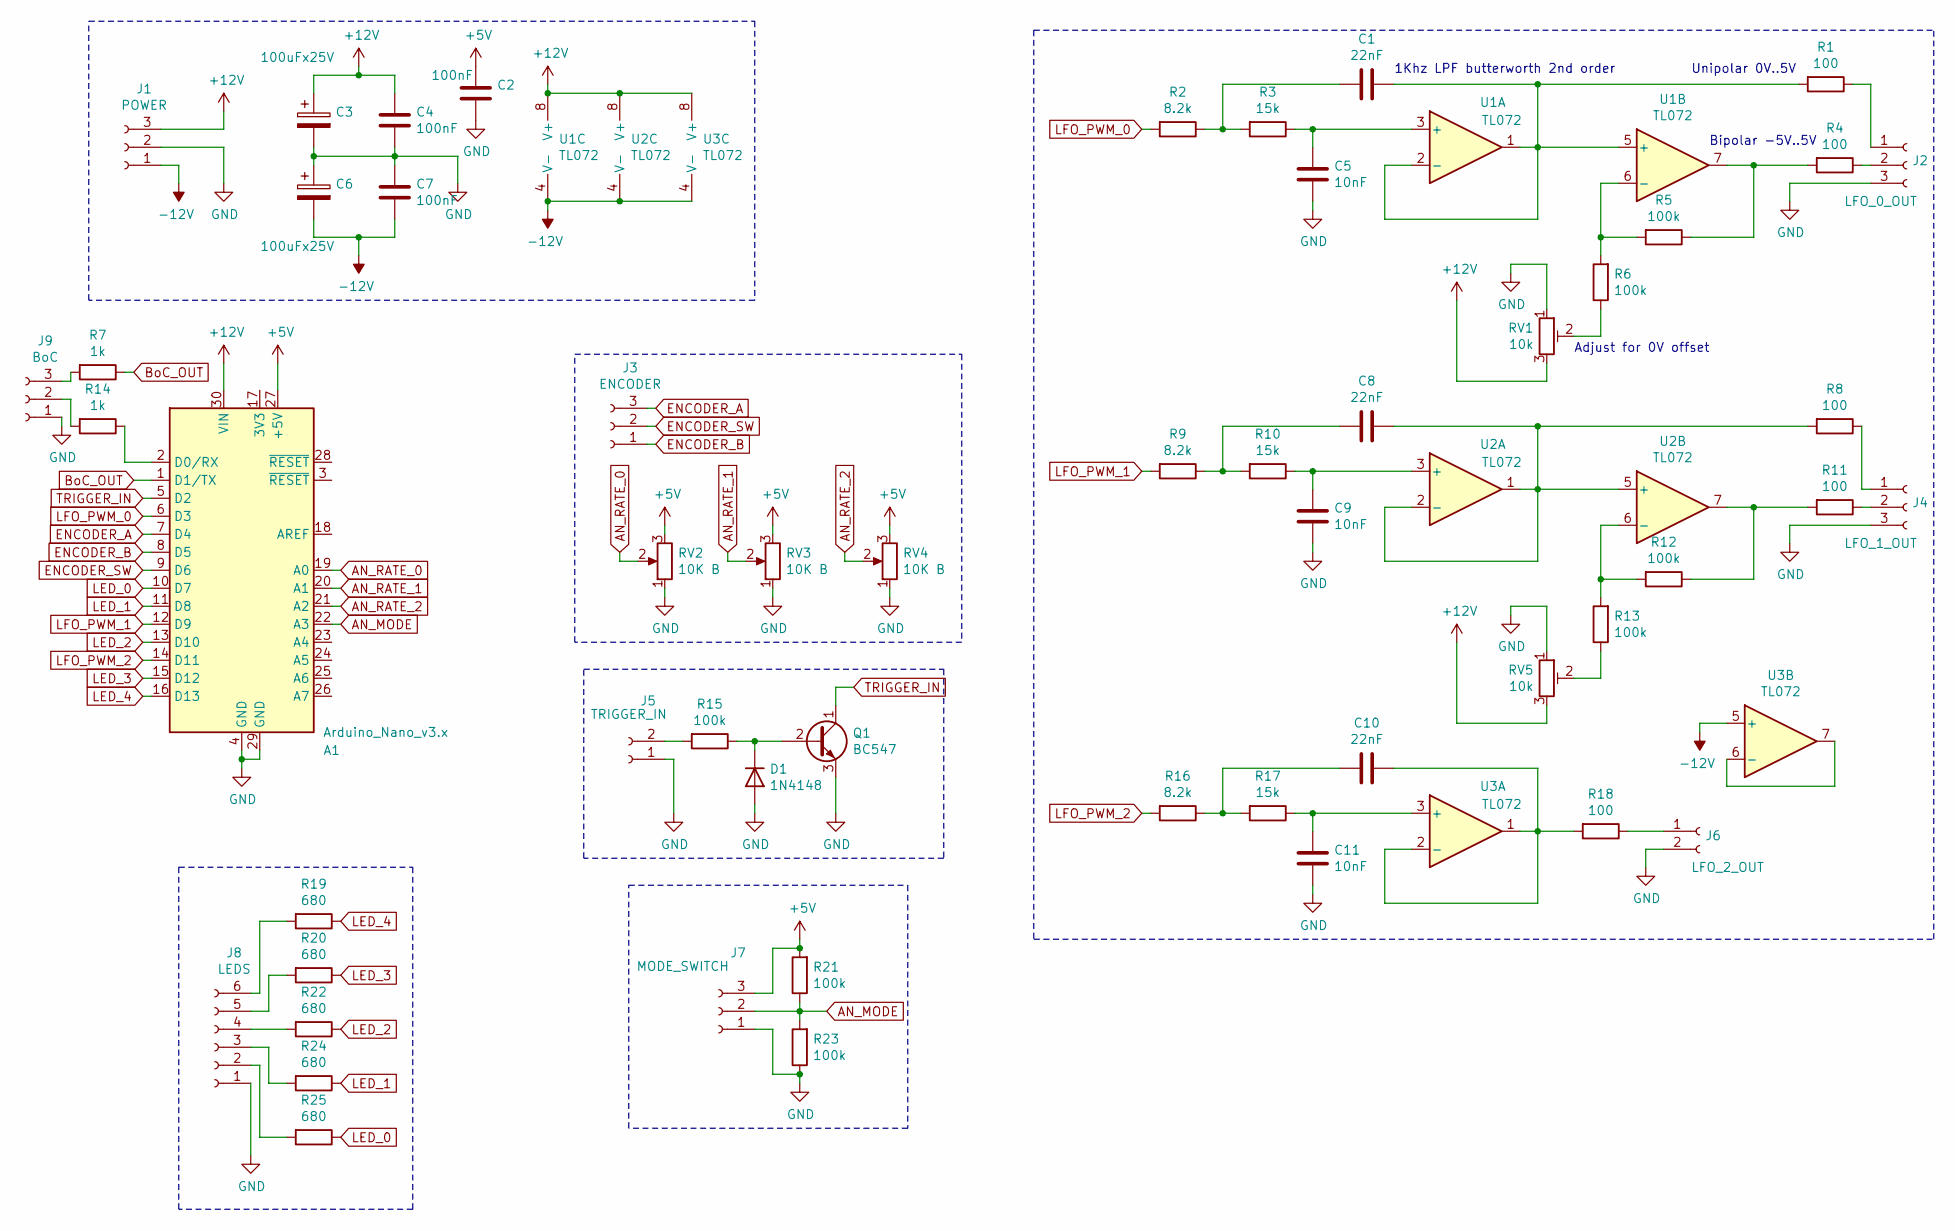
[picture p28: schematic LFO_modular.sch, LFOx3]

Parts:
A1: Arduino_Nano_v3.x; Arduino_Nano
C1, C8, C10: 22nF; C_Disc_D4.7mm_W2.5mm_P5.00mm
C2, C4, C7: 100nF; C_Disc_D4.7mm_W2.5mm_P5.00mm
C3, C6: 100uFx25V; CP_Radial_D6.3mm_P2.50mm
C5, C9, C11: 10nF; C_Disc_D4.7mm_W2.5mm_P5.00mm
D1: 1N4148; D_DO-35_SOD27_P7.62mm_Horizontal
J1: POWER; Molex_KK-6410-03_03x2.54mm_Straight
J2: LFO_0_OUT; Molex_KK-6410-03_03x2.54mm_Straight
J3: ENCODER; Molex_KK-6410-03_03x2.54mm_Straight
J4: LFO_1_OUT; Molex_KK-6410-03_03x2.54mm_Straight
J5: TRIGGER_IN; Molex_KK-6410-02_02x2.54mm_Straight
J6: LFO_2_OUT; Molex_KK-6410-02_02x2.54mm_Straight
J7: MODE_SWITCH; Molex_KK-6410-03_03x2.54mm_Straight
J8: LEDS; Molex_KK-6410-06_06x2.54mm_Straight
J9: BoC; Molex_KK-6410-03_03x2.54mm_Straight
Q1: BC547; TO-92_HandSolder
R1, R4, R8, R11, R18: 100; R_Axial_DIN0204_L3.6mm_D1.6mm_P7.62mm_Horizontal
R2, R9, R16: 8.2k; R_Axial_DIN0204_L3.6mm_D1.6mm_P7.62mm_Horizontal
R3, R10, R17: 15k; R_Axial_DIN0204_L3.6mm_D1.6mm_P7.62mm_Horizontal
R5, R6, R12, R13, R15, R21, R23: 100k; R_Axial_DIN0204_L3.6mm_D1.6mm_P7.62mm_Horizontal
R7, R14: 1k; R_Axial_DIN0204_L3.6mm_D1.6mm_P7.62mm_Horizontal
R19, R20, R22, R24, R25: 680; R_Axial_DIN0204_L3.6mm_D1.6mm_P7.62mm_Horizontal
RV1, RV5: 10k; Potentiometer_Trimmer_ACP_CA6v_Horizontal
RV2, RV3, RV4: 10K B; Potentiometer_Piher_PC-16_Single_Vertical
U1, U2, U3: TL072; DIP-8_W7.62mm_LongPads

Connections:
+5V: A1.27 (+5V), C2.1, J7.3, R21.2, RV2.3, RV3.3, RV4.3
+12V: A1.30 (VIN), C3.1, C4.1, J1.3, RV1.3, RV5.3, U1.8 (V+), U2.8 (V+), U3.8 (V+)
-12V: C6.2, C7.2, J1.1, U1.4 (V-), U2.4 (V-), U3.4 (V-), U3.5 (+)
AN_MODE: A1.22 (A3), J7.2, R21.1, R23.2
AN_RATE_0: A1.19 (A0), RV2.2
AN_RATE_1: A1.20 (A1), RV3.2
AN_RATE_2: A1.21 (A2), RV4.2
ENCODER_A: A1.7 (D4), J3.3
ENCODER_B: A1.8 (D5), J3.1
ENCODER_SW: A1.9 (D6), J3.2
GND: A1.4 (GND), A1.29 (GND), C2.2, C3.2, C4.2, C5.2, C6.1, C7.1, C9.2, C11.2, D1.2 (A), J1.2, J2.3, J4.3, J5.1, J6.2, J7.1, J8.1, J9.1, Q1.3 (E), R23.1, RV1.1, RV2.1, RV3.1, RV4.1, RV5.1
LED_0: A1.10 (D7), R25.1
LED_1: A1.11 (D8), R24.1
LED_2: A1.13 (D10), R22.1
LED_3: A1.15 (D12), R20.1
LED_4: A1.16 (D13), R19.1
LFO_PWM_0: A1.6 (D3), R2.2
LFO_PWM_1: A1.12 (D9), R9.2
LFO_PWM_2: A1.14 (D11), R16.2
unnamed: A1.1 (D1/TX), R7.1
unnamed: A1.2 (D0/RX), R14.1
unnamed: C1.1, R1.2, U1.1, U1.2 (-), U1.5 (+)
unnamed: C1.2, R2.1, R3.2
unnamed: C5.1, R3.1, U1.3 (+)
unnamed: C8.1, R8.2, U2.1, U2.2 (-), U2.5 (+)
unnamed: C8.2, R9.1, R10.2
unnamed: C9.1, R10.1, U2.3 (+)
unnamed: C10.1, R18.2, U3.1, U3.2 (-)
unnamed: C10.2, R16.1, R17.2
unnamed: C11.1, R17.1, U3.3 (+)
unnamed: D1.1 (K), Q1.2 (B), R15.1
unnamed: J2.1, R1.1
unnamed: J2.2, R4.1
unnamed: J4.1, R8.1
unnamed: J4.2, R11.1
unnamed: J5.2, R15.2
unnamed: J6.1, R18.1
unnamed: J8.2, R25.2
unnamed: J8.3, R24.2
unnamed: J8.4, R22.2
unnamed: J8.5, R20.2
unnamed: J8.6, R19.2
unnamed: J9.2, R14.2
unnamed: J9.3, R7.2
unnamed: R4.2, R5.1, U1.7
unnamed: R5.2, R6.2, U1.6 (-)
unnamed: R6.1, RV1.2
unnamed: R11.2, R12.1, U2.7
unnamed: R12.2, R13.2, U2.6 (-)
unnamed: R13.1, RV5.2
unnamed: U3.6 (-), U3.7
TRIGGER_IN: A1.5 (D2), Q1.1 (C)

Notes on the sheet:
Unipolar 0V..5V
Bipolar -5V..5V
1Khz LPF butterworth 2nd order
Adjust for 0V offset

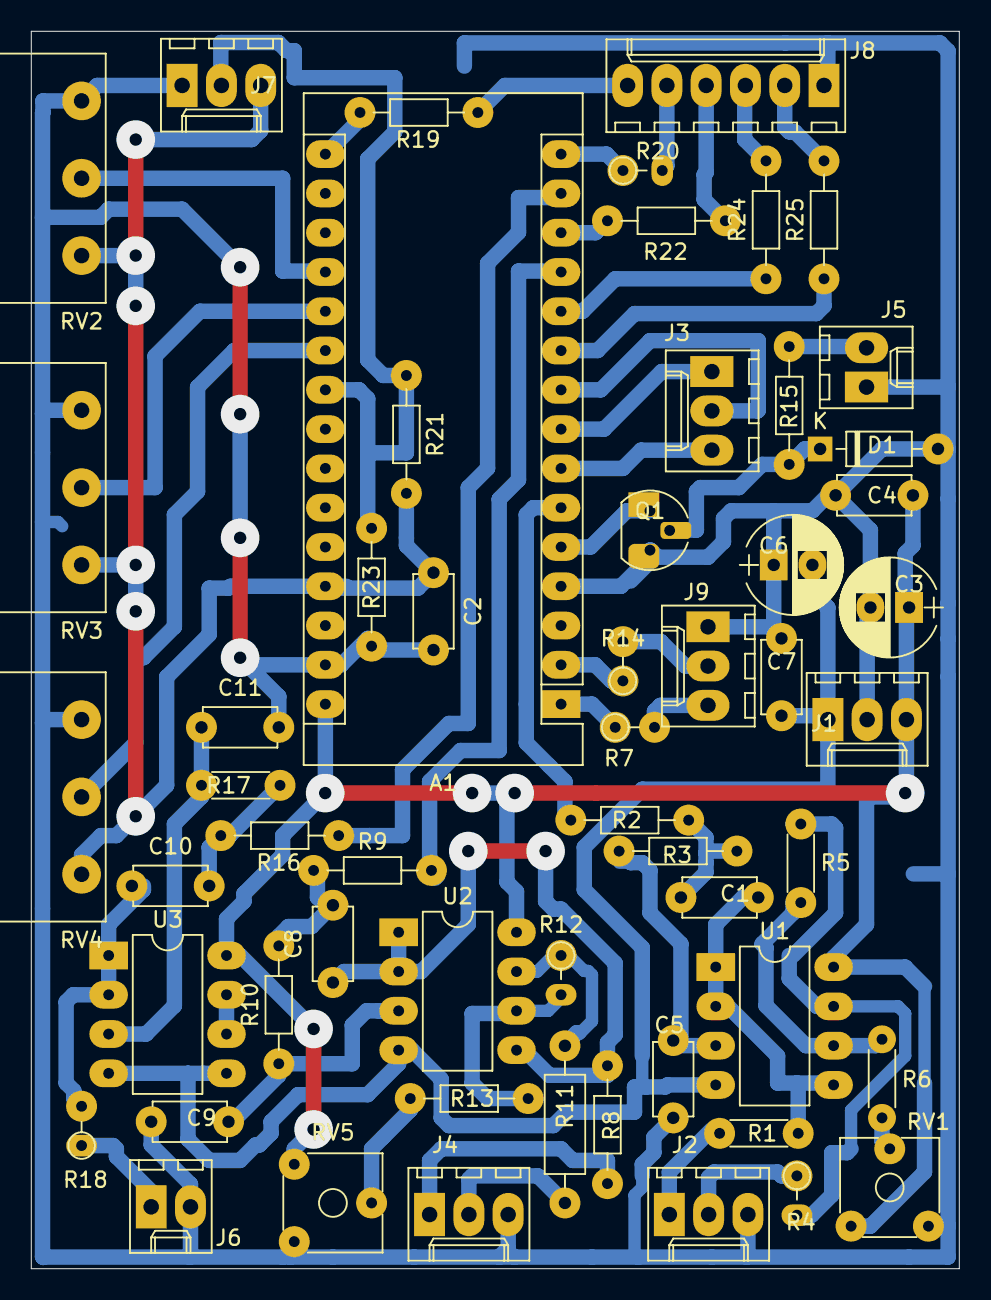
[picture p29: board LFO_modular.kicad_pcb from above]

Board: 2 copper layers, 60.0 x 80.0 mm, 56 parts (0 on the bottom side), 52 nets.

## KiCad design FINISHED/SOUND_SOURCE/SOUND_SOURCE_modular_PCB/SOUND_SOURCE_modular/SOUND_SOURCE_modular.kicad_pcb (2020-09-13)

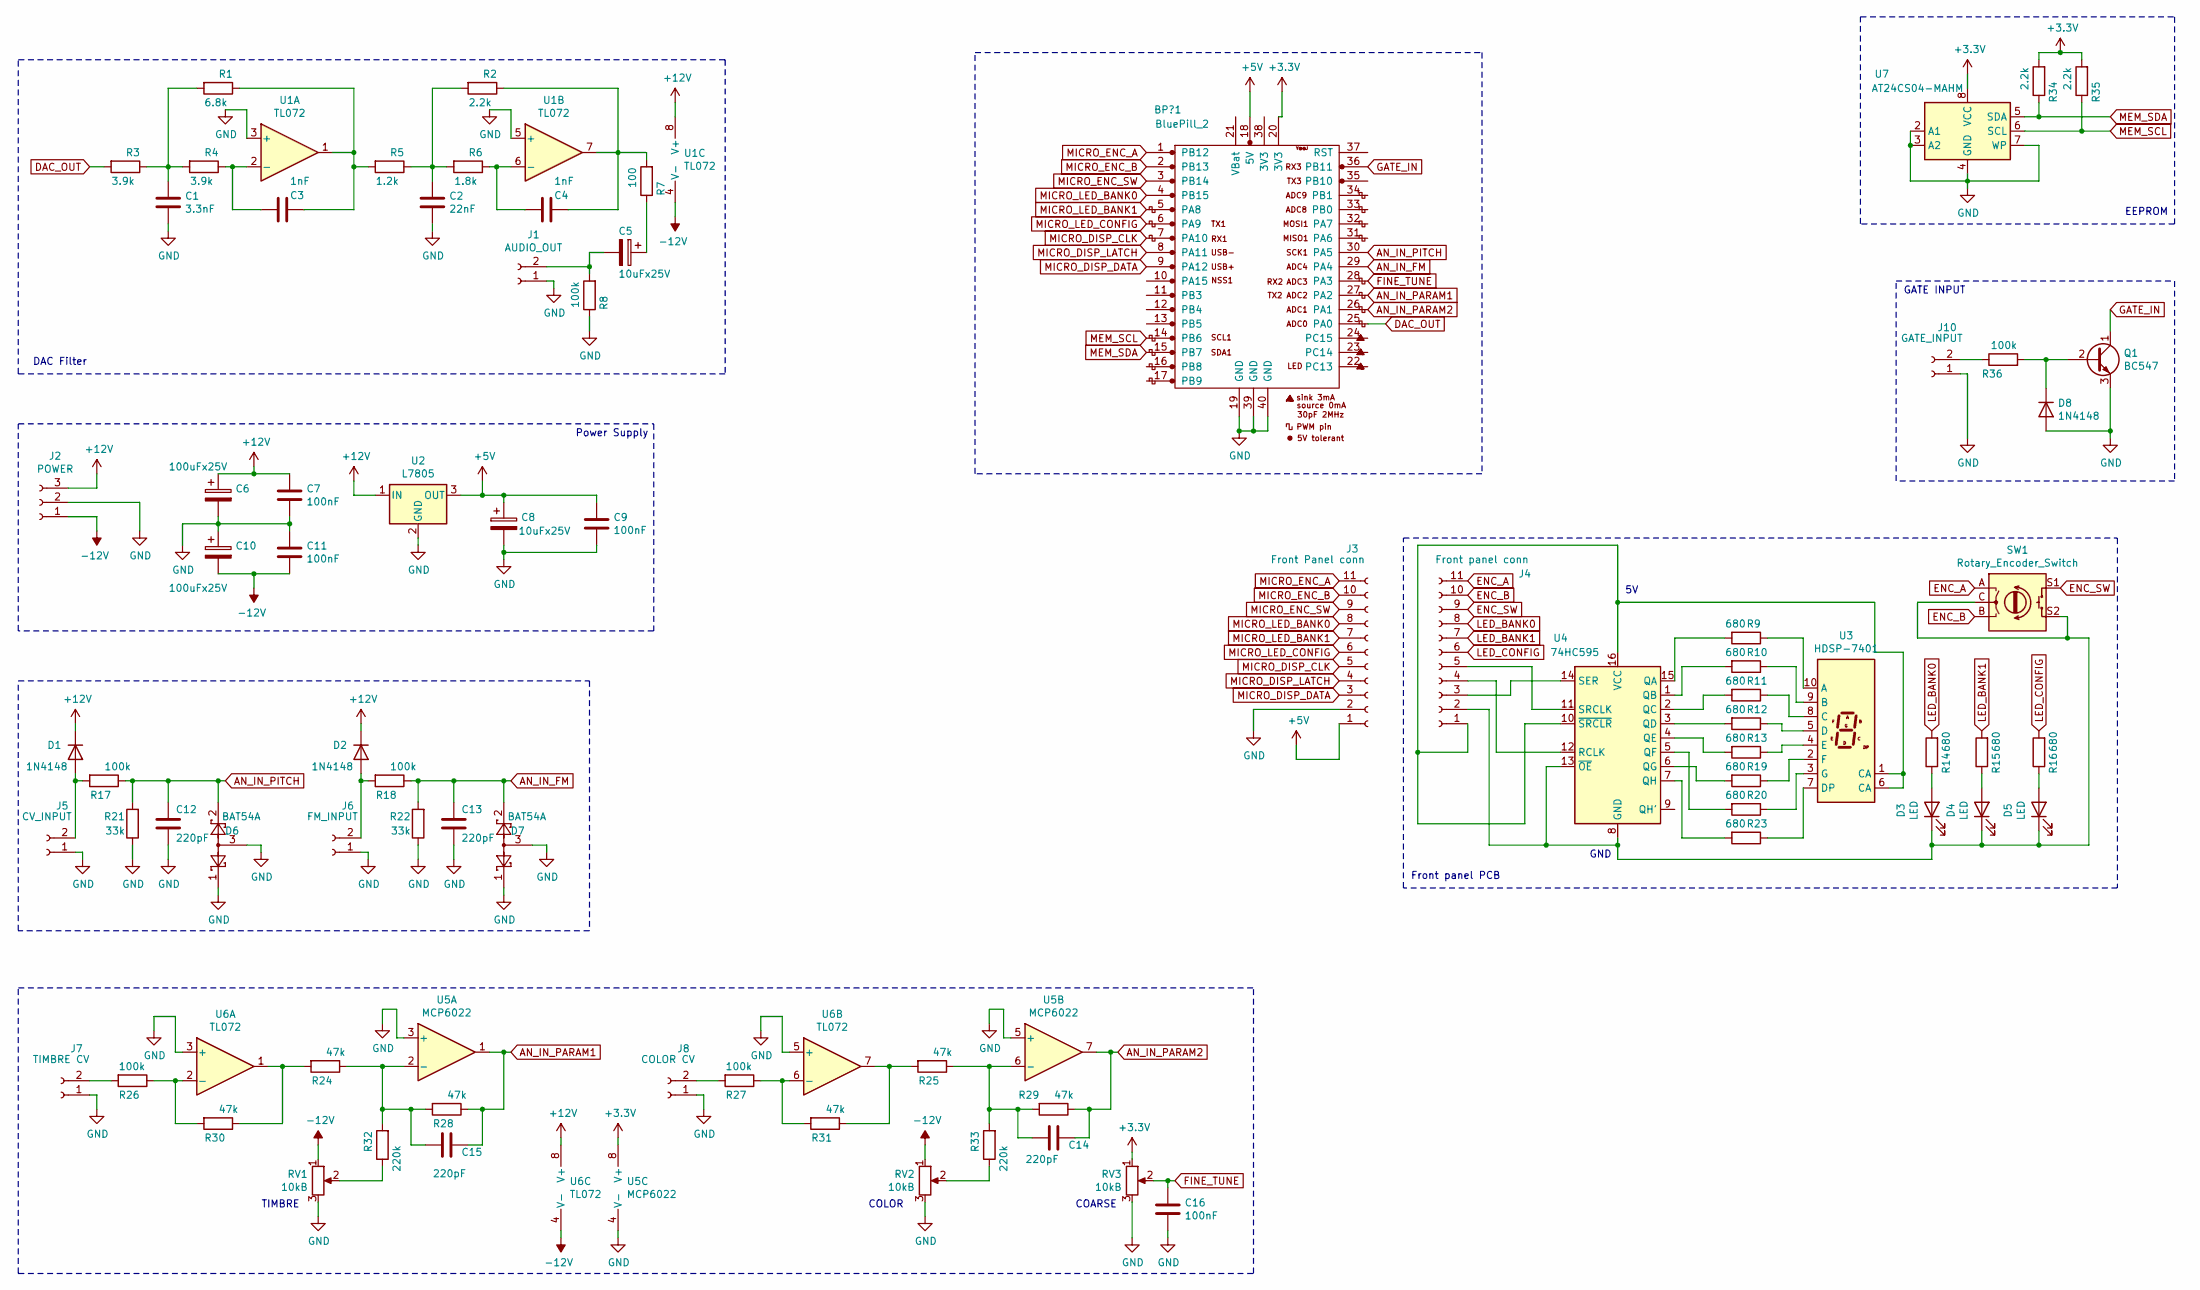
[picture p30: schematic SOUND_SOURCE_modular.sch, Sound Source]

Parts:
BP?1: BluePill_2; YAAJ_BluePill
C1: 3.3nF; C_Disc_D4.3mm_W1.9mm_P5.00mm
C2: 22nF; C_Disc_D4.3mm_W1.9mm_P5.00mm
C3, C4: 1nF; C_Disc_D4.3mm_W1.9mm_P5.00mm
C5, C8: 10uFx25V; CP_Radial_D5.0mm_P2.50mm
C6, C10: 100uFx25V; CP_Radial_D6.3mm_P2.50mm
C7, C9, C11, C16: 100nF; C_Disc_D4.3mm_W1.9mm_P5.00mm
C12, C13, C14, C15: 220pF; C_Disc_D4.3mm_W1.9mm_P5.00mm
D1, D2, D8: 1N4148; D_DO-35_SOD27_P7.62mm_Horizontal
D3, D4, D5: LED; LED_D3.0mm
D6, D7: BAT54A; SOT-23
J1: AUDIO_OUT; Molex_KK-6410-02_02x2.54mm_Straight
J2: POWER; Molex_KK-6410-03_03x2.54mm_Straight
J3: Front Panel conn; Molex_KK-6410-11_11x2.54mm_Straight
J4: Front panel conn; Molex_KK-6410-11_11x2.54mm_Straight
J5: CV_INPUT; Molex_KK-6410-02_02x2.54mm_Straight
J6: FM_INPUT; Molex_KK-6410-02_02x2.54mm_Straight
J7: TIMBRE CV; Molex_KK-6410-02_02x2.54mm_Straight
J8: COLOR CV; Molex_KK-6410-02_02x2.54mm_Straight
J10: GATE_INPUT; Molex_KK-6410-02_02x2.54mm_Straight
Q1: BC547; TO-92_Inline
R1: 6.8k; R_Axial_DIN0204_L3.6mm_D1.6mm_P7.62mm_Horizontal
R2, R34, R35: 2.2k; R_Axial_DIN0204_L3.6mm_D1.6mm_P7.62mm_Horizontal
R3, R4: 3.9k; R_Axial_DIN0204_L3.6mm_D1.6mm_P7.62mm_Horizontal
R5: 1.2k; R_Axial_DIN0204_L3.6mm_D1.6mm_P7.62mm_Horizontal
R6: 1.8k; R_Axial_DIN0204_L3.6mm_D1.6mm_P7.62mm_Horizontal
R7: 100; R_Axial_DIN0204_L3.6mm_D1.6mm_P7.62mm_Horizontal
R8, R17, R18, R26, R27, R36: 100k; R_Axial_DIN0204_L3.6mm_D1.6mm_P7.62mm_Horizontal
R9, R10, R11, R12, R13, R14, R15, R16, R19, R20, R23: 680; R_Axial_DIN0204_L3.6mm_D1.6mm_P7.62mm_Horizontal
R21, R22: 33k; R_Axial_DIN0204_L3.6mm_D1.6mm_P7.62mm_Horizontal
R24, R25, R28, R29, R30, R31: 47k; R_Axial_DIN0204_L3.6mm_D1.6mm_P7.62mm_Horizontal
R32, R33: 220k; R_Axial_DIN0204_L3.6mm_D1.6mm_P7.62mm_Horizontal
RV1, RV2, RV3: 10kB; Potentiometer_Piher_PC-16_Single_Vertical
SW1: Rotary_Encoder_Switch; RotaryEncoder_Alps_EC11E-Switch_Vertical_H20mm
U1, U6: TL072; DIP-8_W7.62mm_Socket_LongPads
U2: L7805; TO-220-3_Vertical
U3: HDSP-7401
U4: 74HC595; SOIC-16_3.9x9.9mm_Pitch1.27mm
U5: MCP6022; DIP-8_W7.62mm_Socket_LongPads
U7: AT24CS04-MAHM; DIP-8_W7.62mm_Socket_LongPads

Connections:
+3V3: BP?1.20 (3V3), R34.2, R35.2, RV3.1, U5.8 (V+), U7.8 (VCC)
+5V: BP?1.18 (5V), C8.1, C9.1, J3.1, U2.3 (OUT)
+12V: C6.1, C7.1, D1.1 (K), D2.1 (K), J2.3, U1.8 (V+), U2.1 (IN), U6.8 (V+)
-12V: C10.2, C11.2, J2.1, RV1.1, RV2.1, U1.4 (V-), U6.4 (V-)
AN_IN_FM: BP?1.29 (PA4), C13.1, D7.2, R18.1, R22.2
AN_IN_PARAM1: BP?1.27 (PA2), C15.1, R28.1, U5.1
AN_IN_PARAM2: BP?1.26 (PA1), C14.1, R29.1, U5.7
AN_IN_PITCH: BP?1.30 (PA5), C12.1, D6.2, R17.1, R21.2
DAC_OUT: BP?1.25 (PA0), R3.2
ENC_A: J4.11, SW1.A
ENC_B: J4.10, SW1.B
ENC_SW: J4.9, SW1.S1
FINE_TUNE: BP?1.28 (PA3), C16.1, RV3.2
GATE_IN: BP?1.36 (PB11), Q1.1 (C)
GND: BP?1.19 (GND), BP?1.39 (GND), BP?1.40 (GND), C1.2, C2.2, C6.2, C7.2, C8.2, C9.2, C10.1, C11.1, C12.2, C13.2, C16.2, D6.1, D6.3, D7.1, D7.3, D8.2 (A), J1.1, J2.2, J3.2, J5.1, J6.1, J7.1, J8.1, J10.1, Q1.3 (E), R8.1, R21.1, R22.1, RV1.3, RV2.3, RV3.3, U1.3 (+), U1.5 (+), U2.2 (GND), U5.3 (+), U5.4 (V-), U5.5 (+), U6.3 (+), U6.5 (+), U7.2 (A1), U7.3 (A2), U7.4 (GND), U7.7 (WP)
LED_BANK0: J4.8, R14.2
LED_BANK1: J4.7, R15.2
LED_CONFIG: J4.6, R16.2
MEM_SCL: BP?1.14 (PB6), R35.1, U7.6 (SCL)
MEM_SDA: BP?1.15 (PB7), R34.1, U7.5 (SDA)
MICRO_DISP_CLK: BP?1.7 (PA10), J3.5
MICRO_DISP_DATA: BP?1.9 (PA12), J3.3
MICRO_DISP_LATCH: BP?1.8 (PA11), J3.4
MICRO_ENC_A: BP?1.1 (PB12), J3.11
MICRO_ENC_B: BP?1.2 (PB13), J3.10
MICRO_ENC_SW: BP?1.3 (PB14), J3.9
MICRO_LED_BANK0: BP?1.4 (PB15), J3.8
MICRO_LED_BANK1: BP?1.5 (PA8), J3.7
MICRO_LED_CONFIG: BP?1.6 (PA9), J3.6
unnamed: C1.1, R1.2, R3.1, R4.2
unnamed: C2.1, R2.2, R5.1, R6.2
unnamed: C3.1, R1.1, R5.2, U1.1
unnamed: C3.2, R4.1, U1.2 (-)
unnamed: C4.1, R2.1, R7.2, U1.7
unnamed: C4.2, R6.1, U1.6 (-)
unnamed: C5.1, R7.1
unnamed: C5.2, J1.2, R8.2
unnamed: C14.2, R25.1, R29.2, R33.2, U5.6 (-)
unnamed: C15.2, R24.1, R28.2, R32.2, U5.2 (-)
unnamed: D1.2 (A), J5.2, R17.2
unnamed: D2.2 (A), J6.2, R18.2
unnamed: D3.1 (K), D4.1 (K), D5.1 (K), J4.2, SW1.C, SW1.S2, U4.8 (GND), U4.13 (~OE)
unnamed: D3.2 (A), R14.1
unnamed: D4.2 (A), R15.1
unnamed: D5.2 (A), R16.1
unnamed: D8.1 (K), Q1.2 (B), R36.2
unnamed: J4.1, U3.1 (CA), U3.6 (CA), U4.10 (~SRCLR), U4.16 (VCC)
unnamed: J4.3, U4.14 (SER)
unnamed: J4.4, U4.12 (RCLK)
unnamed: J4.5, U4.11 (SRCLK)
unnamed: J7.2, R26.2
unnamed: J8.2, R27.2
unnamed: J10.2, R36.1
unnamed: R9.1, U3.10 (A)
unnamed: R9.2, U4.15 (QA)
unnamed: R10.1, U3.9 (B)
unnamed: R10.2, U4.1 (QB)
unnamed: R11.1, U3.8 (C)
unnamed: R11.2, U4.2 (QC)
unnamed: R12.1, U3.5 (D)
unnamed: R12.2, U4.3 (QD)
unnamed: R13.1, U3.4 (E)
unnamed: R13.2, U4.4 (QE)
unnamed: R19.1, U3.2 (F)
unnamed: R19.2, U4.6 (QG)
unnamed: R20.1, U3.3 (G)
unnamed: R20.2, U4.5 (QF)
unnamed: R23.1, U3.7 (DP)
unnamed: R23.2, U4.7 (QH)
unnamed: R24.2, R30.1, U6.1
unnamed: R25.2, R31.1, U6.7
unnamed: R26.1, R30.2, U6.2 (-)
unnamed: R27.1, R31.2, U6.6 (-)
unnamed: R32.1, RV1.2
unnamed: R33.1, RV2.2

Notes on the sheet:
Power Supply
DAC Filter
Front panel PCB
COARSE
TIMBRE
COLOR
EEPROM
GATE INPUT
GND

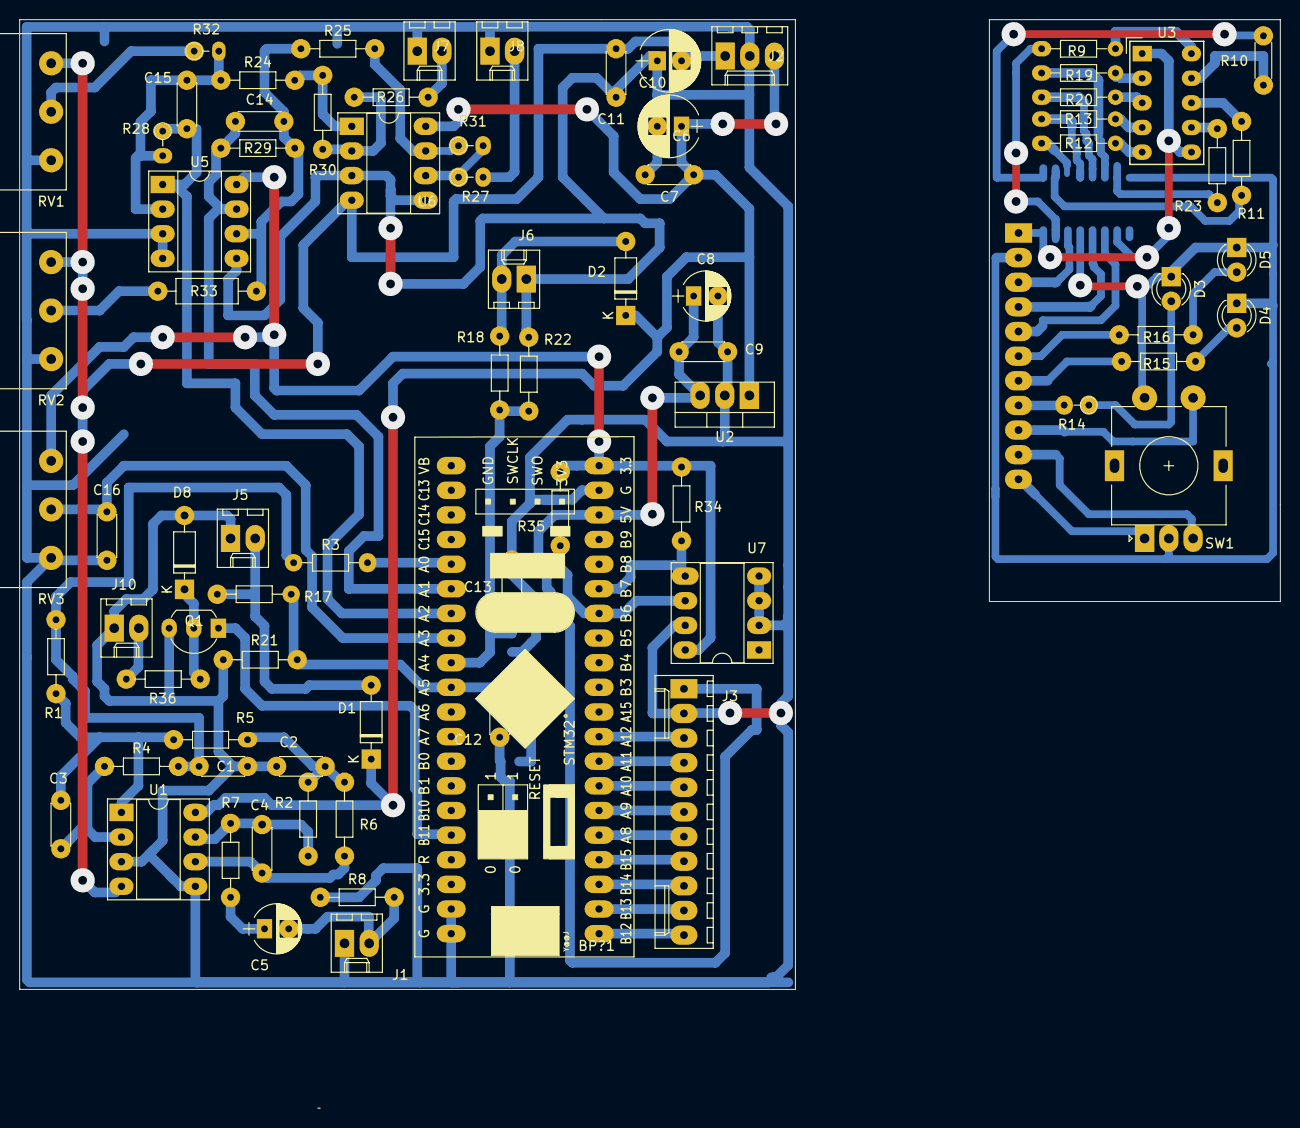
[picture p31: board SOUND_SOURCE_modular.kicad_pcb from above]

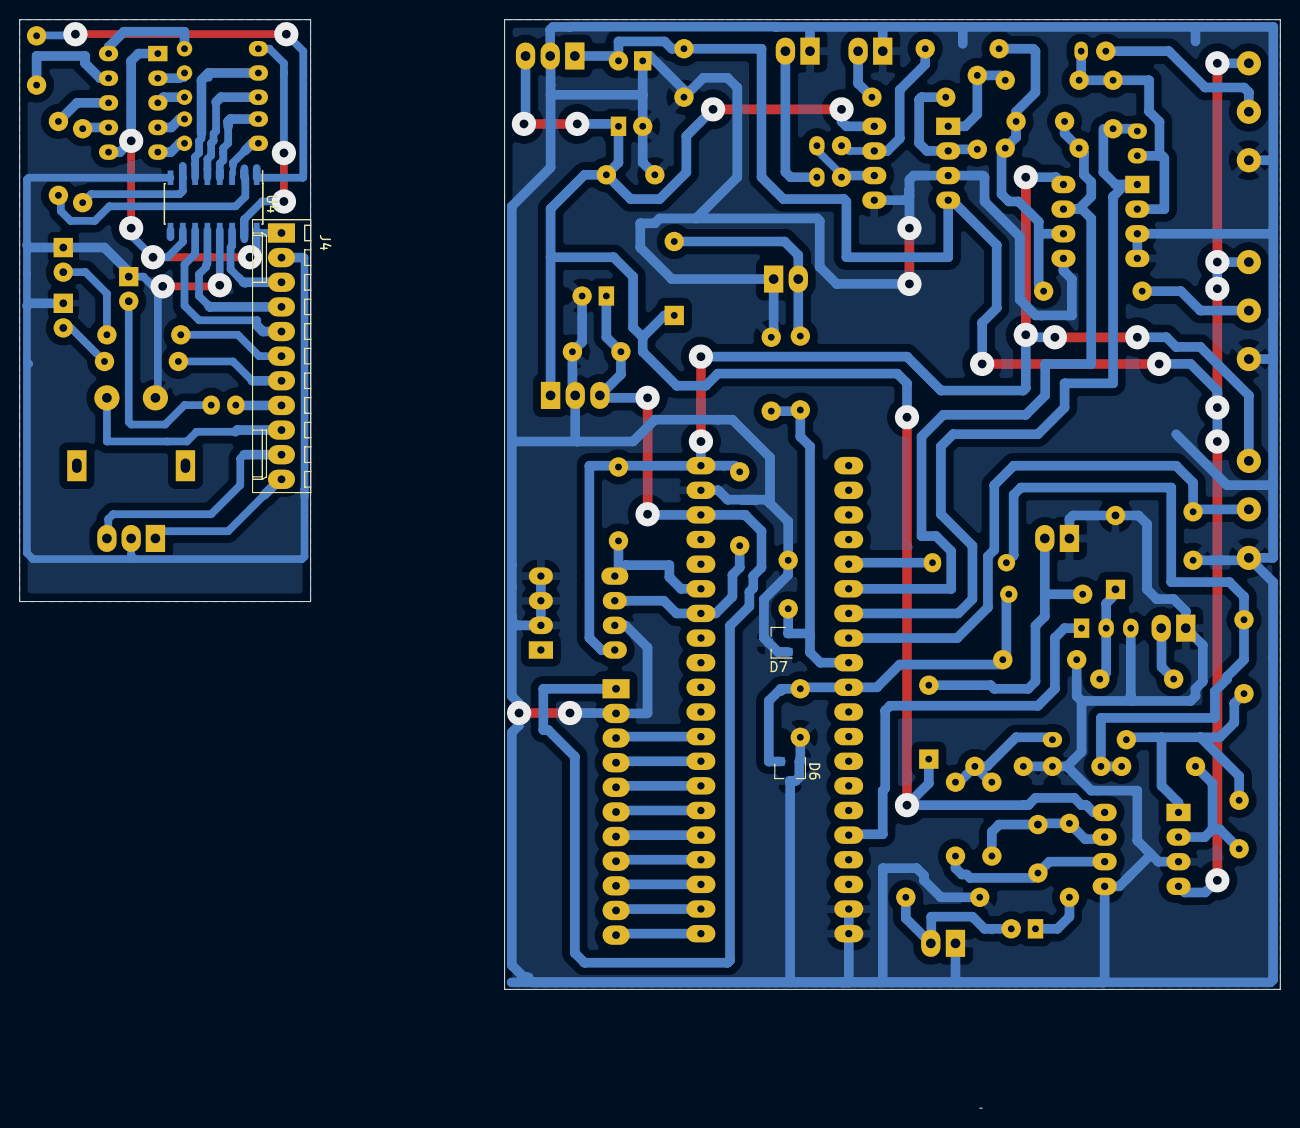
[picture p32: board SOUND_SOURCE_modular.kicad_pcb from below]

Board: 2 copper layers, 130.0 x 112.2 mm, 82 parts (4 on the bottom side), 75 nets.

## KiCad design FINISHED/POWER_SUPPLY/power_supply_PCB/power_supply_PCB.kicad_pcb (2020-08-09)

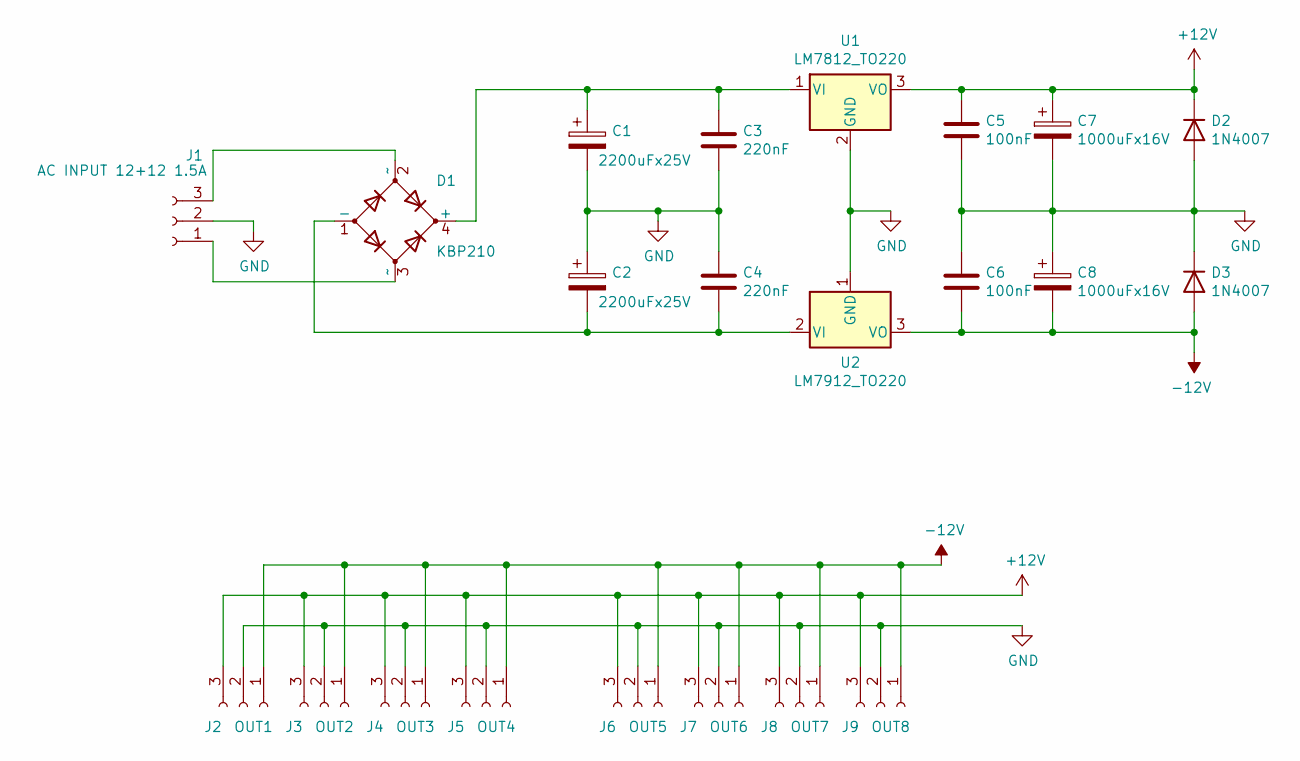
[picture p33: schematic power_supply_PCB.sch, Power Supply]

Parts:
C1, C2: 2200uFx25V; CP_Radial_D13.0mm_P5.00mm
C3, C4: 220nF; C_Disc_D11.0mm_W5.0mm_P7.50mm
C5, C6: 100nF; C_Disc_D5.0mm_W2.5mm_P5.00mm
C7, C8: 1000uFx16V; CP_Radial_D8.0mm_P3.50mm
D1: KBP210; Diode_Bridge_Vishay_KBU
D2, D3: 1N4007; D_DO-41_SOD81_P10.16mm_Horizontal
J1: AC INPUT 12+12 1.5A; TerminalBlock_Altech_AK300-3_P5.00mm
J2: OUT1; Molex_KK-6410-03_03x2.54mm_Straight
J3: OUT2; Molex_KK-6410-03_03x2.54mm_Straight
J4: OUT3; Molex_KK-6410-03_03x2.54mm_Straight
J5: OUT4; Molex_KK-6410-03_03x2.54mm_Straight
J6: OUT5; Molex_KK-6410-03_03x2.54mm_Straight
J7: OUT6; Molex_KK-6410-03_03x2.54mm_Straight
J8: OUT7; Molex_KK-6410-03_03x2.54mm_Straight
J9: OUT8; Molex_KK-6410-03_03x2.54mm_Straight
U1: LM7812_TO220; TO-220-3_Vertical
U2: LM7912_TO220; TO-220-3_Vertical

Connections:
+12V: C5.1, C7.1, D2.1 (K), J2.3, J3.3, J4.3, J5.3, J6.3, J7.3, J8.3, J9.3, U1.3 (VO)
-12V: C6.2, C8.2, D3.2 (A), J2.1, J3.1, J4.1, J5.1, J6.1, J7.1, J8.1, J9.1, U2.3 (VO)
GND: C1.2, C2.1, C3.2, C4.1, C5.2, C6.1, C7.2, C8.1, D2.2 (A), D3.1 (K), J1.2, J2.2, J3.2, J4.2, J5.2, J6.2, J7.2, J8.2, J9.2, U1.2 (GND), U2.1 (GND)
unnamed: C1.1, C3.1, D1.4 (+), U1.1 (VI)
unnamed: C2.2, C4.2, D1.1 (-), U2.2 (VI)
unnamed: D1.2 (~~), J1.3
unnamed: D1.3 (~~), J1.1


Board: 2 copper layers, 50.0 x 80.0 mm, 22 parts (0 on the bottom side), 7 nets.

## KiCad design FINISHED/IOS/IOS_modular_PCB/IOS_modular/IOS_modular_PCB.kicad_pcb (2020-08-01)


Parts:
C1, C6: 1uF; CP_Radial_D4.0mm_P2.00mm
C2, C4: 100uF x25V; CP_Radial_D6.3mm_P2.50mm
C3, C5: 100nF; C_Disc_D4.3mm_W1.9mm_P5.00mm
J1: MODULAR OUT; Molex_KK-6410-02_02x2.54mm_Straight
J2: LINE IN 2; Molex_KK-6410-02_02x2.54mm_Straight
J3: POWER IN; Molex_KK-6410-03_03x2.54mm_Straight
J4: LINE IN 1; Molex_KK-6410-02_02x2.54mm_Straight
J5: MODULAR IN 1; Molex_KK-6410-02_02x2.54mm_Straight
J6: LINE OUT 1; Molex_KK-6410-02_02x2.54mm_Straight
J7: MODULAR IN 2; Molex_KK-6410-02_02x2.54mm_Straight
J8: LINE OUT 2; Molex_KK-6410-02_02x2.54mm_Straight
R1, R8, R11: 100; R_Axial_DIN0204_L3.6mm_D1.6mm_P7.62mm_Horizontal
R2: 10k; R_Axial_DIN0204_L3.6mm_D1.6mm_P7.62mm_Horizontal
R3, R6, R7, R10: 100k; R_Axial_DIN0204_L3.6mm_D1.6mm_P7.62mm_Horizontal
R4, R9, R12: 47k; R_Axial_DIN0204_L3.6mm_D1.6mm_P7.62mm_Horizontal
R5: 220k; R_Axial_DIN0204_L3.6mm_D1.6mm_P7.62mm_Horizontal
RV1, RV2: 10K A; Potentiometer_Piher_PC-16_Single_Vertical
U1, U2: TL072; DIP-8_W7.62mm_Socket_LongPads

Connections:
+12V: C2.1, C3.1, J3.3, U1.8 (V+), U2.8 (V+)
-12V: C4.2, C5.2, J3.1, U1.4 (V-), U2.4 (V-)
GND: C2.2, C3.2, C4.1, C5.1, J1.2, J2.1, J3.2, J4.1, J5.1, J6.2, J7.1, J8.2, R9.1, R12.1, RV1.1, RV2.1, U1.3 (+), U1.5 (+)
unnamed: C1.1, J2.2
unnamed: C1.2, RV1.3
unnamed: C6.1, J4.2
unnamed: C6.2, RV2.3
unnamed: J1.1, R1.1
unnamed: J5.2, R7.2
unnamed: J6.1, R8.1, U2.2 (-)
unnamed: J7.2, R10.2
unnamed: J8.1, R11.1, U2.6 (-)
unnamed: R1.2, R4.1, U1.7
unnamed: R2.1, R4.2, U1.6 (-)
unnamed: R2.2, R5.1, U1.1
unnamed: R3.1, R5.2, R6.1, U1.2 (-)
unnamed: R3.2, RV1.2
unnamed: R6.2, RV2.2
unnamed: R7.1, R9.2, U2.3 (+)
unnamed: R8.2, U2.1
unnamed: R10.1, R12.2, U2.5 (+)
unnamed: R11.2, U2.7

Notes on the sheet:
LEVEL2
LEVEL1
Line to modular
Modular to line
Power stage
10Vpp
+4dBu
https://en.wikipedia.org/wiki/Line_level#/media/File:Line_levels.svg
-10dBV


Board: 2 copper layers, 50.0 x 50.0 mm, 30 parts (0 on the bottom side), 22 nets.

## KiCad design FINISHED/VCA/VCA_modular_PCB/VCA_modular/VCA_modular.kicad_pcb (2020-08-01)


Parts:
C1, C2, C3: 100nF; C_Disc_D4.3mm_W1.9mm_P5.00mm
C4, C5: 100uFx25V; CP_Radial_D6.3mm_P2.50mm
C6: 10pF; C_Disc_D4.3mm_W1.9mm_P5.00mm
C7, C8: 22nF; C_Disc_D4.3mm_W1.9mm_P5.00mm
C9: 1uFx25V; CP_Radial_D6.3mm_P2.50mm
J1: Audio_IN2_VCA; Molex_KK-6410-02_02x2.54mm_Straight
J2: Audio_IN1_VCA; Molex_KK-6410-02_02x2.54mm_Straight
J3: CV1_IN; Molex_KK-6410-02_02x2.54mm_Straight
J4: CV2_IN; Molex_KK-6410-02_02x2.54mm_Straight
J5: Audio_IN3; Molex_KK-6410-02_02x2.54mm_Straight
J6: POWER; Molex_KK-6410-03_03x2.54mm_Straight
J7: Audio_OUT; Molex_KK-6410-02_02x2.54mm_Straight
Q1, Q2, Q3: BC547; TO-92_Inline
R1: 47k; R_Axial_DIN0204_L3.6mm_D1.6mm_P7.62mm_Horizontal
R2: 4.7k; R_Axial_DIN0204_L3.6mm_D1.6mm_P7.62mm_Horizontal
R3, R9, R10, R28: 100k; R_Axial_DIN0204_L3.6mm_D1.6mm_P7.62mm_Horizontal
R4, R5: 68k; R_Axial_DIN0204_L3.6mm_D1.6mm_P7.62mm_Horizontal
R6, R7, R8, R20, R21, R23, R24: 220k; R_Axial_DIN0204_L3.6mm_D1.6mm_P7.62mm_Horizontal
R11, R13, R25: 10k; R_Axial_DIN0204_L3.6mm_D1.6mm_P7.62mm_Horizontal
R12: 470; R_Axial_DIN0204_L3.6mm_D1.6mm_P7.62mm_Horizontal
R14, R17: 15k 1%; R_Axial_DIN0204_L3.6mm_D1.6mm_P7.62mm_Horizontal
R15: 33k; R_Axial_DIN0204_L3.6mm_D1.6mm_P7.62mm_Horizontal
R16: 15k; R_Axial_DIN0204_L3.6mm_D1.6mm_P7.62mm_Horizontal
R18, R19: 10k 1%; R_Axial_DIN0204_L3.6mm_D1.6mm_P7.62mm_Horizontal
R22: 330k; R_Axial_DIN0204_L3.6mm_D1.6mm_P7.62mm_Horizontal
R26: 22k; R_Axial_DIN0204_L3.6mm_D1.6mm_P7.62mm_Horizontal
R27: 100; R_Axial_DIN0204_L3.6mm_D1.6mm_P7.62mm_Horizontal
RV1, RV4: 50K A; Potentiometer_Piher_PC-16_Single_Vertical
RV2: 100K B; Potentiometer_Piher_PC-16_Single_Vertical
RV3: 10K B; Potentiometer_Piher_PC-16_Single_Vertical
RV5: 50k; Potentiometer_Trimmer_ACP_CA6v_Horizontal
RV6: 10k; Potentiometer_Trimmer_ACP_CA6v_Horizontal
RV7: 100k; Potentiometer_Trimmer_ACP_CA6v_Horizontal
U1, U2: TL072; DIP-8_W7.62mm_LongPads

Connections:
+12V: C2.1, C4.1, J6.3, R2.2, RV5.1, RV6.2, RV7.3, U1.8 (V+), U2.8 (V+)
-12V: C3.2, C5.2, J6.1, R16.1, RV5.3, RV7.1, U1.4 (V-), U2.4 (V-)
GND: C1.2, C2.2, C3.1, C4.2, C5.1, C7.1, J1.1, J2.1, J3.1, J4.1, J5.1, J6.2, J7.2, Q2.1 (C), Q3.2 (B), R1.1, R12.1, R20.2, R25.1, R28.1, RV1.1, RV2.1, RV3.1, RV4.1, U1.3 (+), U1.5 (+)
unnamed: C1.1, R3.1, R4.1, R5.1, R9.2, U1.6 (-)
unnamed: C6.1, C8.2, R21.1, U2.1
unnamed: C6.2, R19.1, R21.2, U2.2 (-)
unnamed: C7.2, Q2.2 (B), R11.2, R13.2
unnamed: C8.1, R23.1
unnamed: C9.1, R27.1
unnamed: C9.2, J7.1, R28.2
unnamed: J1.2, R1.2, R6.2
unnamed: J2.2, RV1.3
unnamed: J3.2, RV2.3
unnamed: J4.2, R5.2
unnamed: J5.2, RV4.3
unnamed: Q1.1 (C), R14.1, R18.2
unnamed: Q1.2 (B), R10.1, R12.2
unnamed: Q1.3 (E), Q3.3 (E), R15.2
unnamed: Q2.3 (E), R15.1, R16.2
unnamed: Q3.1 (C), R17.1, R19.2
unnamed: R2.1, RV3.3
unnamed: R3.2, RV3.2
unnamed: R4.2, RV2.2
unnamed: R6.1, R7.1, R8.2, U1.2 (-)
unnamed: R7.2, RV1.2
unnamed: R8.1, R10.2, U1.1
unnamed: R9.1, R11.1, U1.7
unnamed: R13.1, RV5.2
unnamed: R14.2, RV6.1
unnamed: R17.2, RV6.3
unnamed: R18.1, R20.1, R22.1, U2.3 (+)
unnamed: R22.2, RV7.2
unnamed: R23.2, R24.1, U2.5 (+)
unnamed: R24.2, RV4.2
unnamed: R25.2, R26.2, U2.6 (-)
unnamed: R26.1, R27.2, U2.7

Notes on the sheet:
Input1 Level
Control Level CV1
GAIN
Matched transistors
Input 3 Level


Board: 2 copper layers, 50.0 x 80.0 mm, 56 parts (0 on the bottom side), 36 nets.

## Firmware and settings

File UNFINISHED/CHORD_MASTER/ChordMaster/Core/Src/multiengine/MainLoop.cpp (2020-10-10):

/*
 *  Sound Source. Macro-oscillator using Blue Pill. Based on Mutable Instruments Braids.
    Copyright (C) 2020  Ernesto Gigliotti. ernestogigliotti@gmail.com

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
    You should have received a copy of the GNU General Public License
    along with this program.  If not, see <https://www.gnu.org/licenses/>.
 */


#include "MainLoop.h"
#include "hal/MultiEngineHAL.h"
#include "hal/Memory.h"

#include "braids/macro_oscillator.h"
#include "braids/envelope.h"
#include "braids/drivers/adc.h"
#include "braids/quantizer.h"
#include "braids/signature_waveshaper.h"
#include "stmlib/system/uid.h"
#include "braids/quantizer_scales.h"
#include "braids/vco_jitter_source.h"


#include "Ui.h"
#include "ChordManager.h"



#define SAMPLES_BUFFER_SIZE		48
static uint8_t samplesBuffer[SAMPLES_BUFFER_SIZE];
static volatile uint8_t flagRender;
static volatile uint8_t indexBufferRender;

using namespace braids;

static uint8_t sync_samples[SAMPLES_BUFFER_SIZE/2];
static MacroOscillator osc;
static Envelope envelope;
static Adc adc;
static volatile bool trigger_flag;
static Quantizer quantizer;
//static SignatureWaveshaper ws;
static uint8_t current_scale = 0xff;
static Ui userInterface;
static uint8_t sysTickDivisor=0;
static Memory memory;
//static VcoJitterSource jitter_source;  // Not implemented. speed is not good enough
static ChordManager chordManager;

const uint16_t bit_reduction_masks[] = {
    0xc000,
    0xe000,
    0xf000,
    0xf800,
    0xff00,
    0xfff0,
    0xffff };
const uint16_t decimation_factors[] = { 24, 12, 6, 4, 3, 2, 1 };


static uint32_t flagTriggerInEvent=0;




static void callbackRender(int flagEndHalf)
{
	flagRender = 1;
	if(flagEndHalf==1)
	{
		// there is end of transfer, so I can start writing the second half of the buffer
		indexBufferRender=1;
	}
	else
	{
		// transfer reach half, so I can start writing the first half
		indexBufferRender=0;
	}
}


void MainLoop::init(void)
{
	int i;
	for(i=0; i<SAMPLES_BUFFER_SIZE; i++)
	{
		samplesBuffer[i] = 0;
	}
    memset(sync_samples, 0, SAMPLES_BUFFER_SIZE/2);

	mehal_init((uint32_t*)samplesBuffer,SAMPLES_BUFFER_SIZE,callbackRender);

	settings.Init();
	osc.Init();
	quantizer.Init();
	envelope.Init();
	//jitter_source.Init();
	adc.Init();
	userInterface.init(&adc,&memory);
	//ws.Init(GetUniqueId(1));
	chordManager.init();


	// calibration
	int32_t adc_code_c2=memory.readUInt32(Memory::ADDR_ADC_CODE_C2);
	if(adc_code_c2<0 || adc_code_c2>4095) adc_code_c2=82;

	int32_t adc_code_c4=memory.readUInt32(Memory::ADDR_ADC_CODE_C4);
	if(adc_code_c4<0 || adc_code_c4>4095) adc_code_c4=671;

	int32_t adc_code_fm=memory.readUInt32(Memory::ADDR_ADC_CODE_FM);
	if(adc_code_fm<0 || adc_code_fm>4095) adc_code_fm=0;

	int32_t adc_code_p0_min= memory.readUInt32(Memory::ADDR_ADC_CODE_P0_MIN);
	if(adc_code_p0_min<0 || adc_code_p0_min>4095) adc_code_p0_min=0;

	int32_t adc_code_p0_max= memory.readUInt32(Memory::ADDR_ADC_CODE_P0_MAX);
	if(adc_code_p0_max<0 || adc_code_p0_max>4095) adc_code_p0_max=4095;

	int32_t adc_code_p1_min= memory.readUInt32(Memory::ADDR_ADC_CODE_P1_MIN);
	if(adc_code_p1_min<0 || adc_code_p1_min>4095) adc_code_p1_min=0;

	int32_t adc_code_p1_max= memory.readUInt32(Memory::ADDR_ADC_CODE_P1_MAX);
	if(adc_code_p1_max<0 || adc_code_p1_max>4095) adc_code_p1_max=4095;

	settings.Calibrate(adc_code_c2,adc_code_c4,adc_code_fm,adc_code_p0_min,adc_code_p0_max,adc_code_p1_min,adc_code_p1_max);
	//________________________________

	settings.SetValue(SETTING_RESOLUTION,RESOLUTION_8_BIT);
	settings.SetValue(SETTING_PITCH_OCTAVE,1); // C2: Lowest octave

}



void MainLoop::loop(void)
{
	userInterface.loop();

	// Gate event
	/*
	static uint8_t prevGate=1;
	uint8_t currentGate = mehal_readGateInput();
	if(currentGate==0 && prevGate==1)
	{
		trigger_flag=true;
		flagTriggerInEvent=1;
	}
	prevGate = currentGate;
	*/
	//____________

	// Scale manager
    if (current_scale != settings.GetValue(SETTING_QUANTIZER_SCALE)) {
      current_scale = settings.GetValue(SETTING_QUANTIZER_SCALE);
      quantizer.Configure(scales[current_scale]);
    }
    //______________

    // Read Analog values
    this->adcStateMachine();
    //____________________

    // Render event
	if(flagRender==1)
	{
		uint8_t* out;
		if(indexBufferRender==0)
		{
			out = samplesBuffer;
		}
		else
		{
			out = samplesBuffer+(SAMPLES_BUFFER_SIZE/2);
		}

		// render signal
		mehal_debugPinSet();
		this->render(out,SAMPLES_BUFFER_SIZE/2);
		mehal_debugPinReset();
		//______________

		// update UI
		sysTickDivisor++;
		if(sysTickDivisor>=4)
		{
			userInterface.sysTick(); // 1ms
			sysTickDivisor=0;
		}
		//__________


		userInterface.justFinishedRender(); // notify the UI the render has finished. Now there is time to update the display

		flagRender=0;
	}
	//______________
}

void MainLoop::render(uint8_t* out, uint32_t outSize)
{
	  static int16_t previous_pitch = 0;
	  static uint16_t gain_lp;

	  // Envelope management
	  envelope.Update(
	      settings.GetValue(SETTING_AD_ATTACK) * 8,
	      settings.GetValue(SETTING_AD_DECAY) * 8);
	  uint32_t ad_value = envelope.Render();
	  //____________________

	  // Set shape (not used)
	  osc.set_shape(settings.shape());
	  // Set waveform with param0
	  osc.set_parameters(userInterface.getParamFromCurrentWaveTable(),0);


	  // SET PITCH
	  // Apply hysteresis to ADC reading to prevent a single bit error to move
	  // the quantized pitch up and down the quantization boundary.
	  int32_t pitch = quantizer.Process(
	      settings.adc_to_pitch(adc.channel(ADC_CHANNEL_PITCH)),
	      (60 + settings.quantizer_root()) << 7);
	  // Check if the pitch has changed to cause an auto-retrigger
	  int32_t pitch_delta = pitch - previous_pitch;
	  if (settings.data().auto_trig &&
	      //(pitch_delta >= 0x40 || -pitch_delta >= 0x40)) {
			(pitch_delta >= 0x70 || -pitch_delta >= 0x70)) { // too much noise in this hardware
		  trigger_flag = true;
	  }
	  previous_pitch = pitch;
	  if (pitch > 16383) {
	    pitch = 16383;
	  } else if (pitch < 0) {
	    pitch = 0;
	  }
	  //_________________________________________________________________


	  // Set chords and pitch
	  int32_t qualityValue = settings.adc_to_parameter(0, adc.channel(ADC_CHANNEL_PARAM0));
	  int32_t variationValue = settings.adc_to_parameter(1, adc.channel(ADC_CHANNEL_PARAM1));
	  int32_t voicingValue = settings.adc_to_fm(adc.channel(ADC_CHANNEL_FM));

	  chordManager.calculateVoicings( pitch + settings.pitch_transposition(),
			  	  	  	  	  	  	  qualityValue,
									  variationValue,
									  voicingValue,
									  (60 + settings.quantizer_root()) << 7);
	  osc.set_chords_parameters(chordManager.getChord1(),chordManager.getChord2(),chordManager.getChord3());
	  osc.set_pitch(chordManager.getPitch());
	  //_________________________________________________



	  // TRIGGER
	  if (trigger_flag) {
	    osc.Strike();
	    envelope.Trigger(ENV_SEGMENT_ATTACK);
	    trigger_flag = false;
	  }
	  //_________


	  // RENDER
	  int16_t audio_samples[outSize];
	  uint8_t* sync_buffer = sync_samples;
	  int16_t* render_buffer = audio_samples;

	  if (settings.GetValue(SETTING_AD_VCA) != 0
	    || settings.GetValue(SETTING_AD_TIMBRE) != 0
	    || settings.GetValue(SETTING_AD_COLOR) != 0
	    || settings.GetValue(SETTING_AD_FM) != 0) {
	    memset(sync_buffer, 0, outSize);
	  }
	  else
	  {
		  //Trigger in sync event (this is placed in sampler interrupt timer in braids)
		  memset(sync_buffer, 0, outSize);
		  if(flagTriggerInEvent==1)
		  {
			  flagTriggerInEvent=0;
			  sync_buffer[0]=1;
		  }
		  //______________________
	  }

	  osc.Render(sync_buffer, render_buffer, outSize);

	  // Copy to DAC buffer with sample rate and bit reduction applied.
	    int16_t sample = 0;
	    size_t decimation_factor = decimation_factors[settings.data().sample_rate];
	    uint16_t bit_mask = bit_reduction_masks[settings.data().resolution];
	    int32_t gain = settings.GetValue(SETTING_AD_VCA) ? ad_value : 65535;
	    uint16_t signature = settings.signature() * settings.signature() * 4095;
	    for (size_t i = 0; i < outSize; ++i) {
	      if ((i % decimation_factor) == 0) {
	        sample = render_buffer[i] & bit_mask;
	      }
	      sample = sample * gain_lp >> 16;
	      gain_lp += (gain - gain_lp) >> 4;
	      int16_t warped = 0; //ws.Transform(sample); // there is not enough RAM for this
	      render_buffer[i] = Mix(sample, warped, signature);
	    }

	  // Copy rendered buffer to DMA buffer (8bits)
	  uint32_t i;
	  for(i=0; i<outSize; i++)
	  {
		  out[i] = (uint8_t) (((uint16_t)(  -(render_buffer[i]) + 32768U )) >>8)  ;
	  }
	  //___________________________________________

}


void MainLoop::adcStateMachine(void)
{
	static uint8_t chn=0;

	adc.updateChannelValue(chn,mehal_readADC(chn));

	chn++;
	if(chn>=ADC_CHANNELS)
	{
		chn=0;
	}

}

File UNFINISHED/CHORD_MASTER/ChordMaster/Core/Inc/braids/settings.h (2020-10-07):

// Copyright 2012 Emilie Gillet.
//
// Author: Emilie Gillet (emilie.o.gillet@gmail.com)
//
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
// See http://creativecommons.org/licenses/MIT/ for more information.
//
// -----------------------------------------------------------------------------
//
// Settings

#ifndef BRAIDS_SETTINGS_H_
#define BRAIDS_SETTINGS_H_

#include "stmlib/stmlib.h"

namespace braids {

enum MacroOscillatorShape {
  MACRO_OSC_SHAPE_CSAW,
  MACRO_OSC_SHAPE_MORPH,
  MACRO_OSC_SHAPE_SAW_SQUARE,
  MACRO_OSC_SHAPE_SINE_TRIANGLE,
  MACRO_OSC_SHAPE_BUZZ,
  
  MACRO_OSC_SHAPE_SQUARE_SUB,
  MACRO_OSC_SHAPE_SAW_SUB,
  MACRO_OSC_SHAPE_SQUARE_SYNC,
  MACRO_OSC_SHAPE_SAW_SYNC,
  MACRO_OSC_SHAPE_TRIPLE_SAW,
  MACRO_OSC_SHAPE_TRIPLE_SQUARE,
  MACRO_OSC_SHAPE_TRIPLE_TRIANGLE,
  MACRO_OSC_SHAPE_TRIPLE_SINE,
  MACRO_OSC_SHAPE_TRIPLE_RING_MOD,
  MACRO_OSC_SHAPE_SAW_SWARM,
  MACRO_OSC_SHAPE_SAW_COMB,
  MACRO_OSC_SHAPE_TOY,

  MACRO_OSC_SHAPE_DIGITAL_FILTER_LP,
  MACRO_OSC_SHAPE_DIGITAL_FILTER_PK,
  MACRO_OSC_SHAPE_DIGITAL_FILTER_BP,
  MACRO_OSC_SHAPE_DIGITAL_FILTER_HP,
  MACRO_OSC_SHAPE_VOSIM,
  MACRO_OSC_SHAPE_VOWEL,
  MACRO_OSC_SHAPE_VOWEL_FOF,
  
  MACRO_OSC_SHAPE_HARMONICS,

  MACRO_OSC_SHAPE_FM,
  MACRO_OSC_SHAPE_FEEDBACK_FM,
  MACRO_OSC_SHAPE_CHAOTIC_FEEDBACK_FM,

  MACRO_OSC_SHAPE_PLUCKED,
  MACRO_OSC_SHAPE_BOWED,
  MACRO_OSC_SHAPE_BLOWN,
  MACRO_OSC_SHAPE_FLUTED,
  MACRO_OSC_SHAPE_STRUCK_BELL,
  MACRO_OSC_SHAPE_STRUCK_DRUM,
  MACRO_OSC_SHAPE_KICK,
  MACRO_OSC_SHAPE_CYMBAL,
  MACRO_OSC_SHAPE_SNARE,

  MACRO_OSC_SHAPE_WAVETABLES,
  MACRO_OSC_SHAPE_WAVE_MAP,
  MACRO_OSC_SHAPE_WAVE_LINE,
  MACRO_OSC_SHAPE_WAVE_PARAPHONIC,

  MACRO_OSC_SHAPE_FILTERED_NOISE,
  MACRO_OSC_SHAPE_TWIN_PEAKS_NOISE,
  MACRO_OSC_SHAPE_CLOCKED_NOISE,
  MACRO_OSC_SHAPE_GRANULAR_CLOUD,
  MACRO_OSC_SHAPE_PARTICLE_NOISE,
  
  MACRO_OSC_SHAPE_DIGITAL_MODULATION,

  MACRO_OSC_SHAPE_QUESTION_MARK,
  // MACRO_OSC_SHAPE_YOUR_ALGO
  MACRO_OSC_SHAPE_LAST,
  MACRO_OSC_SHAPE_LAST_ACCESSIBLE_FROM_META = MACRO_OSC_SHAPE_DIGITAL_MODULATION
};

enum Resolution {
  RESOLUTION_2_BIT,
  RESOLUTION_3_BIT,
  RESOLUTION_4_BIT,
  RESOLUTION_6_BIT,
  RESOLUTION_8_BIT,
  RESOLUTION_12_BIT,
  RESOLUTION_16_BIT,
  RESOLUTION_LAST
};

enum SampleRate {
  SAMPLE_RATE_4K,
  SAMPLE_RATE_8K,
  SAMPLE_RATE_16K,
  SAMPLE_RATE_24k,
  SAMPLE_RATE_32k,
  SAMPLE_RATE_48K,
  SAMPLE_RATE_96K,
  SAMPLE_RATE_LAST
};

enum PitchRange {
  PITCH_RANGE_EXTERNAL,
  PITCH_RANGE_FREE,
  PITCH_RANGE_EXTENDED,
  PITCH_RANGE_440,
  PITCH_RANGE_LFO  // This setting is hidden by default!
};

enum Setting {
  SETTING_OSCILLATOR_SHAPE,
  SETTING_RESOLUTION,
  SETTING_SAMPLE_RATE,
  SETTING_AD_TIMBRE,
  SETTING_TRIG_SOURCE,
  SETTING_TRIG_DELAY,
  SETTING_META_MODULATION,
  SETTING_PITCH_RANGE,
  SETTING_PITCH_OCTAVE,
  SETTING_QUANTIZER_SCALE,
  SETTING_VCO_FLATTEN,
  SETTING_VCO_DRIFT,
  SETTING_SIGNATURE,
  SETTING_BRIGHTNESS,
  SETTING_AD_ATTACK,
  SETTING_AD_DECAY,
  SETTING_AD_FM,
  SETTING_AD_COLOR,
  SETTING_AD_VCA,
  SETTING_QUANTIZER_ROOT,
  SETTING_LAST_EDITABLE_SETTING = SETTING_QUANTIZER_ROOT,
  
  // Not settings per-se, but used for menu display!
  SETTING_CALIBRATION,
  SETTING_CV_TESTER,
  SETTING_MARQUEE,
  SETTING_VERSION,
  SETTING_LAST
};

struct SettingsData {
  uint8_t shape;
  uint8_t resolution;
  uint8_t sample_rate;
  uint8_t ad_timbre;
  uint8_t auto_trig;
  uint8_t trig_delay;
  uint8_t meta_modulation;
  uint8_t pitch_range;
  uint8_t pitch_octave;
  uint8_t quantizer_scale;
  uint8_t vco_flatten;
  uint8_t vco_drift;
  uint8_t signature;
  uint8_t brightness;
  uint8_t ad_attack;
  uint8_t ad_decay;
  uint8_t ad_fm;
  uint8_t ad_color;
  uint8_t ad_vca;
  uint8_t quantizer_root;
  
  int32_t pitch_cv_offset;
  int32_t pitch_cv_scale;
  int32_t fm_cv_offset;
  
  int16_t parameter_cv_offset[2];
  uint16_t parameter_cv_scale[2];
  
  char marquee_text[55];
  char magic_byte;
};

struct SettingMetadata {
  uint8_t min_value;
  uint8_t max_value;
  const char name[5];
  const char* const* strings;
  
  int16_t Clip(int16_t value) const {
    if (value > max_value) {
      value = max_value;
    } else if (value < min_value) {
      value = min_value;
    }
    return value;
  }
};
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

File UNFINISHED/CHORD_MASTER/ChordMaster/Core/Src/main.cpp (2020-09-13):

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
/* Includes ------------------------------------------------------------------*/
#include "main.h"

/* USER CODE BEGIN Includes */
#include "multiengine/MainLoop.h"
/* USER CODE END Includes */


void SystemClock_Config(void);
static void MX_GPIO_Init(void);
/**
  * @brief  The application entry point.
  * @retval int
  */
int main(void)
{
  /* MCU Configuration--------------------------------------------------------*/

  /* Reset of all peripherals, Initializes the Flash interface and the Systick. */
  HAL_Init();

  /* Configure the system clock */
  SystemClock_Config();

  /* Initialize all configured peripherals */
  MX_GPIO_Init();
  /* USER CODE BEGIN 2 */
  //ml_init();
  MainLoop ml;
  ml.init();
  /* USER CODE END 2 */

  /* Infinite loop */
  /* USER CODE BEGIN WHILE */
  while (1)
  {
    /* USER CODE END WHILE */
	  ml.loop();
    /* USER CODE BEGIN 3 */
  }
  /* USER CODE END 3 */
}

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


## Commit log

2020-06-21 encoder and tempo. Direction button
    [Scales.ods]
2020-06-21 gates timeouts working
    [Scales.ods]
2020-06-23 leds indications
2020-06-25 MIDI support. incomplete
    [Scales.ods]
2020-06-26 clock divisor button OK
2020-07-18 fix switches NO mode
    [FrontPanel.cpp, Logic.cpp, ios.cpp]
2020-08-01 first commit with all modules information
    [BOM.xls, BOM.xlsx, INDUSTRIAL_KICK_modular.kicad_pcb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]
2020-08-01 external data removed
    [Scales.ods]
2020-08-09 power supply schematic OK
    [power_supply_PCB.kicad_pcb]
2020-08-09 gate trigger does not happen when knob is set to zero in track 0
2020-08-09 Power supply moved to finished. Name fixing for diy files
    [BOM.xls, power_supply_PCB.kicad_pcb, power_supply_PCB.sch]
2020-08-15 adc included.
2020-09-08 Ui class and encoder
2020-09-10 fix scales in sequencer. sound source: calibration state machine OK
    [Display.cpp, MainLoop.cpp, Ui.cpp]
2020-09-13 sound source: fine tune scale and indication. change oscillator update display timings changed
    [Display.cpp, MainLoop.cpp, Ui.cpp]
2020-09-13 sound source: config led at start
2020-09-13 Sound source added to finished projects
    [BOM.xls, SOUND_SOURCE_modular.kicad_pcb, SOUND_SOURCE_modular.sch]
2020-09-16 sound source autotrigger fix
    [MainLoop.cpp]
2020-09-16 sound source async memory write for oscillator selection
    [Memory.cpp, Memory.h, MultiEngineHAL.cpp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]
2020-09-17 sound source fix autotrigger threshold level
    [MainLoop.cpp]
2020-09-17 sound source circuit fix cv anf fm inputs. increase capacitor
    [BOM.xls, SOUND_SOURCE_modular.sch]
2020-09-23 lfo first commit
    [Expo_Table.ods]
2020-09-24 lfo encoder management and leds indications. free and phase mode OK
2020-09-25 LFO project structure updated
    [BOM.xls, Expo_Table.ods, LFO_modular.kicad_pcb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]
2020-09-26 lfox3 manual
    [Expo_Table.ods]
2020-10-03 sound source fix min octave to C2
    [MainLoop.cpp]
2020-10-18 atenuverter and mixer project added
    [ATVMixer_modular.kicad_pcb, ATVMixer_modular.sch, BOM.ods]
2020-11-13 LFOx3 fix mode switch with 3 modes
    [FrontPanel.cpp]
2020-11-14 ATV and mixer OK
    [BOM.ods, BOM.xls]
2020-11-15 simple sequencer project finished
    [BOM.ods, Simple_Sequencer_modular.kicad_pcb, Simple_Sequencer_modular.sch]
2021-05-30 cambio en UI de sound source y chord master
2021-05-30 VCF project
    [BOM.xls, SEQUENCER_modular.sch, VCF_modular_PCB.kicad_pcb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]

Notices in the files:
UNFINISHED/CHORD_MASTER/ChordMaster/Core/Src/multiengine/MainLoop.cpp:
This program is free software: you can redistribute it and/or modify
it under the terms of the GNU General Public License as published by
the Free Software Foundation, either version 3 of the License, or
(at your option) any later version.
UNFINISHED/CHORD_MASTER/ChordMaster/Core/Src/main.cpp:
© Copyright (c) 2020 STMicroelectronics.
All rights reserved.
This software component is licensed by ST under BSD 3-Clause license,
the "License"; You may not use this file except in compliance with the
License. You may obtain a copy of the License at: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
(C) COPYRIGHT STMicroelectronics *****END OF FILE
